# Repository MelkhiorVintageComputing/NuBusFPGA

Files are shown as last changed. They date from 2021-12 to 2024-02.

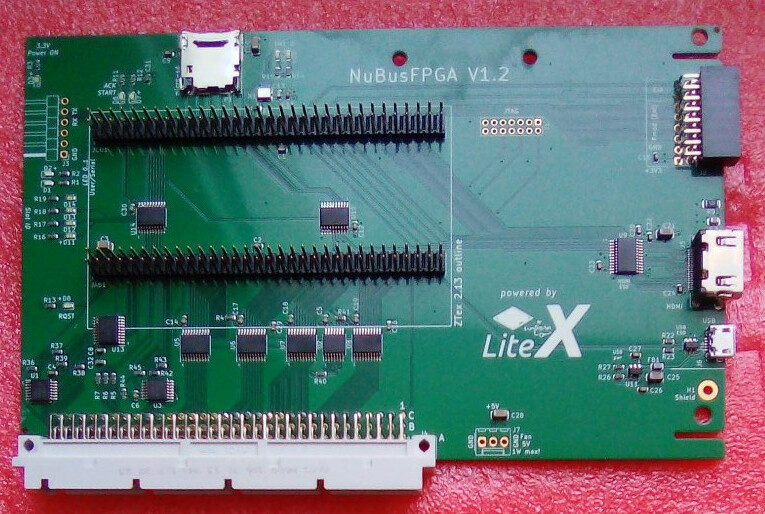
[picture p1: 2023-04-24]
Pictures/NuBusFPGA_V1_2.jpg

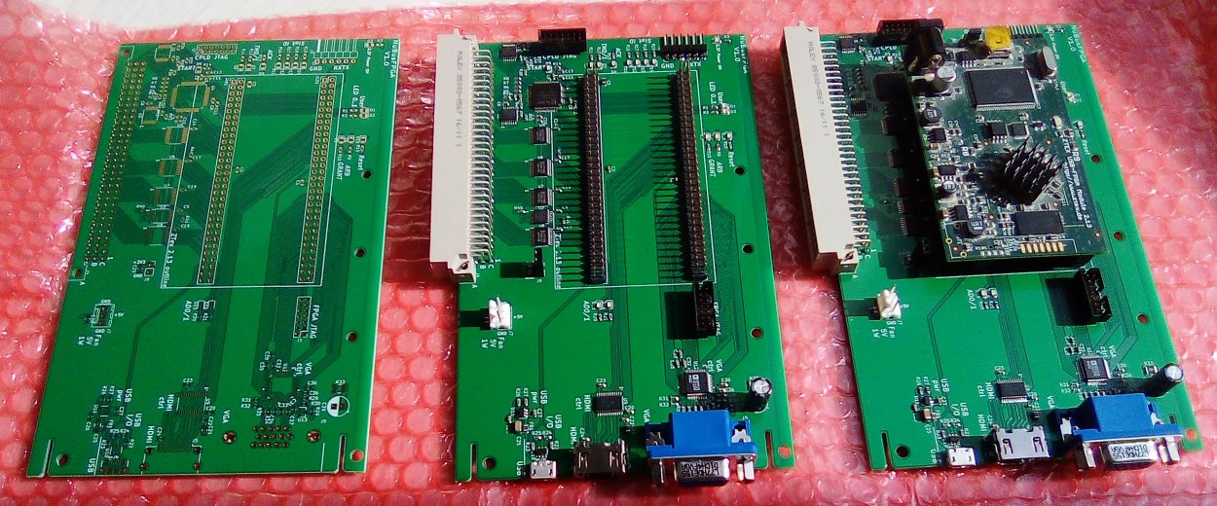
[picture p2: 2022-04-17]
Pictures/NuBusFPGA_V1_0.jpg

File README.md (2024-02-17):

# A FPGA on a NuBus card...

## Goal

The goal of this repository is to be able to interface a modern (2021 era) [FPGA](https://en.wikipedia.org/wiki/Field-programmable_gate_array) with a [NuBus](https://en.wikipedia.org/wiki/NuBus) host, specifically Apple's [Macintosh II](https://en.wikipedia.org/wiki/Macintosh_II_family) and [Macintosh Quadra](https://en.wikipedia.org/wiki/Macintosh_Quadra). NuBus was widely used by Apple and a little by others (such as NeXT), but was progressively displaced by PCI from the mid-90s onward, and is thoroughly obsolete.

So unless you're a retrocomputing enthusiast with such a machine, this is useless. If you are such an enthusiast, then maybe the ability to connect a modern LCD monitor using a digital interface to an old Macintosh might be of interest to you.

This project was 'spun off' the [SBusFPGA](https://github.com/rdolbeau/SBusFPGA), a similar project for the SBus used in Sun's SPARCstation.

## Current status

First prototype is working in a Quadra 650, running MacOS 8.1. It implements a single-screen-resolution, windowboxed multi-resolution, depth-switchable (1/2/4/8/16/32 bits) framebuffer over DVI-in-HDMI-connector (will work with any HDMI-compliant monitor). The framebuffer can be used as secondary/primary/only framebuffer in the machine running OS8.1. Qemu tests indicate this should work with 7.1 & 7.5/7.6 as well. An alternate HDMI PHY also supports audio, enabled as a 8/16 bits, mono/stereo, 44.1 kHz output component in MacOS.

Some basic acceleration now exists for 8/16/32 bits, doing rectangle screen-to-screen blits and pattern rectangle fills. 1/2/4 bits also has some acceleration, but only for byte-aligned cases.

There's also a basic RAM Disk using the 248 MiB of SDRAM not used by the framebuffer. The driver can use either synchronous direct access to the memory by the CPU, or asynchronous using DMA (using 16-bytes blocks). Frustratingly, the direct access methode seems faster.

## The hardware

Directory 'nubus-to-ztex'

The (now obsolete) V1.0 custom board is a NuBus-compliant (I hope...) board, designed to receive a [ZTex USB-FPGA Module 2.13](https://www.ztex.de/usb-fpga-2/usb-fpga-2.13.e.html) as a daughterboard. The ZTex module contains the actual FPGA (Artix-7), some RAM, programming hardware, etc. The NuBus board contains level-shifters & drivers ICs to interface between the NuBus signals and the FPGA, a CPLD handling some level-shifting & the bus mastering arbitration, a serial header, two user Leds, 14 debug Leds tied to specific NuBus or CPLD/FPGA signals, a JTAG header, a USB micro-B connector, a VGA chip & connector, and a HDMI chip & connector. It supports every NuBus feature except the optional parity (i.e. it can do both slave and master modes). The V1.0 board is in commit 3f3371a. The CPLD solution works but is annoying as it requires older Xilinx software (ISE 14.7) and dedicated JTAG programmer to use.

The current board is V1.2. It drops the CPLD and VGA port. Bus arbitration is now done inside the FPGA. It gains a micro-sd slot, and a custom expansion connector that is based (and compatible with, with more signals) PMod. It supports the same accelerated HDMI framebuffer and RAM Disk. Optionally, The Declaration Rom can be stored in a Flash NOR chip connected ot the PMOd expansion connector (easier for working on embedded driver in the DeclRom). The ROM can alternately be stored in a sector of the config flash from the ZTex board on any *FPGA.

The new (July 2023) [ZTex USB-FPGA Module 2.12](https://www.ztex.de/usb-fpga-2/usb-fpga-2.12.e.html) is theoretically compatible with all *FPGA, but at this stage there is some issue when using the 2.12b I own. Some further tests are planned.

The PCBs were designed with Kicad 5.1

## The gateware (Migen)

Directory 'sbus-to-ztex-gateware'

The gateware is written in the Migen language, choosen because that's what [Litex](https://github.com/enjoy-digital/litex/) uses.
It implements a simple CPU-less Litex SoC built around a Wishbone bus, with a custom bridge between the NuBus and the Wishbone.

A Declaration ROM, a SDRAM controller ([litedram](https://github.com/enjoy-digital/litedram) to the on-board DDR3), and the 'Goblin' multi-depth framebuffer can be connected to that bus. Other devices could be added, see the SBusFPGA or the [Common](https://github.com/rdolbeau/VintageBusFPGA_Common) directory, but the software support is missing; vintage System 7/MacOS 8 are not as welcoming to new devices as modern NetBSD. Theoretically, quite a bit of code originally written to support the SBusFPGA in NetBSD/sparc could be reused for similar devices in NetBSD/mac68k, but it has not happened yet.

The SDRAM has its own custom DMA controller, using native Litedram interface to the memory, and some FIFO to/from the NuBus. A custom MacOS driver exposes it as a volatile drive. Driver can use synchronous direct accesses from the CPU (using the NuBus's superslot area), or asynchronous (interrupt-driven) DMA transfers using NuBus 1x block transfers.

## The software

The Declaration ROM is in the subdirectory VintageBusFPGA_Common/DeclROM and includes the driver needed for the unaccelerated framebuffer and the RAM Disk. It needs the [Retro68](https://github.com/autc04/Retro68) toolchain to build.

The code for the NuBusFPGAInit (which should be renamed and enables acceleration) is in NuBusFPGAInit/, and will need a CodeWarrior INIT project to build, on a real Macintosh or an emulated one using e.g. Qemu. It enables graphic acceleration.

The code for the Audio component (which enables audio support over HDMI when using the alternate PHY) is in NuBusFPGAHDMIAudio/.

## FAQ

* Can the framebuffer change resolution ?
 Yes and no. The gateware has a default resolution baked into it that the device will use by default, and can use one of two different physical interface (PHY): the Litex-derived one (which uses DVI signalling) or a more HDMI-like one in verilog. "windowboxed" mode is always availeble, where a smaller esolution is displayed in the middle of the larger screen, which you can select in System 7/MacOS 8 with the Monitor control panel. When using the Litex PHY, some resolution are also available as "hardware" resolution, outputing the appropriate signalling - but the Litex PHY doesn't support audio. The alternate PHY does support audio, but doesn't allow to use a different output resolution, only Full HD (1920x1080) and does support audio output.

* Is Audio supported ?
 Yes and no. a 8 or 16-bits, audio or stereo, 44.1 KHz audio device is available but nly when using the alternate HDMI PHY (see previous question)

* Is USB supported ?
 No. There is a USB connector, but it is currently useless. The gateware could include a USB OHCI host device, and that is supported in the SBusFPGA under NetBSD. However, no Apple OS running on a 68k Mac has any support for USB, so it would require an entire USB stack to be ported, which is a huge undertaking. Also, NuBus is quite a slow bus even by early 2000s standard, and USB OHCI does a lot of DMA all the time, which would use up most if not all (or maybe more than all!) the available bandwidth. There might be some support in NetBSD/mac68k eventually just to test feasibility, but it even there it's unlikely to be useful.

* Is micro-sd supported ?
 Not yet. Hopefully at some point the micro-sd card will be usable as permanent storage in System 7/MacOS 8, but so far it's not working.

* Where is the ROM stored ?
 By default the Declaration ROM is stored inside the FPGA bitstream, so the bitstream must be regenerated for every ROM change. It is possible to store it in a [SPI](https://en.wikipedia.org/wiki/Serial_Peripheral_Interface) Flash NOR chip instead, connected via the expansion connector ([PMod](https://digilent.com/reference/pmod/start)-like) at the back of the NuBusFPGA. My own PMod featuring a SPI Flash NOR and an I2C temperature monitoris available in the [VintageBusFPGA_Common](https://github.com/rdolbeau/VintageBusFPGA_Common) repository, along with an adapter board to program the SPI FLash NOR through the SPI interface of a Raspberry Pi and [flashrom](https://www.flashrom.org/Flashrom).

* Is I2C supported ?
 No. Like USB, I2C doesn't have support in System 7/MacOS 8. It's a lot simpler than USB though. Reading values from a lm75-compatible temperature monitor from System 7/MacOS 8 might be doable, but isn't currently planned. Support for NetBSD/mac68k should be reasonably easy to add as it's already supported in NetBSD/sparc for the SBusFPGA, and unlike USB there's no issue with bandwidth-hungry DMA.

* How about adding Ethernet ?
 Software is the issue. Ethernet is supported by the gateware infrastructure, and a prototype design to add Fast Ethernet via RMII through the expansion connector is available. However, there is currently no software support for it. There's some documentation from Apple, and there's [an example driver available](http://www.mactcp.org.nz/ethernet.html), but the System 7/MacOS 8 driver for LiteEth is still to be written.
 The [SEthernet](https://github.com/rhalkyard/SEthernet) project is a much more likely source of Ethernet for '030-based system.

* Why slow NuBus, when PDS is so much faster ?
 NuBus is well documented, and electrically quite isolated from the rest of the machine. Safer to play with than PDS which is directly connected to the CPU. And the connector for it it still in general use and easy to get. And NuBus is available on multiple generations of machines.
 My primary machine for this is a Quadra 650, with a 68040 and the associated PDS. Unfortunately, the connector for that PDS is near impossible to get nowadadays ([specifications are there](https://tinkerdifferent.com/resources/specifications-for-the-quadra-pds-connector.124/)). '030 PDS uses 120-pins DIN 41612, similar to bur larger than NuBus' 96-pins. They are also available, but less common. But there is a catch - although sharing a connector board-side, the IIsi, SE/30 and IIfx pinouts are slightly different. And the LCIII is completely different.
 Also - see [IIsiFPGA](https://github.com/rdolbeau/IIsiFPGA) and [QuadraFPGA](https://github.com/rdolbeau/QuadraFPGA) :-)

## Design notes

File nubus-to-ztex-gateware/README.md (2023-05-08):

# Compiling

## Rom

Compiling the Declaration Rom (in DeclRom) requires the [Retro68](https://github.com/autc04/Retro68) toolchain.

The beginning of the Makefile in DeclROM/ needs to be adapted to point to the toolchain.

## Microcode for acceleration

Compiling the acceleration code for the Framebuffer requires a RISC-V toolchain.

The script blit_goblin_nubus.sh in VintageBusFPGA_Common/ needs to be adapted to point to the appropriate toolchain.

## Bitstream

Generating the bitstream requires Vivado, 2022 or newer should do. It also requires Litex, see for instance [Linux-on-Litex-VexRiscv](https://github.com/litex-hub/linux-on-litex-vexriscv).

You will need LItex working, and an usable Vivado in yout $PATH.

## Known issues

### dependencies

There's an interesting issue where you need the DeclRom to generate the bitstream (by defualt the Rom is emebedded in it), but you need CSR headers created during the generation of the bitstream to compile the Declaration Rom. A simple workaround is to create a Rom file with a kilobyte or two of fake data, generate the bitstream, then compile the declaration rom, then re-generate the bitsteam with the proper Rom.

### timings

While the main part of the design should be fine in terms of timings, some of the HDMI part isn't. At FullHD resolution (1920x1080 @ 60Hz)), It is 'normal' to have -0.808ns of WPWS, with 9 endpoints failing, in the hdmi5x_clk domain. It doesn't seem to affect the display. This is using the V1.2 54 MHz clock to Bank 34; using the primary 48 MHz clock instead (as in V1.0), the hdmi_clk is a 148.8 MHz instead of 148.5 and the WPPS is -0.811 instead (the 5x clock is at 744 Mhz instead of 742.5 MHz).

### physical

The HDMI connector is low-riding on the PCB. The Mac case gets in the the HDMI plug from the cable, thus pushing the NuBusFPGA slightly out of verticality.

Also when plugging a PMod in the PMod connector, the soldered through-hole pins are dangerously close of the Mac shielding. An extra layer of insulation is recommended to avoid short-circuit.

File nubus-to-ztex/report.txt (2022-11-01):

Info: Front side (top side) place file: “/home/dolbeau/MAC/NuBusFPGA.V1_2/nubus-to-ztex/nubus-to-ztex-top.pos”.
Info: Component count: 88.
Info: Back side (bottom side) place file: “/home/dolbeau/MAC/NuBusFPGA.V1_2/nubus-to-ztex/nubus-to-ztex-bottom.pos”.
Info: Component count: 0.
Info: Full component count: 88

Component Placement File generation OK.

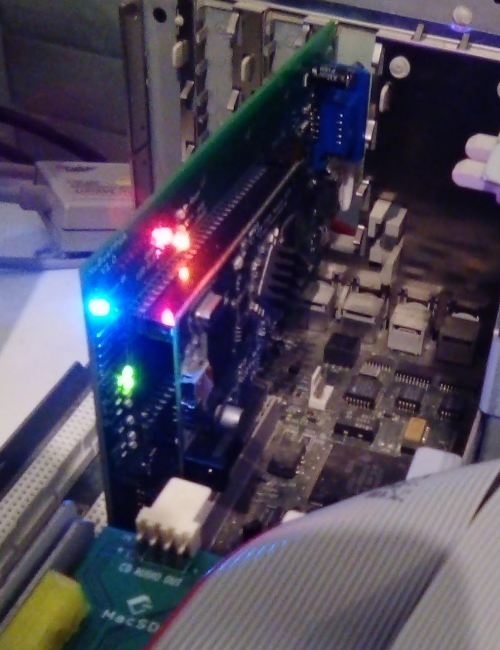
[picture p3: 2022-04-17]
Pictures/NuBusFPGA_V1_0_in_Q650.jpg

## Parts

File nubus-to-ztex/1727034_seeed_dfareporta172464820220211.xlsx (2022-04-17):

Seeed DFA report
Project Name： |  | Prepared by: Qiaoyu Lin |  |  |  | Date: 20220211
Item | Problem description 问题描述 | Reference location 影响位置 | Impact 影响 | Image 图片 | Seeed Suggestion 矽递建议 | Customer feedback 客户反馈 | Severity 严重度 | Status 状态
1 | There is missing the holes in the Gerber | J1,J2 | couldn't be solder in the boards |  | Please update the Gerber to match with the datasheet |  | High | open
2 | The clearance between the holes are not match with the datasheet | J9 | couldn't be solder in the boards |  | Please update the Gerber to match with the datasheet |  | High | open
3 | There is not solder mask layer in the bottom | bottom solder mask layer | couldn't sure how to apply the solder mask oil |  | Please add it in the Gerber |  | High | open
4 |  |  |  |  |  |  | Middle | open
5 |  |  |  |  |  |  | Middle | open
6 |  |  |  |  |  |  | Middle | open
7 |  |  |  |  |  |  | Middle | open
8 |  |  |  |  |  |  | Middle | open

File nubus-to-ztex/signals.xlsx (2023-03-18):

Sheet: Summary
Connector PIN | USB-FPGA-Module 2.13 |  |  |  |  |  |  |  |  |  |  |  |  |  |  |  |  |  |  |  |  |  |  |  |  |  |  |  | LITEX def
 | Signal | I/O Voltage | FPGA PIN | CPLD PIN | Notes | Number |  | Used Pin | Signal | 2.13 trace length (mm) | added length |  |  |  |  |  |  | XDC PIN | XDC TIMING IN | DXC TIMING OUT |  | https://forums.xilinx.com/t5/Timing-Analysis/Significance-of-set-output-delay-max-min-negative-and-positive/td-p/779277
A1 | VIN |  |  |  | 4.5..16V | 1 | #VALUE! | VIN | #VALUE!
B1 | VIN |  |  |  | 4.5..16V | 2 | #VALUE! | VIN | #VALUE! |  |  |  |  |  |  |  |  | TIS (min) → ?? | 48 | 52 | TOD (max) → Ton+Tpd | 22.5 in B0
A2 | GND |  |  |  |  | 3 | #VALUE! | GND | #VALUE! |  |  |  |  |  |  |  | 0 in B0 | TIH (min) → ??? | 2.5 | 7 | TOH (min) → ??? |  | #N/A
B2 | GND |  |  |  |  | 4 | #VALUE! | GND | #VALUE! |  |  |  |  |  |  |  |  |  | mm/ns (fast so MIN) | mm/ns (slow so MAX) |  |  | 0.2161759631
 |  |  |  |  |  |  | #VALUE! |  |  |  |  |  |  |  |  |  |  |  | 200 | 150
A3 | K16~IO_25_15 | VCCO_AB | K16 |  |  | 5 | nmrq_n | K16~IO_25_15 | nmrq_n | 47.94 | #N/A |  | #N/A | #N/A |  | #N/A | IO | set_property PACKAGE_PIN K16 [get_ports {nmrq_n}] set_property IOSTANDARD LVTTL [get_ports {nmrq_n}]
B3 | J18~IO_L23N_T3_FWE_B_15 | VCCO_AB | J18 |  |  | 6 | rqst_n | J18~IO_L23N_T3_FWE_B_15 | rqst_n | 47.46 | 52.47 |  | 99.93 | 3.93 |  | -30.84 | O | set_property PACKAGE_PIN J18 [get_ports {rqst_n}] set_property IOSTANDARD LVTTL [get_ports {rqst_n}] | set_input_delay -clock clk_3v3_n -min 2.404 [get_ports {rqst_n}] set_input_delay -clock clk_3v3_n -max 52.456 [get_ports {rqst_n}] | set_output_delay -clock clk_3v3_n -min -6.155 [get_ports {rqst_n}] set_output_delay -clock clk_3v3_n -max 53.627 [get_ports {rqst_n}] |  | set_output_delay -clock clk_3v3_n -min -6.155 [get_ports {rqst_n}] set_output_delay -clock clk_3v3_n -max 53.627 [get_ports {rqst_n}]
A4 | K15~IO_L24P_T3_RS1_15 | VCCO_AB | K15 |  |  | 7 | start_n | K15~IO_L24P_T3_RS1_15 | start_n | 50.82 | 59.68 |  | 110.50 | 4.35 |  | -41.40 | IO | set_property PACKAGE_PIN K15 [get_ports {start_n}] set_property IOSTANDARD LVTTL [get_ports {start_n}] | set_input_delay -clock clk_3v3_n -min 2.457 [get_ports {start_n}] set_input_delay -clock clk_3v3_n -max 52.526 [get_ports {start_n}] | set_output_delay -clock clk_3v3_n -min -6.102 [get_ports {start_n}] set_output_delay -clock clk_3v3_n -max 53.697 [get_ports {start_n}] |  | set_input_delay -clock clk_3v3_n -min 2.457 [get_ports {start_n}] set_input_delay -clock clk_3v3_n -max 52.526 [get_ports {start_n}] set_output_delay -clock clk_3v3_n -min -6.102 [get_ports {start_n}] set_output_delay -clock clk_3v3_n -max 53.697 [get_ports {start_n}]
B4 | J17~IO_L23P_T3_FOE_B_15 | VCCO_AB | J17 |  |  | 8 | ack_n | J17~IO_L23P_T3_FOE_B_15 | ack_n | 43.6 | 80.52 |  | 124.12 | 4.89 |  | -55.02 | IO | set_property PACKAGE_PIN J17 [get_ports {ack_n}] set_property IOSTANDARD LVTTL [get_ports {ack_n}] | set_input_delay -clock clk_3v3_n -min 2.525 [get_ports {ack_n}] set_input_delay -clock clk_3v3_n -max 52.617 [get_ports {ack_n}] | set_output_delay -clock clk_3v3_n -min -6.034 [get_ports {ack_n}] set_output_delay -clock clk_3v3_n -max 53.788 [get_ports {ack_n}] |  | set_input_delay -clock clk_3v3_n -min 2.525 [get_ports {ack_n}] set_input_delay -clock clk_3v3_n -max 52.617 [get_ports {ack_n}] set_output_delay -clock clk_3v3_n -min -6.034 [get_ports {ack_n}] set_output_delay -clock clk_3v3_n -max 53.788 [get_ports {ack_n}]
A5 | J15~IO_L24N_T3_RS0_15 | VCCO_AB | J15 |  |  | 9 | start_oe_n | J15~IO_L24N_T3_RS0_15 | start_oe_n | 49.92 | #N/A |  | #N/A | #N/A |  | #N/A | IO | set_property PACKAGE_PIN J15 [get_ports {start_oe_n}] set_property IOSTANDARD LVTTL [get_ports {start_oe_n}]
B5 | K13~IO_L17P_T2_A26_15 | VCCO_AB | K13 |  |  | 10 | rqst_o_n | K13~IO_L17P_T2_A26_15 | rqst_o_n | 50.53 | #N/A |  | #N/A | #N/A |  | #N/A | IO | set_property PACKAGE_PIN K13 [get_ports {rqst_o_n}] set_property IOSTANDARD LVTTL [get_ports {rqst_o_n}]
A6 | H15~IO_L19N_T3_A21_VREF_15 | VCCO_AB | H15 |  | VREF Bank 15 | 11 | start_o_n | H15~IO_L19N_T3_A21_VREF_15 | start_o_n | 46.16 | #N/A |  | #N/A | #N/A |  | #N/A | I | set_property PACKAGE_PIN H15 [get_ports {start_o_n}] set_property IOSTANDARD LVTTL [get_ports {start_o_n}]
B6 | J13~IO_L17N_T2_A25_15 | VCCO_AB | J13 |  |  | 12 | ack_oe_n | J13~IO_L17N_T2_A25_15 | ack_oe_n | 43.56 | #N/A |  | #N/A | #N/A |  | #N/A | O | set_property PACKAGE_PIN J13 [get_ports {ack_oe_n}] set_property IOSTANDARD LVTTL [get_ports {ack_oe_n}]
A7 | J14~IO_L19P_T3_A22_15 | VCCO_AB | J14 |  |  | 13 | arb_o_n0 | J14~IO_L19P_T3_A22_15 | arb_o_n0 | 41.01 | #N/A |  | #N/A | #N/A |  | #N/A | IO | set_property PACKAGE_PIN J14 [get_ports {arb_o_n0}] set_property IOSTANDARD LVTTL [get_ports {arb_o_n0}]
B7 | H14~IO_L15P_T2_DQS_15 | VCCO_AB | H14 |  |  | 14 | ack_o_n | H14~IO_L15P_T2_DQS_15 | ack_o_n | 41.18 | #N/A |  | #N/A | #N/A |  | #N/A | IO | set_property PACKAGE_PIN H14 [get_ports {ack_o_n}] set_property IOSTANDARD LVTTL [get_ports {ack_o_n}]
A8 | H17~IO_L18P_T2_A24_15 | VCCO_AB | H17 |  |  | 15 | arb_o_n3 | H17~IO_L18P_T2_A24_15 | arb_o_n3 | 36.34 | #N/A |  | #N/A | #N/A |  | #N/A | IO | set_property PACKAGE_PIN H17 [get_ports {arb_o_n3}] set_property IOSTANDARD LVTTL [get_ports {arb_o_n3}]
B8 | G14~IO_L15N_T2_DQS_ADV_B_15 | VCCO_AB | G14 |  |  | 16 | arb_o_n2 | G14~IO_L15N_T2_DQS_ADV_B_15 | arb_o_n2 | 38.13 | #N/A |  | #N/A | #N/A |  | #N/A | IO | set_property PACKAGE_PIN G14 [get_ports {arb_o_n2}] set_property IOSTANDARD LVTTL [get_ports {arb_o_n2}]
A9 | G17~IO_L18N_T2_A23_15 | VCCO_AB | G17 |  |  | 17 | NUBUS_AD_DIR | G17~IO_L18N_T2_A23_15 | NUBUS_AD_DIR | 35.18 | #N/A |  | #N/A | #N/A |  | #N/A | I | set_property PACKAGE_PIN G17 [get_ports {NUBUS_AD_DIR}] set_property IOSTANDARD LVTTL [get_ports {NUBUS_AD_DIR}]
B9 | G16~IO_L13N_T2_MRCC_15 | VCCO_AB | G16 |  | MRCC | 18 | arb_o_n1 | G16~IO_L13N_T2_MRCC_15 | arb_o_n1 | 33.55 | #N/A |  | #N/A | #N/A |  | #N/A | IO | set_property PACKAGE_PIN G16 [get_ports {arb_o_n1}] set_property IOSTANDARD LVTTL [get_ports {arb_o_n1}]
A10 | G18~IO_L22P_T3_A17_15 | VCCO_AB | G18 |  |  | 19 | ad_n31 | G18~IO_L22P_T3_A17_15 | ad_n31 | 31.47 | 35.03 |  | 66.50 | 2.62 |  | 2.60 | IO | set_property PACKAGE_PIN G18 [get_ports {ad_n31}] set_property IOSTANDARD LVTTL [get_ports {ad_n31}] | set_input_delay -clock clk_3v3_n -min 2.237 [get_ports {ad_n31}] set_input_delay -clock clk_3v3_n -max 52.233 [get_ports {ad_n31}] | set_output_delay -clock clk_3v3_n -min -6.322 [get_ports {ad_n31}] set_output_delay -clock clk_3v3_n -max 53.404 [get_ports {ad_n31}] |  | set_input_delay -clock clk_3v3_n -min 2.237 [get_ports {ad_n31}] set_input_delay -clock clk_3v3_n -max 52.233 [get_ports {ad_n31}] set_output_delay -clock clk_3v3_n -min -6.322 [get_ports {ad_n31}] set_output_delay -clock clk_3v3_n -max 53.404 [get_ports {ad_n31}]
B10 | H16~IO_L13P_T2_MRCC_15 | VCCO_AB | H16 |  | MRCC | 20 | clk_n | H16~IO_L13P_T2_MRCC_15 | clk_n | 30.82 | 38.28 |  | 69.10 | 2.72 |  | 0.00 | I | set_property PACKAGE_PIN H16 [get_ports {clk_n}] set_property IOSTANDARD LVTTL [get_ports {clk_n}] | set_input_delay -clock clk_3v3_n -min 2.250 [get_ports {clk_n}] set_input_delay -clock clk_3v3_n -max 52.250 [get_ports {clk_n}] | set_output_delay -clock clk_3v3_n -min -6.309 [get_ports {clk_n}] set_output_delay -clock clk_3v3_n -max 53.421 [get_ports {clk_n}] |  | set_input_delay -clock clk_3v3_n -min 2.250 [get_ports {clk_n}] set_input_delay -clock clk_3v3_n -max 52.250 [get_ports {clk_n}]
A11 | F18~IO_L22N_T3_A16_15 | VCCO_AB | F18 |  |  | 21 | ad_n29 | F18~IO_L22N_T3_A16_15 | ad_n29 | 29.79 | 35.03 |  | 64.82 | 2.55 |  | 4.28 | IO | set_property PACKAGE_PIN F18 [get_ports {ad_n29}] set_property IOSTANDARD LVTTL [get_ports {ad_n29}] | set_input_delay -clock clk_3v3_n -min 2.229 [get_ports {ad_n29}] set_input_delay -clock clk_3v3_n -max 52.221 [get_ports {ad_n29}] | set_output_delay -clock clk_3v3_n -min -6.330 [get_ports {ad_n29}] set_output_delay -clock clk_3v3_n -max 53.393 [get_ports {ad_n29}] |  | set_input_delay -clock clk_3v3_n -min 2.229 [get_ports {ad_n29}] set_input_delay -clock clk_3v3_n -max 52.221 [get_ports {ad_n29}] set_output_delay -clock clk_3v3_n -min -6.330 [get_ports {ad_n29}] set_output_delay -clock clk_3v3_n -max 53.393 [get_ports {ad_n29}]
B11 | F16~IO_L14N_T2_SRCC_15 | VCCO_AB | F16 |  | SRCC | 22 | ad_n30 | F16~IO_L14N_T2_SRCC_15 | ad_n30 | 42.85 | 32.71 |  | 75.56 | 2.97 |  | -6.46 | IO | set_property PACKAGE_PIN F16 [get_ports {ad_n30}] set_property IOSTANDARD LVTTL [get_ports {ad_n30}] | set_input_delay -clock clk_3v3_n -min 2.282 [get_ports {ad_n30}] set_input_delay -clock clk_3v3_n -max 52.293 [get_ports {ad_n30}] | set_output_delay -clock clk_3v3_n -min -6.277 [get_ports {ad_n30}] set_output_delay -clock clk_3v3_n -max 53.464 [get_ports {ad_n30}] |  | set_input_delay -clock clk_3v3_n -min 2.282 [get_ports {ad_n30}] set_input_delay -clock clk_3v3_n -max 52.293 [get_ports {ad_n30}] set_output_delay -clock clk_3v3_n -min -6.277 [get_ports {ad_n30}] set_output_delay -clock clk_3v3_n -max 53.464 [get_ports {ad_n30}]
A12 | E18~IO_L21P_T3_DQS_15 | VCCO_AB | E18 |  |  | 23 | ad_n27 | E18~IO_L21P_T3_DQS_15 | ad_n27 | 28.44 | 35.41 |  | 63.85 | 2.51 |  | 5.25 | IO | set_property PACKAGE_PIN E18 [get_ports {ad_n27}] set_property IOSTANDARD LVTTL [get_ports {ad_n27}] | set_input_delay -clock clk_3v3_n -min 2.224 [get_ports {ad_n27}] set_input_delay -clock clk_3v3_n -max 52.215 [get_ports {ad_n27}] | set_output_delay -clock clk_3v3_n -min -6.335 [get_ports {ad_n27}] set_output_delay -clock clk_3v3_n -max 53.386 [get_ports {ad_n27}] |  | set_input_delay -clock clk_3v3_n -min 2.224 [get_ports {ad_n27}] set_input_delay -clock clk_3v3_n -max 52.215 [get_ports {ad_n27}] set_output_delay -clock clk_3v3_n -min -6.335 [get_ports {ad_n27}] set_output_delay -clock clk_3v3_n -max 53.386 [get_ports {ad_n27}]
B12 | F15~IO_L14P_T2_SRCC_15 | VCCO_AB | F15 |  | SRCC | 24 | ad_n28 | F15~IO_L14P_T2_SRCC_15 | ad_n28 | 26.76 | 32.71 |  | 59.47 | 2.34 |  | 9.63 | IO | set_property PACKAGE_PIN F15 [get_ports {ad_n28}] set_property IOSTANDARD LVTTL [get_ports {ad_n28}] | set_input_delay -clock clk_3v3_n -min 2.202 [get_ports {ad_n28}] set_input_delay -clock clk_3v3_n -max 52.186 [get_ports {ad_n28}] | set_output_delay -clock clk_3v3_n -min -6.357 [get_ports {ad_n28}] set_output_delay -clock clk_3v3_n -max 53.357 [get_ports {ad_n28}] |  | set_input_delay -clock clk_3v3_n -min 2.202 [get_ports {ad_n28}] set_input_delay -clock clk_3v3_n -max 52.186 [get_ports {ad_n28}] set_output_delay -clock clk_3v3_n -min -6.357 [get_ports {ad_n28}] set_output_delay -clock clk_3v3_n -max 53.357 [get_ports {ad_n28}]
A13 | D18~IO_L21N_T3_DQS_A18_15 | VCCO_AB | D18 |  |  | 25 | ad_n25 | D18~IO_L21N_T3_DQS_A18_15 | ad_n25 | 25.47 | 36.46 |  | 61.93 | 2.44 |  | 7.17 | IO | set_property PACKAGE_PIN D18 [get_ports {ad_n25}] set_property IOSTANDARD LVTTL [get_ports {ad_n25}] | set_input_delay -clock clk_3v3_n -min 2.214 [get_ports {ad_n25}] set_input_delay -clock clk_3v3_n -max 52.202 [get_ports {ad_n25}] | set_output_delay -clock clk_3v3_n -min -6.345 [get_ports {ad_n25}] set_output_delay -clock clk_3v3_n -max 53.374 [get_ports {ad_n25}] |  | set_input_delay -clock clk_3v3_n -min 2.214 [get_ports {ad_n25}] set_input_delay -clock clk_3v3_n -max 52.202 [get_ports {ad_n25}] set_output_delay -clock clk_3v3_n -min -6.345 [get_ports {ad_n25}] set_output_delay -clock clk_3v3_n -max 53.374 [get_ports {ad_n25}]
B13 | E17~IO_L16P_T2_A28_15 | VCCO_AB | E17 |  |  | 26 | ad_n26 | E17~IO_L16P_T2_A28_15 | ad_n26 | 23.54 | 33.39 |  | 56.93 | 2.24 |  | 12.17 | IO | set_property PACKAGE_PIN E17 [get_ports {ad_n26}] set_property IOSTANDARD LVTTL [get_ports {ad_n26}] | set_input_delay -clock clk_3v3_n -min 2.189 [get_ports {ad_n26}] set_input_delay -clock clk_3v3_n -max 52.169 [get_ports {ad_n26}] | set_output_delay -clock clk_3v3_n -min -6.370 [get_ports {ad_n26}] set_output_delay -clock clk_3v3_n -max 53.340 [get_ports {ad_n26}] |  | set_input_delay -clock clk_3v3_n -min 2.189 [get_ports {ad_n26}] set_input_delay -clock clk_3v3_n -max 52.169 [get_ports {ad_n26}] set_output_delay -clock clk_3v3_n -min -6.370 [get_ports {ad_n26}] set_output_delay -clock clk_3v3_n -max 53.340 [get_ports {ad_n26}]
A14 | G13~IO_0_15 | VCCO_AB | G13 |  |  | 27 | nubus_oe | G13~IO_0_15 | nubus_oe | 33.51 | #N/A |  | #N/A | #N/A |  | #N/A | IO | set_property PACKAGE_PIN G13 [get_ports {nubus_oe }] set_property IOSTANDARD LVTTL [get_ports {nubus_oe }]
B14 | D17~IO_L16N_T2_A27_15 | VCCO_AB | D17 |  |  | 28 | ad_n24 | D17~IO_L16N_T2_A27_15 | ad_n24 | 21.66 | 34.44 |  | 56.10 | 2.21 |  | 12.99 | IO | set_property PACKAGE_PIN D17 [get_ports {ad_n24}] set_property IOSTANDARD LVTTL [get_ports {ad_n24}] | set_input_delay -clock clk_3v3_n -min 2.185 [get_ports {ad_n24}] set_input_delay -clock clk_3v3_n -max 52.163 [get_ports {ad_n24}] | set_output_delay -clock clk_3v3_n -min -6.374 [get_ports {ad_n24}] set_output_delay -clock clk_3v3_n -max 53.335 [get_ports {ad_n24}] |  | set_input_delay -clock clk_3v3_n -min 2.185 [get_ports {ad_n24}] set_input_delay -clock clk_3v3_n -max 52.163 [get_ports {ad_n24}] set_output_delay -clock clk_3v3_n -min -6.374 [get_ports {ad_n24}] set_output_delay -clock clk_3v3_n -max 53.335 [get_ports {ad_n24}]
A15 | 3.3V |  |  |  |  | 29 |  | 3.3V | 0 |  | #N/A |  |  | 0.00 |  |  |  | set_property PACKAGE_PIN [get_ports {0}] set_property IOSTANDARD LVTTL [get_ports {0}]
B15 | 3.3V |  |  |  |  | 30 | #VALUE! | 3.3V | #VALUE! |  | #VALUE! |  |  | 0.00 |  |  |  | #VALUE! | #VALUE! | #VALUE! |  |  |  |  |  |  |  |  | #VALUE!
A16 | GND |  |  |  |  | 31 | #VALUE! | GND | #VALUE! |  | #VALUE! |  |  | 0.00 |  |  |  | #VALUE! | #VALUE! | #VALUE! |  |  |  |  |  |  |  |  | #VALUE!
B16 | GND |  |  |  |  | 32 | #VALUE! | GND | #VALUE! |  | #VALUE! |  |  | 0.00 |  |  |  | #VALUE! | #VALUE! | #VALUE! |  |  |  |  |  |  |  |  | #VALUE!
A17 | VCCO_AB |  |  |  | default: 3.3V output, if R8 removed: 1.2V .. 3.3V input | 33 | #VALUE! | VCCO_AB | #VALUE! |  | #VALUE! |  |  | 0.00 |  |  |  | #VALUE! | #VALUE! | #VALUE! |  |  |  |  |  |  |  |  | #VALUE!
B17 | VCCO_AB |  |  |  | default: 3.3V output, if R8 removed: 1.2V .. 3.3V input | 34 | #VALUE! | VCCO_AB | #VALUE! |  | #VALUE! |  |  | 0.00 |  |  |  | #VALUE! | #VALUE! | #VALUE! |  |  |  |  |  |  |  |  | #VALUE!
A18 | F13~IO_L5P_T0_AD9P_15 | VCCO_AB | F13 |  |  | 35 | ad_n23 | F13~IO_L5P_T0_AD9P_15 | ad_n23 | 19.12 | 38.45 |  | 57.57 | 2.27 |  | 11.53 | IO | set_property PACKAGE_PIN F13 [get_ports {ad_n23}] set_property IOSTANDARD LVTTL [get_ports {ad_n23}] | set_input_delay -clock clk_3v3_n -min 2.192 [get_ports {ad_n23}] set_input_delay -clock clk_3v3_n -max 52.173 [get_ports {ad_n23}] | set_output_delay -clock clk_3v3_n -min -6.367 [get_ports {ad_n23}] set_output_delay -clock clk_3v3_n -max 53.344 [get_ports {ad_n23}] |  | set_input_delay -clock clk_3v3_n -min 2.192 [get_ports {ad_n23}] set_input_delay -clock clk_3v3_n -max 52.173 [get_ports {ad_n23}] set_output_delay -clock clk_3v3_n -min -6.367 [get_ports {ad_n23}] set_output_delay -clock clk_3v3_n -max 53.344 [get_ports {ad_n23}]
B18 | F14~IO_L5N_T0_AD9N_15 | VCCO_AB | F14 |  |  | 36 | ad_n22 | F14~IO_L5N_T0_AD9N_15 | ad_n22 | 12.94 | 35.86 |  | 48.80 | 1.92 |  | 20.30 | IO | set_property PACKAGE_PIN F14 [get_ports {ad_n22}] set_property IOSTANDARD LVTTL [get_ports {ad_n22}] | set_input_delay -clock clk_3v3_n -min 2.149 [get_ports {ad_n22}] set_input_delay -clock clk_3v3_n -max 52.115 [get_ports {ad_n22}] | set_output_delay -clock clk_3v3_n -min -6.410 [get_ports {ad_n22}] set_output_delay -clock clk_3v3_n -max 53.286 [get_ports {ad_n22}] |  | set_input_delay -clock clk_3v3_n -min 2.149 [get_ports {ad_n22}] set_input_delay -clock clk_3v3_n -max 52.115 [get_ports {ad_n22}] set_output_delay -clock clk_3v3_n -min -6.410 [get_ports {ad_n22}] set_output_delay -clock clk_3v3_n -max 53.286 [get_ports {ad_n22}]
A19 | E16~IO_L11N_T1_SRCC_15 | VCCO_AB | E16 |  | SRCC | 37 | ad_n21 | E16~IO_L11N_T1_SRCC_15 | ad_n21 | 16.11 | 38.36 |  | 54.47 | 2.14 |  | 14.63 | IO | set_property PACKAGE_PIN E16 [get_ports {ad_n21}] set_property IOSTANDARD LVTTL [get_ports {ad_n21}] | set_input_delay -clock clk_3v3_n -min 2.177 [get_ports {ad_n21}] set_input_delay -clock clk_3v3_n -max 52.152 [get_ports {ad_n21}] | set_output_delay -clock clk_3v3_n -min -6.382 [get_ports {ad_n21}] set_output_delay -clock clk_3v3_n -max 53.324 [get_ports {ad_n21}] |  | set_input_delay -clock clk_3v3_n -min 2.177 [get_ports {ad_n21}] set_input_delay -clock clk_3v3_n -max 52.152 [get_ports {ad_n21}] set_output_delay -clock clk_3v3_n -min -6.382 [get_ports {ad_n21}] set_output_delay -clock clk_3v3_n -max 53.324 [get_ports {ad_n21}]
B19 | E15~IO_L11P_T1_SRCC_15 | VCCO_AB | E15 |  | SRCC | 38 | ad_n20 | E15~IO_L11P_T1_SRCC_15 | ad_n20 | 10.5 | 35.86 |  | 46.36 | 1.83 |  | 22.74 | IO | set_property PACKAGE_PIN E15 [get_ports {ad_n20}] set_property IOSTANDARD LVTTL [get_ports {ad_n20}] | set_input_delay -clock clk_3v3_n -min 2.136 [get_ports {ad_n20}] set_input_delay -clock clk_3v3_n -max 52.098 [get_ports {ad_n20}] | set_output_delay -clock clk_3v3_n -min -6.423 [get_ports {ad_n20}] set_output_delay -clock clk_3v3_n -max 53.270 [get_ports {ad_n20}] |  | set_input_delay -clock clk_3v3_n -min 2.136 [get_ports {ad_n20}] set_input_delay -clock clk_3v3_n -max 52.098 [get_ports {ad_n20}] set_output_delay -clock clk_3v3_n -min -6.423 [get_ports {ad_n20}] set_output_delay -clock clk_3v3_n -max 53.270 [get_ports {ad_n20}]
A20 | C17~IO_L20N_T3_A19_15 | VCCO_AB | C17 |  |  | 39 | ad_n19 | C17~IO_L20N_T3_A19_15 | ad_n19 | 12.52 | 38.40 |  | 50.92 | 2.00 |  | 18.18 | IO | set_property PACKAGE_PIN C17 [get_ports {ad_n19}] set_property IOSTANDARD LVTTL [get_ports {ad_n19}] | set_input_delay -clock clk_3v3_n -min 2.159 [get_ports {ad_n19}] set_input_delay -clock clk_3v3_n -max 52.129 [get_ports {ad_n19}] | set_output_delay -clock clk_3v3_n -min -6.400 [get_ports {ad_n19}] set_output_delay -clock clk_3v3_n -max 53.300 [get_ports {ad_n19}] |  | set_input_delay -clock clk_3v3_n -min 2.159 [get_ports {ad_n19}] set_input_delay -clock clk_3v3_n -max 52.129 [get_ports {ad_n19}] set_output_delay -clock clk_3v3_n -min -6.400 [get_ports {ad_n19}] set_output_delay -clock clk_3v3_n -max 53.300 [get_ports {ad_n19}]
B20 | C16~IO_L20P_T3_A20_15 | VCCO_AB | C16 |  |  | 40 | ad_n18 | C16~IO_L20P_T3_A20_15 | ad_n18 | 7.79 | 35.86 |  | 43.65 | 1.72 |  | 25.45 | IO | set_property PACKAGE_PIN C16 [get_ports {ad_n18}] set_property IOSTANDARD LVTTL [get_ports {ad_n18}] | set_input_delay -clock clk_3v3_n -min 2.123 [get_ports {ad_n18}] set_input_delay -clock clk_3v3_n -max 52.080 [get_ports {ad_n18}] | set_output_delay -clock clk_3v3_n -min -6.436 [get_ports {ad_n18}] set_output_delay -clock clk_3v3_n -max 53.252 [get_ports {ad_n18}] |  | set_input_delay -clock clk_3v3_n -min 2.123 [get_ports {ad_n18}] set_input_delay -clock clk_3v3_n -max 52.080 [get_ports {ad_n18}] set_output_delay -clock clk_3v3_n -min -6.436 [get_ports {ad_n18}] set_output_delay -clock clk_3v3_n -max 53.252 [get_ports {ad_n18}]
A21 | A18~IO_L10N_T1_AD11N_15 | VCCO_AB | A18 | q |  | 41 | ad_n17 | A18~IO_L10N_T1_AD11N_15 | ad_n17 | 11.42 | 38.62 |  | 50.04 | 1.97 |  | 19.06 | IO | set_property PACKAGE_PIN A18 [get_ports {ad_n17}] set_property IOSTANDARD LVTTL [get_ports {ad_n17}] | set_input_delay -clock clk_3v3_n -min 2.155 [get_ports {ad_n17}] set_input_delay -clock clk_3v3_n -max 52.123 [get_ports {ad_n17}] | set_output_delay -clock clk_3v3_n -min -6.404 [get_ports {ad_n17}] set_output_delay -clock clk_3v3_n -max 53.294 [get_ports {ad_n17}] |  | set_input_delay -clock clk_3v3_n -min 2.155 [get_ports {ad_n17}] set_input_delay -clock clk_3v3_n -max 52.123 [get_ports {ad_n17}] set_output_delay -clock clk_3v3_n -min -6.404 [get_ports {ad_n17}] set_output_delay -clock clk_3v3_n -max 53.294 [get_ports {ad_n17}]
B21 | B18~IO_L10P_T1_AD11P_15 | VCCO_AB | B18 |  |  | 42 | ad_n16 | B18~IO_L10P_T1_AD11P_15 | ad_n16 | 4.99 | 35.86 |  | 40.85 | 1.61 |  | 28.25 | IO | set_property PACKAGE_PIN B18 [get_ports {ad_n16}] set_property IOSTANDARD LVTTL [get_ports {ad_n16}] | set_input_delay -clock clk_3v3_n -min 2.109 [get_ports {ad_n16}] set_input_delay -clock clk_3v3_n -max 52.062 [get_ports {ad_n16}] | set_output_delay -clock clk_3v3_n -min -6.450 [get_ports {ad_n16}] set_output_delay -clock clk_3v3_n -max 53.233 [get_ports {ad_n16}] |  | set_input_delay -clock clk_3v3_n -min 2.109 [get_ports {ad_n16}] set_input_delay -clock clk_3v3_n -max 52.062 [get_ports {ad_n16}] set_output_delay -clock clk_3v3_n -min -6.450 [get_ports {ad_n16}] set_output_delay -clock clk_3v3_n -max 53.233 [get_ports {ad_n16}]
A22 | C15~IO_L12N_T1_MRCC_15 | VCCO_AB | C15 |  | MRCC | 43 | ad_n15 | C15~IO_L12N_T1_MRCC_15 | ad_n15 | 16.17 | 38.11 |  | 54.28 | 2.14 |  | 14.82 | IO | set_property PACKAGE_PIN C15 [get_ports {ad_n15}] set_property IOSTANDARD LVTTL [get_ports {ad_n15}] | set_input_delay -clock clk_3v3_n -min 2.176 [get_ports {ad_n15}] set_input_delay -clock clk_3v3_n -max 52.151 [get_ports {ad_n15}] | set_output_delay -clock clk_3v3_n -min -6.383 [get_ports {ad_n15}] set_output_delay -clock clk_3v3_n -max 53.322 [get_ports {ad_n15}] |  | set_input_delay -clock clk_3v3_n -min 2.176 [get_ports {ad_n15}] set_input_delay -clock clk_3v3_n -max 52.151 [get_ports {ad_n15}] set_output_delay -clock clk_3v3_n -min -6.383 [get_ports {ad_n15}] set_output_delay -clock clk_3v3_n -max 53.322 [get_ports {ad_n15}]
B22 | D15~IO_L12P_T1_MRCC_15 | VCCO_AB | D15 |  | MRCC | 44 | ad_n14 | D15~IO_L12P_T1_MRCC_15 | ad_n14 | 7.67 | 35.57 |  | 43.24 | 1.70 |  | 25.86 | IO | set_property PACKAGE_PIN D15 [get_ports {ad_n14}] set_property IOSTANDARD LVTTL [get_ports {ad_n14}] | set_input_delay -clock clk_3v3_n -min 2.121 [get_ports {ad_n14}] set_input_delay -clock clk_3v3_n -max 52.078 [get_ports {ad_n14}] | set_output_delay -clock clk_3v3_n -min -6.438 [get_ports {ad_n14}] set_output_delay -clock clk_3v3_n -max 53.249 [get_ports {ad_n14}] |  | set_input_delay -clock clk_3v3_n -min 2.121 [get_ports {ad_n14}] set_input_delay -clock clk_3v3_n -max 52.078 [get_ports {ad_n14}] set_output_delay -clock clk_3v3_n -min -6.438 [get_ports {ad_n14}] set_output_delay -clock clk_3v3_n -max 53.249 [get_ports {ad_n14}]
A23 | B17~IO_L7N_T1_AD2N_15 | VCCO_AB | B17 |  |  | 45 | ad_n13 | B17~IO_L7N_T1_AD2N_15 | ad_n13 | 12.65 | 38.11 |  | 50.76 | 2.00 |  | 18.34 | IO | set_property PACKAGE_PIN B17 [get_ports {ad_n13}] set_property IOSTANDARD LVTTL [get_ports {ad_n13}] | set_input_delay -clock clk_3v3_n -min 2.158 [get_ports {ad_n13}] set_input_delay -clock clk_3v3_n -max 52.128 [get_ports {ad_n13}] | set_output_delay -clock clk_3v3_n -min -6.401 [get_ports {ad_n13}] set_output_delay -clock clk_3v3_n -max 53.299 [get_ports {ad_n13}] |  | set_input_delay -clock clk_3v3_n -min 2.158 [get_ports {ad_n13}] set_input_delay -clock clk_3v3_n -max 52.128 [get_ports {ad_n13}] set_output_delay -clock clk_3v3_n -min -6.401 [get_ports {ad_n13}] set_output_delay -clock clk_3v3_n -max 53.299 [get_ports {ad_n13}]
B23 | B16~IO_L7P_T1_AD2P_15 | VCCO_AB | B16 |  |  | 46 | ad_n12 | B16~IO_L7P_T1_AD2P_15 | ad_n12 | 6.56 | 35.57 |  | 42.13 | 1.66 |  | 26.97 | IO | set_property PACKAGE_PIN B16 [get_ports {ad_n12}] set_property IOSTANDARD LVTTL [get_ports {ad_n12}] | set_input_delay -clock clk_3v3_n -min 2.115 [get_ports {ad_n12}] set_input_delay -clock clk_3v3_n -max 52.070 [get_ports {ad_n12}] | set_output_delay -clock clk_3v3_n -min -6.444 [get_ports {ad_n12}] set_output_delay -clock clk_3v3_n -max 53.241 [get_ports {ad_n12}] |  | set_input_delay -clock clk_3v3_n -min 2.115 [get_ports {ad_n12}] set_input_delay -clock clk_3v3_n -max 52.070 [get_ports {ad_n12}] set_output_delay -clock clk_3v3_n -min -6.444 [get_ports {ad_n12}] set_output_delay -clock clk_3v3_n -max 53.241 [get_ports {ad_n12}]
A24 | C14~IO_L1N_T0_AD0N_15 | VCCO_AB | C14 |  |  | 47 | ad_n11 | C14~IO_L1N_T0_AD0N_15 | ad_n11 | 16.68 | 38.11 |  | 54.79 | 2.16 |  | 14.31 | IO | set_property PACKAGE_PIN C14 [get_ports {ad_n11}] set_property IOSTANDARD LVTTL [get_ports {ad_n11}] | set_input_delay -clock clk_3v3_n -min 2.178 [get_ports {ad_n11}] set_input_delay -clock clk_3v3_n -max 52.155 [get_ports {ad_n11}] | set_output_delay -clock clk_3v3_n -min -6.381 [get_ports {ad_n11}] set_output_delay -clock clk_3v3_n -max 53.326 [get_ports {ad_n11}] |  | set_input_delay -clock clk_3v3_n -min 2.178 [get_ports {ad_n11}] set_input_delay -clock clk_3v3_n -max 52.155 [get_ports {ad_n11}] set_output_delay -clock clk_3v3_n -min -6.381 [get_ports {ad_n11}] set_output_delay -clock clk_3v3_n -max 53.326 [get_ports {ad_n11}]
B24 | D14~IO_L1P_T0_AD0P_15 | VCCO_AB | D14 |  |  | 48 | ad_n10 | D14~IO_L1P_T0_AD0P_15 | ad_n10 | 9.37 | 35.57 |  | 44.94 | 1.77 |  | 24.16 | IO | set_property PACKAGE_PIN D14 [get_ports {ad_n10}] set_property IOSTANDARD LVTTL [get_ports {ad_n10}] | set_input_delay -clock clk_3v3_n -min 2.129 [get_ports {ad_n10}] set_input_delay -clock clk_3v3_n -max 52.089 [get_ports {ad_n10}] | set_output_delay -clock clk_3v3_n -min -6.430 [get_ports {ad_n10}] set_output_delay -clock clk_3v3_n -max 53.260 [get_ports {ad_n10}] |  | set_input_delay -clock clk_3v3_n -min 2.129 [get_ports {ad_n10}] set_input_delay -clock clk_3v3_n -max 52.089 [get_ports {ad_n10}] set_output_delay -clock clk_3v3_n -min -6.430 [get_ports {ad_n10}] set_output_delay -clock clk_3v3_n -max 53.260 [get_ports {ad_n10}]
A25 | D13~IO_L6N_T0_VREF_15 | VCCO_AB | D13 |  | VREF Bank 15 | 49 | ad_n9 | D13~IO_L6N_T0_VREF_15 | ad_n9 | 18.84 | 38.11 |  | 56.95 | 2.24 |  | 12.15 | IO | set_property PACKAGE_PIN D13 [get_ports {ad_n9}] set_property IOSTANDARD LVTTL [get_ports {ad_n9}] | set_input_delay -clock clk_3v3_n -min 2.189 [get_ports {ad_n9}] set_input_delay -clock clk_3v3_n -max 52.169 [get_ports {ad_n9}] | set_output_delay -clock clk_3v3_n -min -6.370 [get_ports {ad_n9}] set_output_delay -clock clk_3v3_n -max 53.340 [get_ports {ad_n9}] |  | set_input_delay -clock clk_3v3_n -min 2.189 [get_ports {ad_n9}] set_input_delay -clock clk_3v3_n -max 52.169 [get_ports {ad_n9}] set_output_delay -clock clk_3v3_n -min -6.370 [get_ports {ad_n9}] set_output_delay -clock clk_3v3_n -max 53.340 [get_ports {ad_n9}]
B25 | D12~IO_L6P_T0_15 | VCCO_AB | D12 |  |  | 50 | ad_n8 | D12~IO_L6P_T0_15 | ad_n8 | 11.32 | 35.57 |  | 46.89 | 1.85 |  | 22.21 | IO | set_property PACKAGE_PIN D12 [get_ports {ad_n8}] set_property IOSTANDARD LVTTL [get_ports {ad_n8}] | set_input_delay -clock clk_3v3_n -min 2.139 [get_ports {ad_n8}] set_input_delay -clock clk_3v3_n -max 52.102 [get_ports {ad_n8}] | set_output_delay -clock clk_3v3_n -min -6.420 [get_ports {ad_n8}] set_output_delay -clock clk_3v3_n -max 53.273 [get_ports {ad_n8}] |  | set_input_delay -clock clk_3v3_n -min 2.139 [get_ports {ad_n8}] set_input_delay -clock clk_3v3_n -max 52.102 [get_ports {ad_n8}] set_output_delay -clock clk_3v3_n -min -6.420 [get_ports {ad_n8}] set_output_delay -clock clk_3v3_n -max 53.273 [get_ports {ad_n8}]
A26 | A16~IO_L8N_T1_AD10N_15 | VCCO_AB | A16 |  |  | 51 | ad_n7 | A16~IO_L8N_T1_AD10N_15 | ad_n7 | 14.67 | 38.11 |  | 52.78 | 2.08 |  | 16.32 | IO | set_property PACKAGE_PIN A16 [get_ports {ad_n7}] set_property IOSTANDARD LVTTL [get_ports {ad_n7}] | set_input_delay -clock clk_3v3_n -min 2.168 [get_ports {ad_n7}] set_input_delay -clock clk_3v3_n -max 52.141 [get_ports {ad_n7}] | set_output_delay -clock clk_3v3_n -min -6.391 [get_ports {ad_n7}] set_output_delay -clock clk_3v3_n -max 53.312 [get_ports {ad_n7}] |  | set_input_delay -clock clk_3v3_n -min 2.168 [get_ports {ad_n7}] set_input_delay -clock clk_3v3_n -max 52.141 [get_ports {ad_n7}] set_output_delay -clock clk_3v3_n -min -6.391 [get_ports {ad_n7}] set_output_delay -clock clk_3v3_n -max 53.312 [get_ports {ad_n7}]
B26 | A15~IO_L8P_T1_AD10P_15 | VCCO_AB | A15 |  |  | 52 | ad_n6 | A15~IO_L8P_T1_AD10P_15 | ad_n6 | 10.64 | 35.57 |  | 46.21 | 1.82 |  | 22.89 | IO | set_property PACKAGE_PIN A15 [get_ports {ad_n6}] set_property IOSTANDARD LVTTL [get_ports {ad_n6}] | set_input_delay -clock clk_3v3_n -min 2.136 [get_ports {ad_n6}] set_input_delay -clock clk_3v3_n -max 52.097 [get_ports {ad_n6}] | set_output_delay -clock clk_3v3_n -min -6.423 [get_ports {ad_n6}] set_output_delay -clock clk_3v3_n -max 53.269 [get_ports {ad_n6}] |  | set_input_delay -clock clk_3v3_n -min 2.136 [get_ports {ad_n6}] set_input_delay -clock clk_3v3_n -max 52.097 [get_ports {ad_n6}] set_output_delay -clock clk_3v3_n -min -6.423 [get_ports {ad_n6}] set_output_delay -clock clk_3v3_n -max 53.269 [get_ports {ad_n6}]
A27 | B14~IO_L2N_T0_AD8N_15 | VCCO_AB | B14 |  |  | 53 | ad_n5 | B14~IO_L2N_T0_AD8N_15 | ad_n5 | 17.14 | 38.11 |  | 55.25 | 2.18 |  | 13.85 | IO | set_property PACKAGE_PIN B14 [get_ports {ad_n5}] set_property IOSTANDARD LVTTL [get_ports {ad_n5}] | set_input_delay -clock clk_3v3_n -min 2.181 [get_ports {ad_n5}] set_input_delay -clock clk_3v3_n -max 52.158 [get_ports {ad_n5}] | set_output_delay -clock clk_3v3_n -min -6.378 [get_ports {ad_n5}] set_output_delay -clock clk_3v3_n -max 53.329 [get_ports {ad_n5}] |  | set_input_delay -clock clk_3v3_n -min 2.181 [get_ports {ad_n5}] set_input_delay -clock clk_3v3_n -max 52.158 [get_ports {ad_n5}] set_output_delay -clock clk_3v3_n -min -6.378 [get_ports {ad_n5}] set_output_delay -clock clk_3v3_n -max 53.329 [get_ports {ad_n5}]
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

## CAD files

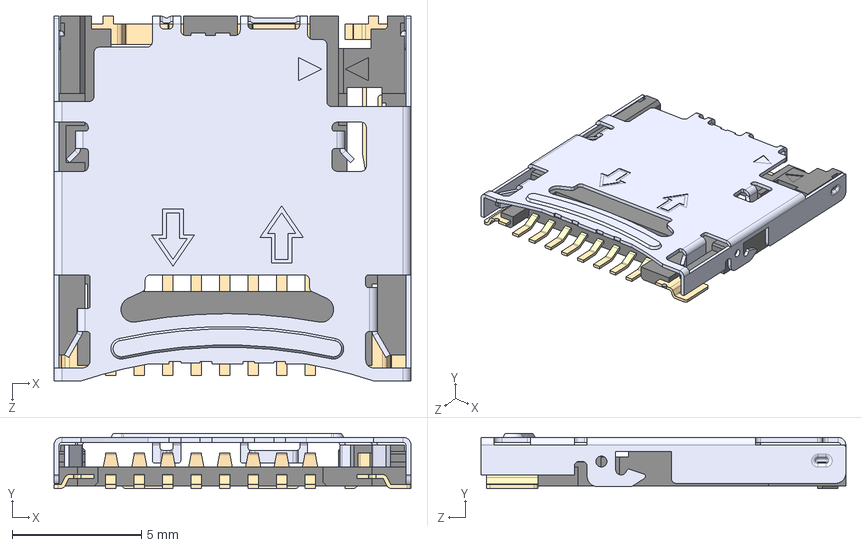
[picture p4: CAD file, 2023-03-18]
nubus-to-ztex/DM3CS-SF.step
13.8 x 2.13 x 14.1 mm

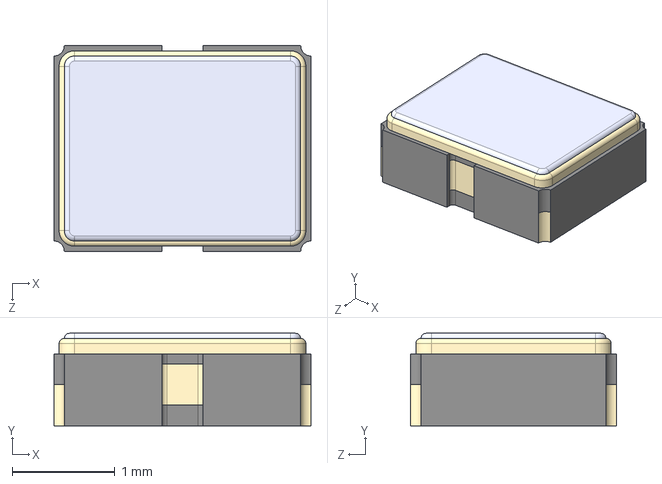
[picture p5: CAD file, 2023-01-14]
nubus-to-ztex/ECS-2520MV-250-CN-TR.STEP
2.50 x 0.9 x 2.00 mm

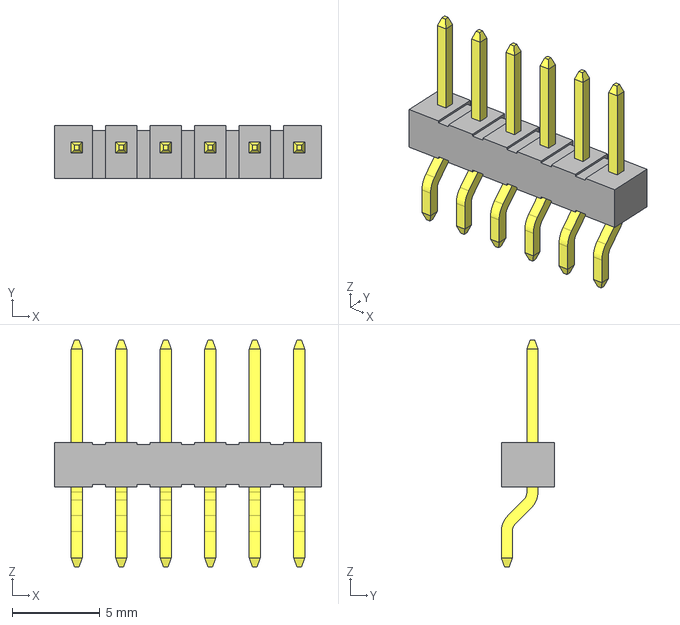
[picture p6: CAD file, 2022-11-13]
nubus-to-ztex/TSM-106-01-L-SH.step
15.2 x 3.05 x 13.0 mm
T-1S6-08(-01-6-SH)
TSM-106-01-SH_body

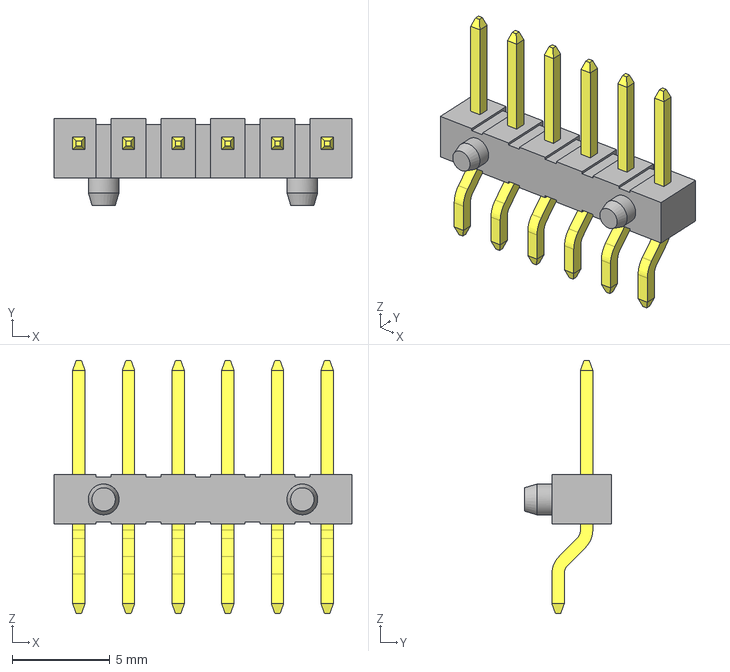
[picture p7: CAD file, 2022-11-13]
nubus-to-ztex/TSM-106-01-T-SH-A.step
15.2 x 4.44 x 13.0 mm
T-1S6-08(-01-6-SH)
TSM-106-01-SH-A_body

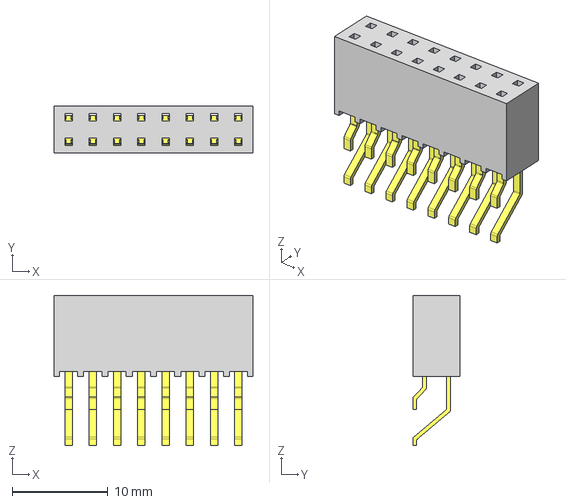
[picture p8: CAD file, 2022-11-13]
nubus-to-ztex/SAMTEC-SMH-108-02-X-D.step
20.8 x 4.95 x 15.7 mm
C-08-03-08-D_SMH
SMH-108-D_socket

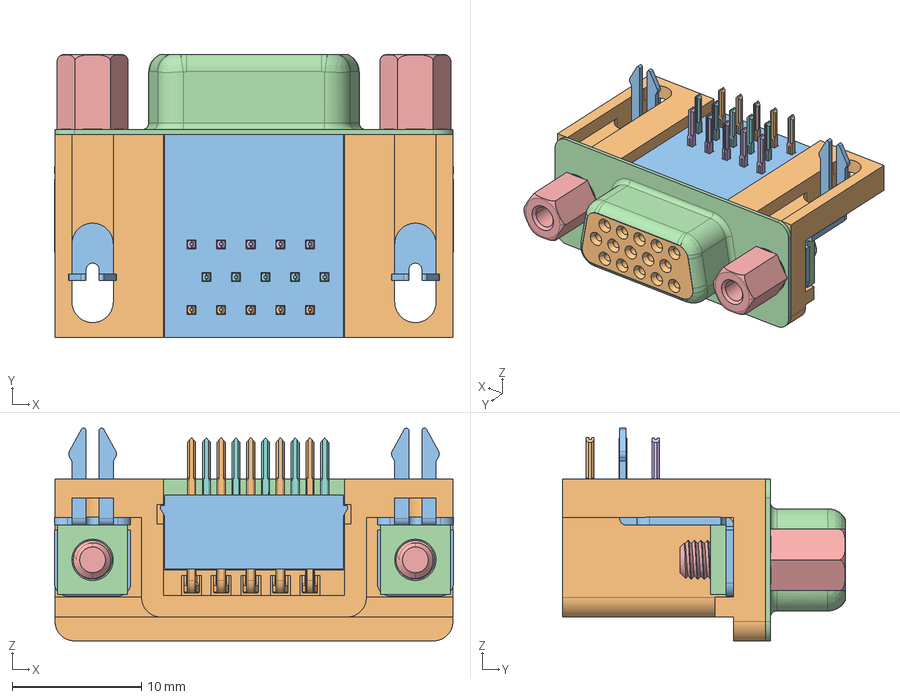
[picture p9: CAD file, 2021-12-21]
nubus-to-ztex/L77HDE15SD1CH4F--3DModel-STEP-533217.STEP
30.9 x 21.9 x 16.5 mm
D112-H15S
ZZ x 2
MM x 2
T3 x 5
T2 x 5
T1 x 5
CC
H15S-SHEL

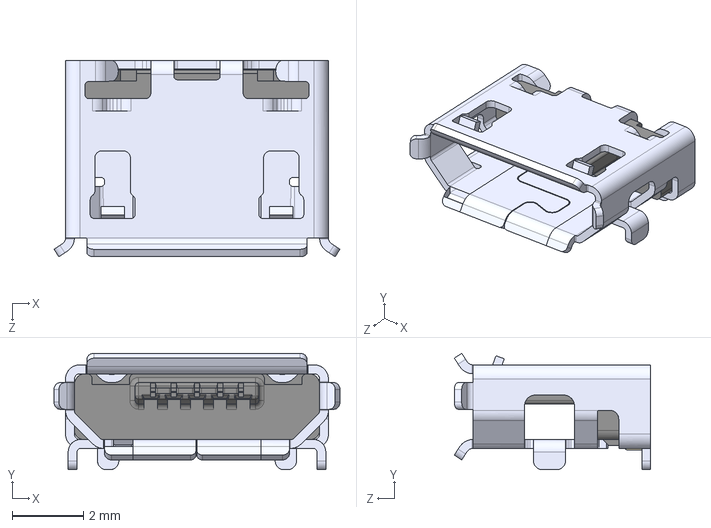
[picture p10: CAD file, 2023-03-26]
nubus-to-ztex/10118194-0001LF--3DModel-STEP-269445.STEP
8.05 x 3.27 x 5.53 mm

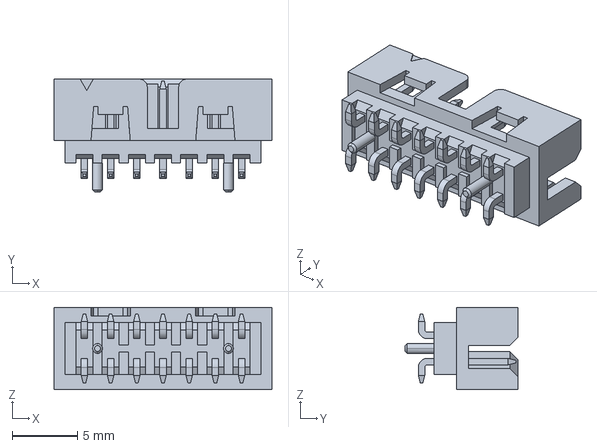
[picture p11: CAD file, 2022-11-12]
nubus-to-ztex/87832-1420.stp
16.6 x 8.60 x 6.30 mm

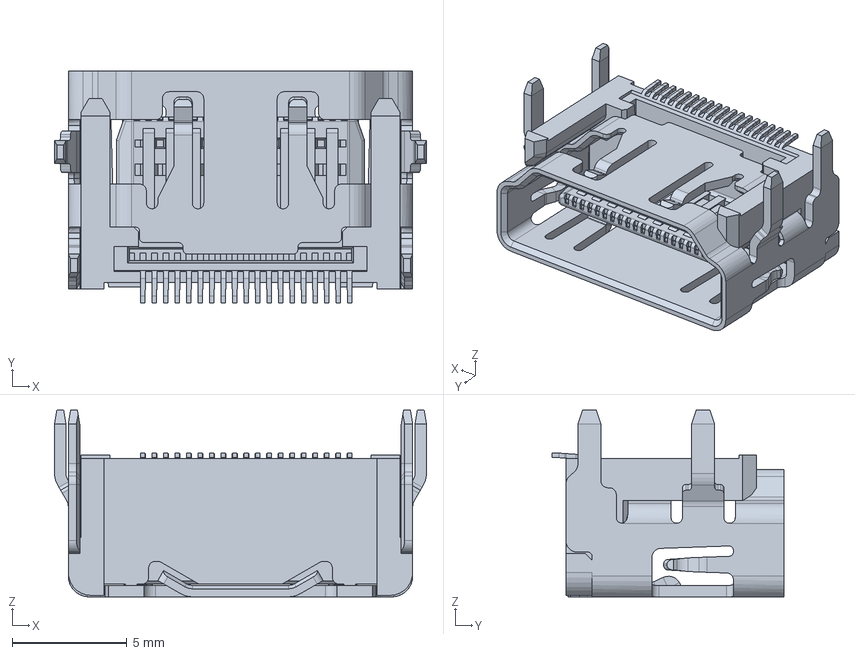
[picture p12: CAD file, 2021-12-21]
nubus-to-ztex/10029449-111RLF.stp
16.2 x 10.1 x 8.13 mm

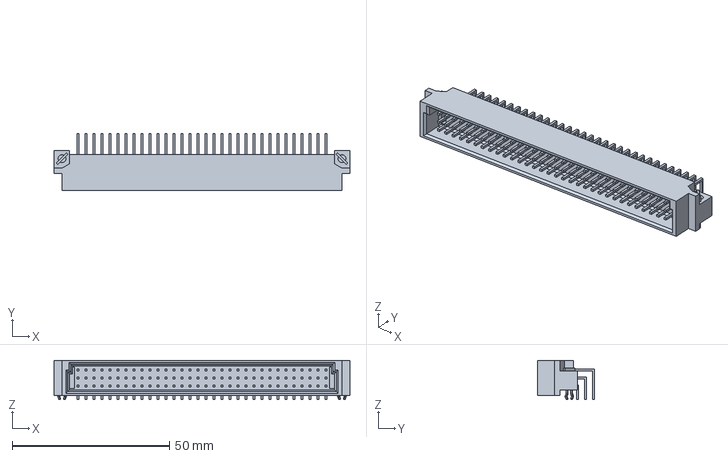
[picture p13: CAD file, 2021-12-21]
nubus-to-ztex/850030567.stp
94.0 x 18.1 x 12.4 mm

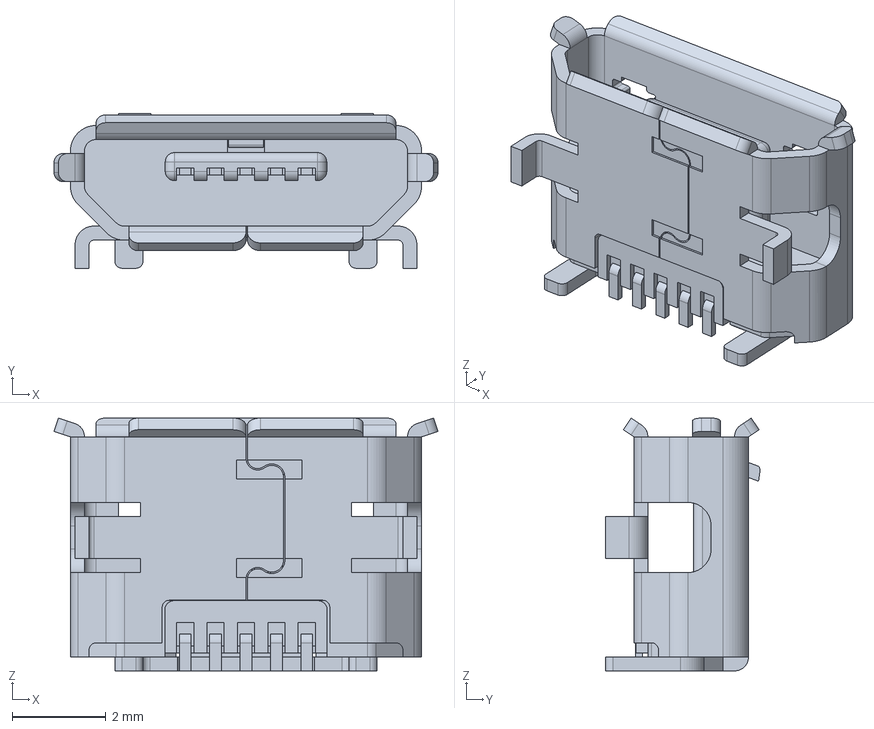
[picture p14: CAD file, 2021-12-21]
nubus-to-ztex/1050170001.stp
8.20 x 3.30 x 5.40 mm

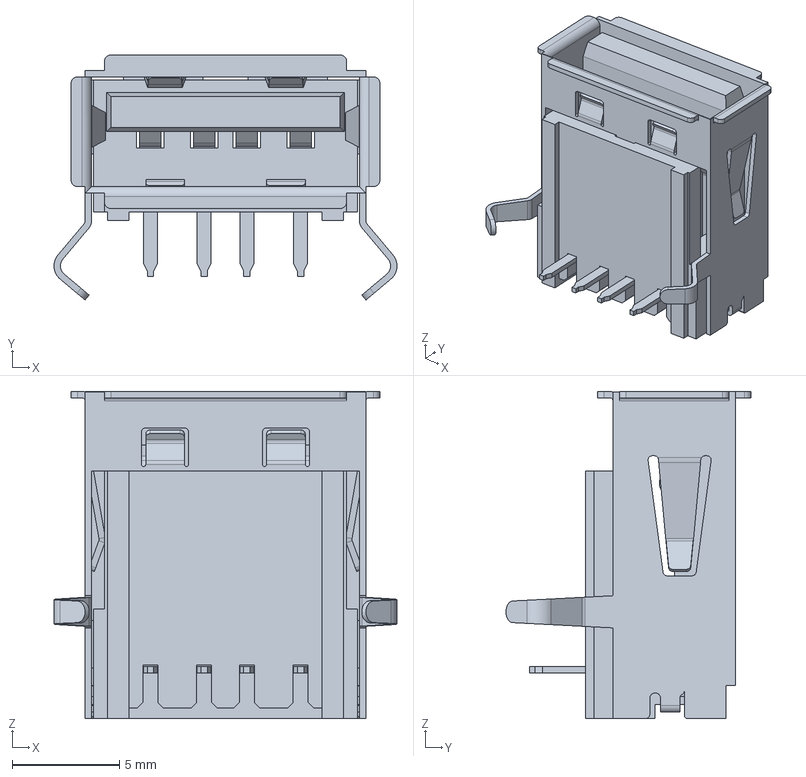
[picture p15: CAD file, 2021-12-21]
nubus-to-ztex/676432911.stp
16.0 x 11.4 x 15.3 mm

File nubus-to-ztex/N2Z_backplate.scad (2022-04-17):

THICKNESS_MAX=2.44;
THICKNESS=2.4;

ORIGINAL_THICKNESS=25.4/32;

NUBUS_HEIGHT_BELOW_OUTER_LIP=92; // NuBus p57, max is 97.25
NUBUS_HEIGHT_ABOVE_OUTER_LIP=6; // NuBus p57

NUBUS_BETWEEN_NOTCHES=87.25; // DCDMF3 p625 & p635, bottom of low to top of high?
NUBUS_HIGH_NOTCH_TO_TOP=10.35;// DCDMF3 p635, top of high to bottom of inner lip ?

NUBUS_BASE_WIDTH=18.57;
NUBUS_EXTRA_WIDTH=2.93;
NUBUS_FULL_WIDTH=NUBUS_BASE_WIDTH+NUBUS_EXTRA_WIDTH;
NUBUS_TOP_WIDTH=21.82;
NUBUS_OVERHANG_WIDTH=NUBUS_TOP_WIDTH-NUBUS_BASE_WIDTH;
NUBUS_EXTRA_FROM_TOP=20.5;
NUBUS_ANGLE_SECTION_LACK_OF_WIDTH=2.57;
NUBUS_ANGLE_SECTION_WIDTH_REDUCTION=NUBUS_EXTRA_WIDTH+NUBUS_ANGLE_SECTION_LACK_OF_WIDTH;

NUBUS_HEIGHT_NARROW_BOTTOM_TO_TOP=94.6;
NUBUS_FULL_HEIGHT=(NUBUS_BETWEEN_NOTCHES+NUBUS_HIGH_NOTCH_TO_TOP);
NUBUS_NARROW_BOTTOM_HEIGHT=NUBUS_FULL_HEIGHT-NUBUS_HEIGHT_NARROW_BOTTOM_TO_TOP;

NUBUS_EXTRA_NARROW_BOTTOM=1.5;

NUBUS_OVERHANG_MIN_HEIGHT=8.4;
NUBUS_OVERHANG_MAX_HEIGHT=12.18;
NUBUS_OVERHANG_RADIUS=3.2;
NUBUS_TOP_BIT_WIDTH=9.57-2.57;

FRONT_NOTCH_FROM_TOP=85.9;
FRONT_NOTCH_STRAIGHT_WIDTH=2;
FRONT_NOTCH_STRAIGHT_HEIGHT=6;
FRONT_NOTCH_ANGLE_HEIGHT=(NUBUS_BETWEEN_NOTCHES+NUBUS_HIGH_NOTCH_TO_TOP)-(FRONT_NOTCH_FROM_TOP+FRONT_NOTCH_STRAIGHT_HEIGHT);
FRONT_NOTCH_ANGLE_WIDTH=FRONT_NOTCH_ANGLE_HEIGHT*sin(23);

points=[[0,0],
        [NUBUS_BASE_WIDTH-7.82-FRONT_NOTCH_STRAIGHT_WIDTH/2-FRONT_NOTCH_ANGLE_WIDTH,0],
        [NUBUS_BASE_WIDTH-7.82-FRONT_NOTCH_STRAIGHT_WIDTH/2,FRONT_NOTCH_ANGLE_HEIGHT],
        [NUBUS_BASE_WIDTH-7.82-FRONT_NOTCH_STRAIGHT_WIDTH/2,FRONT_NOTCH_ANGLE_HEIGHT+FRONT_NOTCH_STRAIGHT_HEIGHT],
        [NUBUS_BASE_WIDTH-7.82+FRONT_NOTCH_STRAIGHT_WIDTH/2,FRONT_NOTCH_ANGLE_HEIGHT+FRONT_NOTCH_STRAIGHT_HEIGHT],
        [NUBUS_BASE_WIDTH-7.82+FRONT_NOTCH_STRAIGHT_WIDTH/2,FRONT_NOTCH_ANGLE_HEIGHT],
        [NUBUS_BASE_WIDTH-7.82+FRONT_NOTCH_STRAIGHT_WIDTH/2+FRONT_NOTCH_ANGLE_WIDTH,0],
        [NUBUS_BASE_WIDTH-NUBUS_EXTRA_NARROW_BOTTOM,0],
        
        [NUBUS_BASE_WIDTH-NUBUS_EXTRA_NARROW_BOTTOM,NUBUS_NARROW_BOTTOM_HEIGHT],
        [NUBUS_FULL_WIDTH,NUBUS_NARROW_BOTTOM_HEIGHT],
        [NUBUS_FULL_WIDTH,NUBUS_FULL_HEIGHT-NUBUS_EXTRA_FROM_TOP],
        [NUBUS_FULL_WIDTH-NUBUS_ANGLE_SECTION_WIDTH_REDUCTION,(NUBUS_FULL_HEIGHT-NUBUS_EXTRA_FROM_TOP)+(NUBUS_ANGLE_SECTION_WIDTH_REDUCTION*2)],
        [NUBUS_FULL_WIDTH-NUBUS_ANGLE_SECTION_WIDTH_REDUCTION,NUBUS_FULL_HEIGHT+ORIGINAL_THICKNESS],
        [NUBUS_FULL_WIDTH-NUBUS_ANGLE_SECTION_WIDTH_REDUCTION-NUBUS_TOP_BIT_WIDTH,NUBUS_FULL_HEIGHT+ORIGINAL_THICKNESS],
        [NUBUS_FULL_WIDTH-NUBUS_ANGLE_SECTION_WIDTH_REDUCTION-NUBUS_TOP_BIT_WIDTH,NUBUS_FULL_HEIGHT+ORIGINAL_THICKNESS-6], //6: measurement
        [NUBUS_FULL_WIDTH-NUBUS_ANGLE_SECTION_WIDTH_REDUCTION-NUBUS_TOP_BIT_WIDTH-2,NUBUS_FULL_HEIGHT+ORIGINAL_THICKNESS-6], //2&6: measurement
        [NUBUS_FULL_WIDTH-NUBUS_ANGLE_SECTION_WIDTH_REDUCTION-NUBUS_TOP_BIT_WIDTH-2,NUBUS_FULL_HEIGHT+ORIGINAL_THICKNESS-NUBUS_HIGH_NOTCH_TO_TOP+5], // 5 is the diustance between top notch and top screw hole
        [-NUBUS_OVERHANG_WIDTH,NUBUS_FULL_HEIGHT+ORIGINAL_THICKNESS-NUBUS_HIGH_NOTCH_TO_TOP+5],
        [-NUBUS_OVERHANG_WIDTH,NUBUS_FULL_HEIGHT-NUBUS_OVERHANG_MAX_HEIGHT+NUBUS_OVERHANG_RADIUS],
        [0,NUBUS_FULL_HEIGHT-NUBUS_OVERHANG_MAX_HEIGHT]        
];

module backplate() {
linear_extrude(height = ORIGINAL_THICKNESS, center = true) { polygon(points); };
}

// PCB, don't print
PCB_THICKNESS=1.6;
PCB_OFFSET=(NUBUS_FULL_WIDTH-2.93)-PCB_THICKNESS/2;
module pcb() {
    color("green") translate([PCB_OFFSET,0,-50]) linear_extrude(height = 100, center = true) { polygon ([[-PCB_THICKNESS,-5.08],[0,-5.08],[0,91.52],[-PCB_THICKNESS,91.52]]); };
}

// NuBusFPGA
BOTTOM_HOLE_Y=8-1.08;
TOP_HOLE_Y=87.52;
FIRST_HOLE_X=-6.44;
SECOND_HOLE_X=-16.44;

module holders() {
difference() {
union() {
color("red") translate([0,0,-11]) linear_extrude(height = 22, center = true) { polygon([
    [PCB_OFFSET-PCB_THICKNESS,BOTTOM_HOLE_Y-4],
    [PCB_OFFSET-PCB_THICKNESS,BOTTOM_HOLE_Y+4],
    [PCB_OFFSET-PCB_THICKNESS-2,BOTTOM_HOLE_Y+4],
    [PCB_OFFSET-PCB_THICKNESS-2,BOTTOM_HOLE_Y-4],
    ]); };
color("red") translate([0,0,-11]) linear_extrude(height = 22, center = true) { polygon([
    [PCB_OFFSET-PCB_THICKNESS,TOP_HOLE_Y-4],
    [PCB_OFFSET-PCB_THICKNESS,TOP_HOLE_Y+4],
    [PCB_OFFSET-PCB_THICKNESS-2,TOP_HOLE_Y+4],
    [PCB_OFFSET-PCB_THICKNESS-2,TOP_HOLE_Y-4],
    ]); };
}
union() { 
color("blue") translate([0,BOTTOM_HOLE_Y,FIRST_HOLE_X]) rotate([0,90,0]) cylinder(r1=1.6,r2=1.6,h=20);
color("blue") translate([0,BOTTOM_HOLE_Y,SECOND_HOLE_X]) rotate([0,90,0]) cylinder(r1=1.6,r2=1.6,h=20);
color("blue") translate([0,TOP_HOLE_Y,FIRST_HOLE_X]) rotate([0,90,0]) cylinder(r1=1.6,r2=1.6,h=20);
color("blue") translate([0,TOP_HOLE_Y,SECOND_HOLE_X]) rotate([0,90,0]) cylinder(r1=1.6,r2=1.6,h=20);
}
}
}


//cube ([16.5+4, 12, 9.5+4 /* 14.8 max */], center = true);
USB_HOLDER_HEIGHT=5;
USB_HOLDER_WIDTH=10;
USB_HOLDER_DEPTH=5;
module usb_pos() {
translate([-1-USB_HOLDER_HEIGHT/2+PCB_OFFSET-PCB_THICKNESS,100-(74.67+(83.47-74.67)/2),-USB_HOLDER_DEPTH/2]) cube([2+USB_HOLDER_HEIGHT,2+USB_HOLDER_WIDTH,USB_HOLDER_DEPTH], center = true);
}
module usb_neg() {
translate([-0.499-USB_HOLDER_HEIGHT/2+PCB_OFFSET-PCB_THICKNESS,100-(74.67+(83.47-74.67)/2),-USB_HOLDER_DEPTH/2]) cube([1.001+USB_HOLDER_HEIGHT,USB_HOLDER_WIDTH,USB_HOLDER_DEPTH*4], center = true);
}

VGA_HOLDER_HEIGHT=14.8;
VGA_HOLDER_WIDTH=31.8;
VGA_HOLDER_DEPTH=2;
module vga_pos() {
    translate([-VGA_HOLDER_HEIGHT/2+PCB_OFFSET-PCB_THICKNESS,100-(18.21+(49.05-18.21)/2),-VGA_HOLDER_DEPTH/2+VGA_HOLDER_DEPTH]) cube ([VGA_HOLDER_HEIGHT, 6+VGA_HOLDER_WIDTH, VGA_HOLDER_DEPTH], center = true);
}
module vga_neg() {
    translate([-VGA_HOLDER_HEIGHT/2+PCB_OFFSET-PCB_THICKNESS,100-(18.21+(49.05-18.21)/2),-VGA_HOLDER_DEPTH/2]) cube ([10, 18, 10+0.001], center = true);
    
    
    translate([-VGA_HOLDER_HEIGHT/2+PCB_OFFSET-PCB_THICKNESS,100-(18.21+(49.05-18.21)/2)-12.5,-VGA_HOLDER_DEPTH/2]) color("black") rotate([0,0,90]) cylinder (h = 10, r1 = 1.6, r2 = 1.6, center = true);
    translate([-VGA_HOLDER_HEIGHT/2+PCB_OFFSET-PCB_THICKNESS,100-(18.21+(49.05-18.21)/2)+12.5,-VGA_HOLDER_DEPTH/2]) color("black") rotate([0,0,90]) cylinder (h = 10, r1 = 1.6, r2 = 1.6, center = true);
}

HDMI_HOLDER_HEIGHT=8;
HDMI_HOLDER_WIDTH=18;
HDMI_HOLDER_DEPTH=2;
module hdmi_pos() {
    translate([-1-HDMI_HOLDER_HEIGHT/2+PCB_OFFSET-PCB_THICKNESS,100-(53.3+(71.3-53.3)/2),-HDMI_HOLDER_DEPTH/2]) cube ([2+HDMI_HOLDER_HEIGHT, 2+HDMI_HOLDER_WIDTH, HDMI_HOLDER_DEPTH], center = true);
}
module hdmi_neg() {
    translate([-0.499-HDMI_HOLDER_HEIGHT/2+PCB_OFFSET-PCB_THICKNESS,100-(53.3+(71.3-53.3)/2),-HDMI_HOLDER_DEPTH/2]) cube ([1.001+HDMI_HOLDER_HEIGHT, HDMI_HOLDER_WIDTH, 5+0.001], center = true);
}

//pcb();

module complete() {
    difference() {
        union() {
            backplate();
            holders();
            usb_pos();
            vga_pos();
            hdmi_pos();
        }
        union() {
            usb_neg();
            vga_neg();
            hdmi_neg();
        }
    }
}

complete();

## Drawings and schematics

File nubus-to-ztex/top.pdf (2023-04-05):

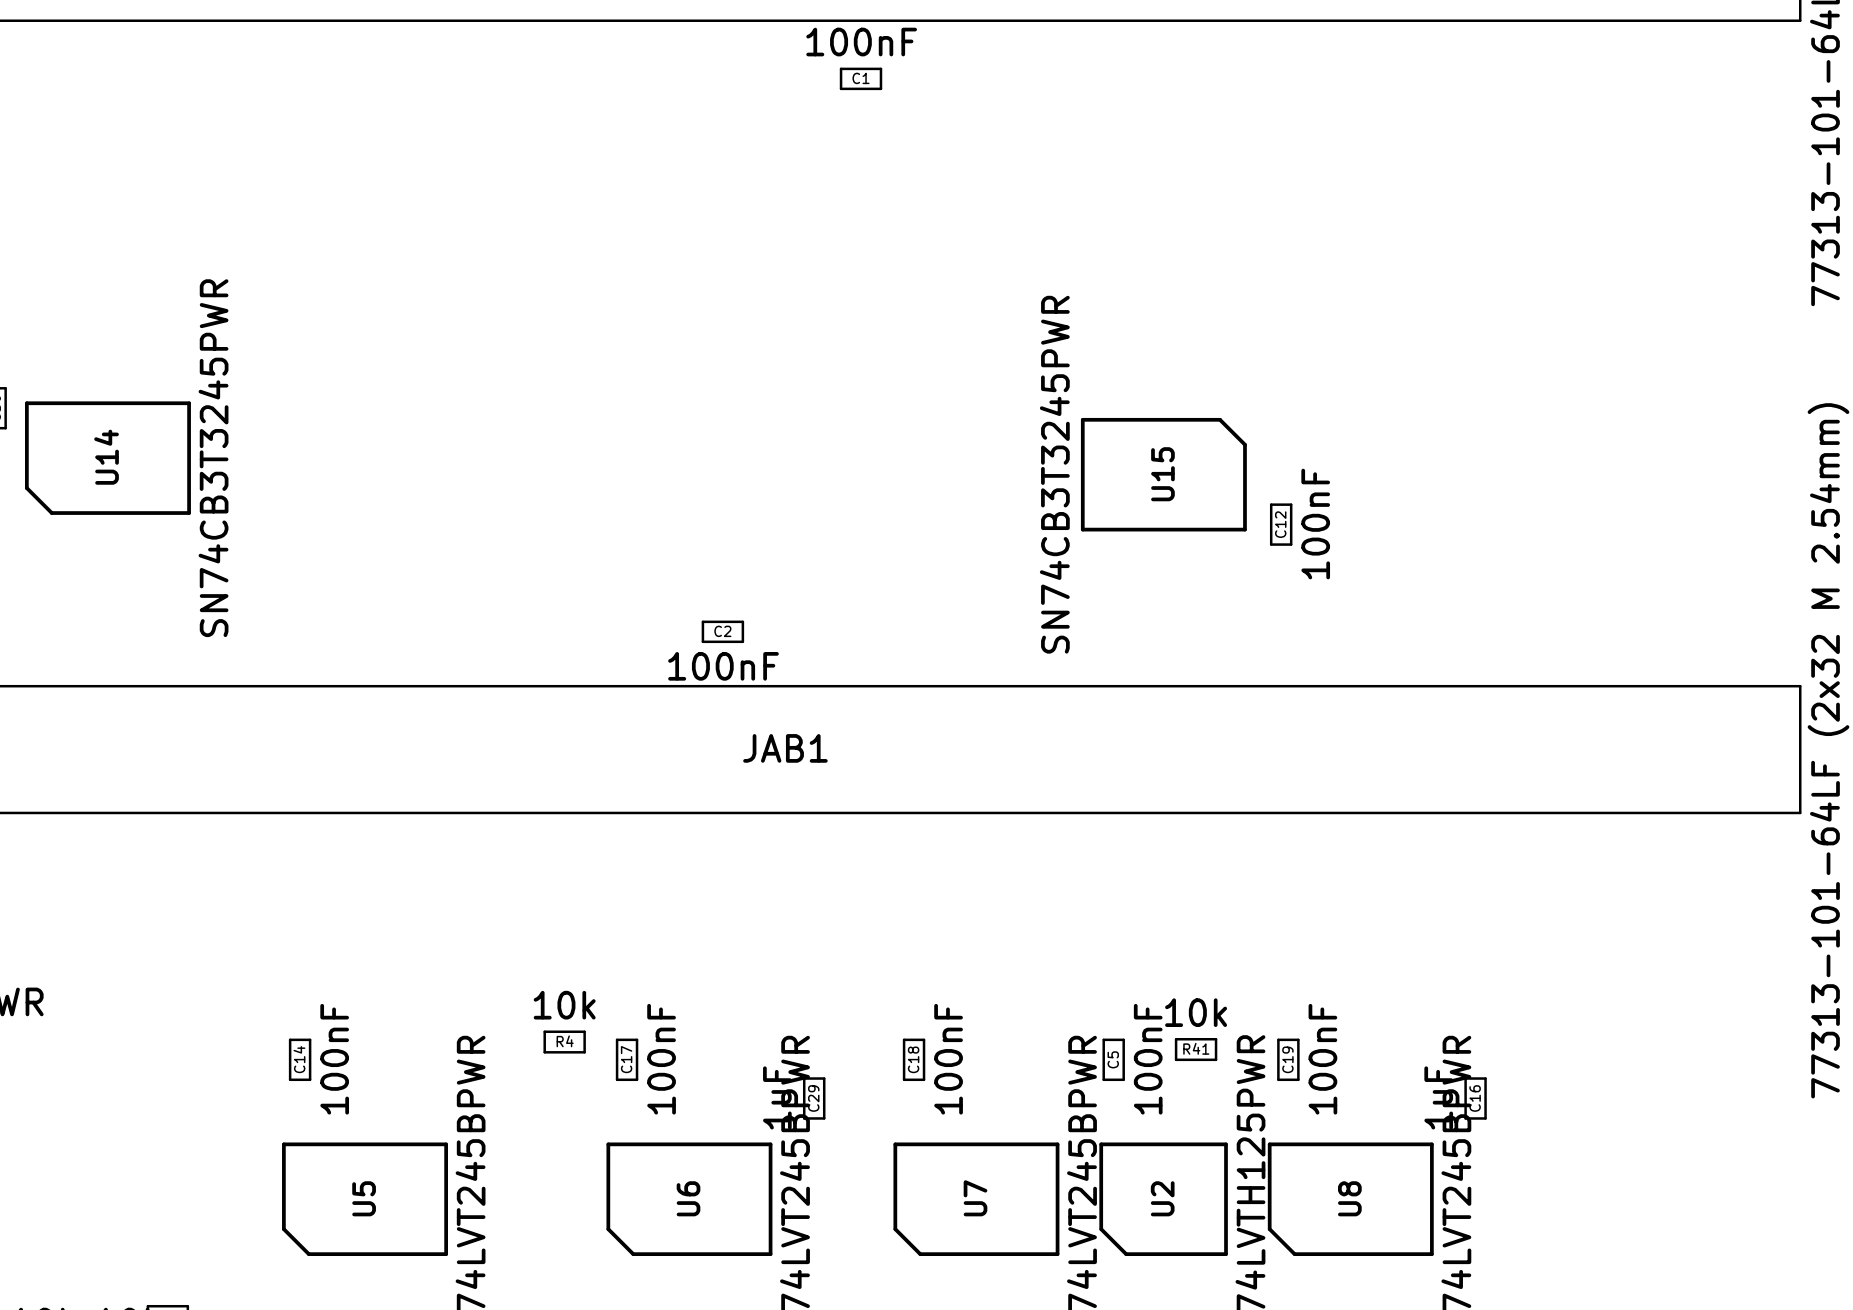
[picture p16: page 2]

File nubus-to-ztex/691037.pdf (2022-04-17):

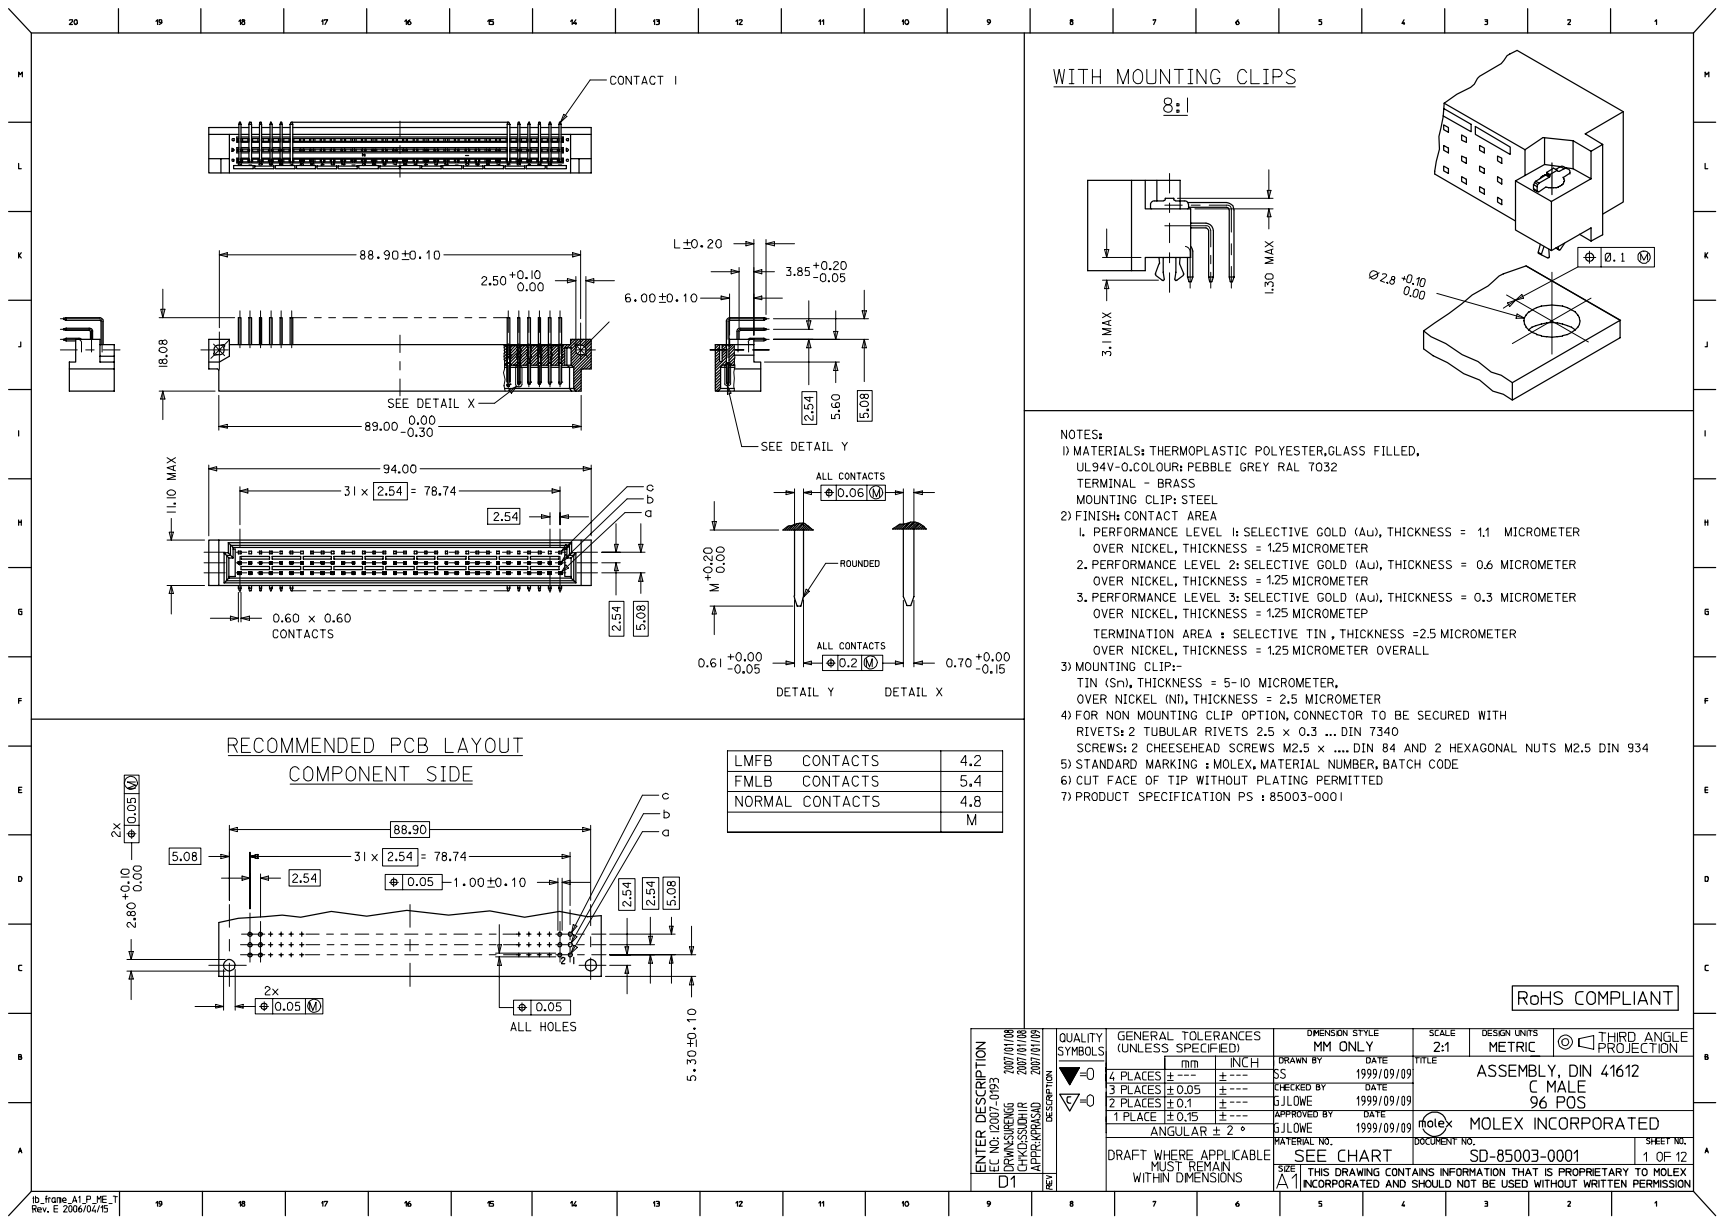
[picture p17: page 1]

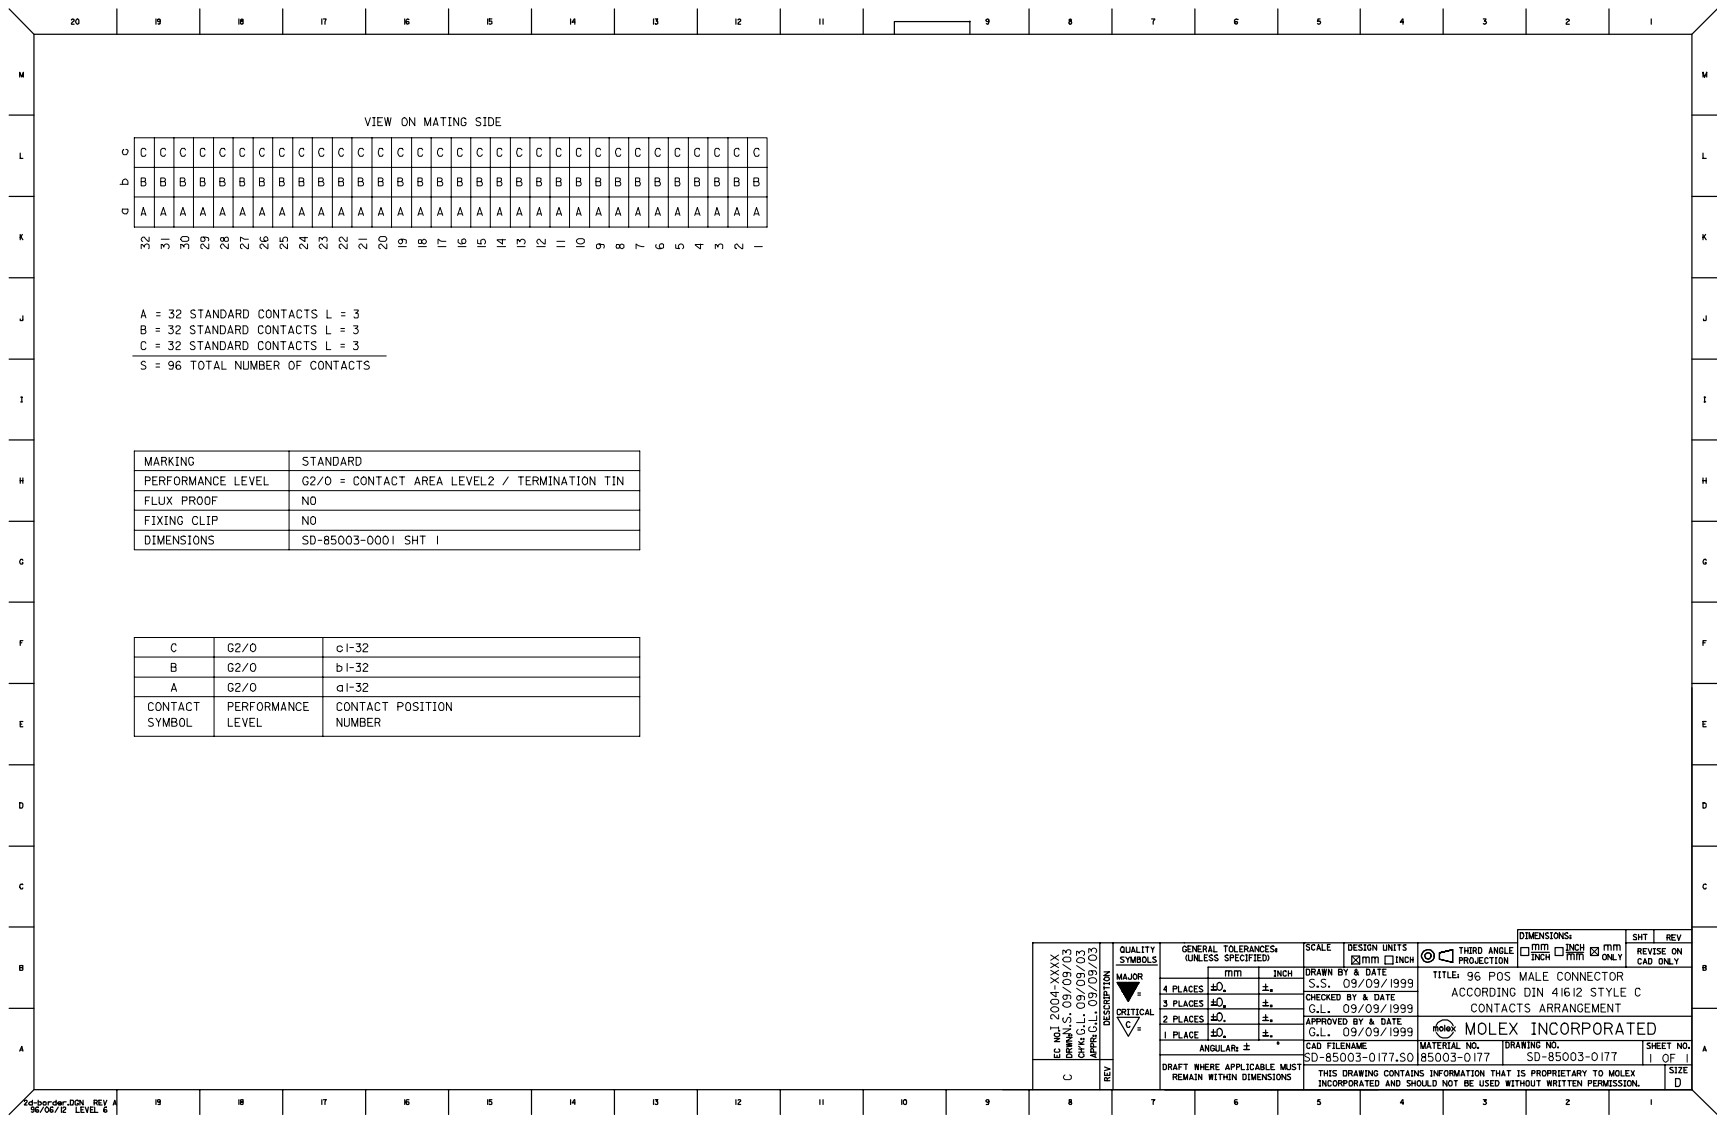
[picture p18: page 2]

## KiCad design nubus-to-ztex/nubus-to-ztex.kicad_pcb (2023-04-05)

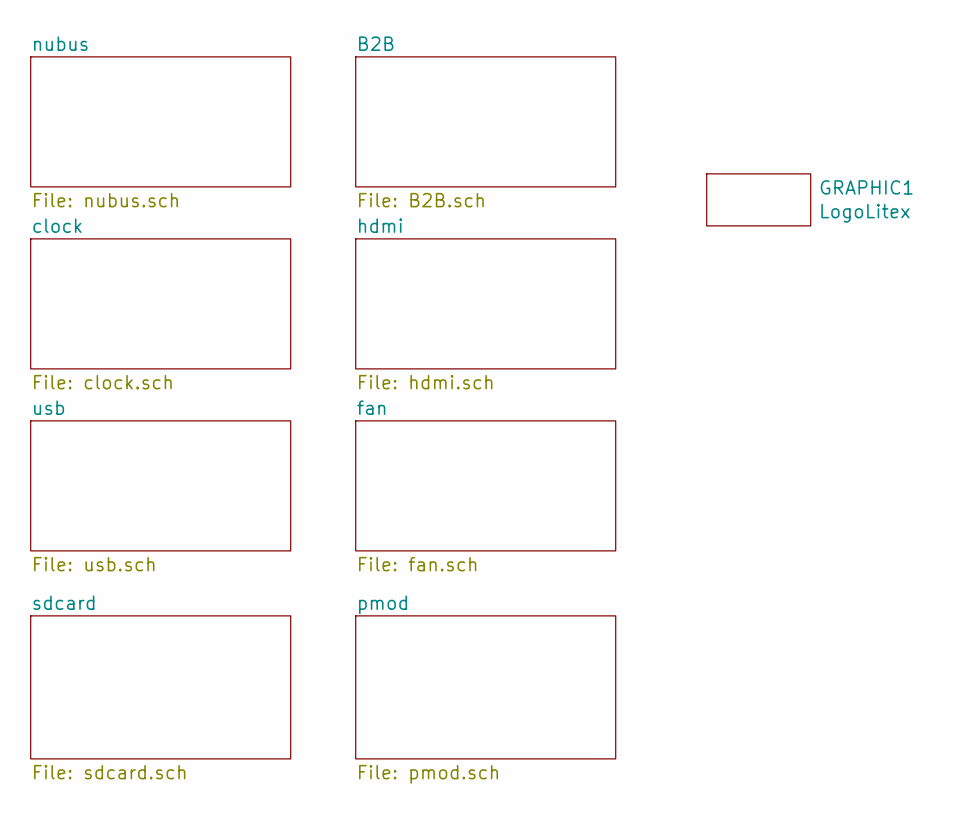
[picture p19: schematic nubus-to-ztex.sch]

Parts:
GRAPHIC1: LogoLitex; litex_logo

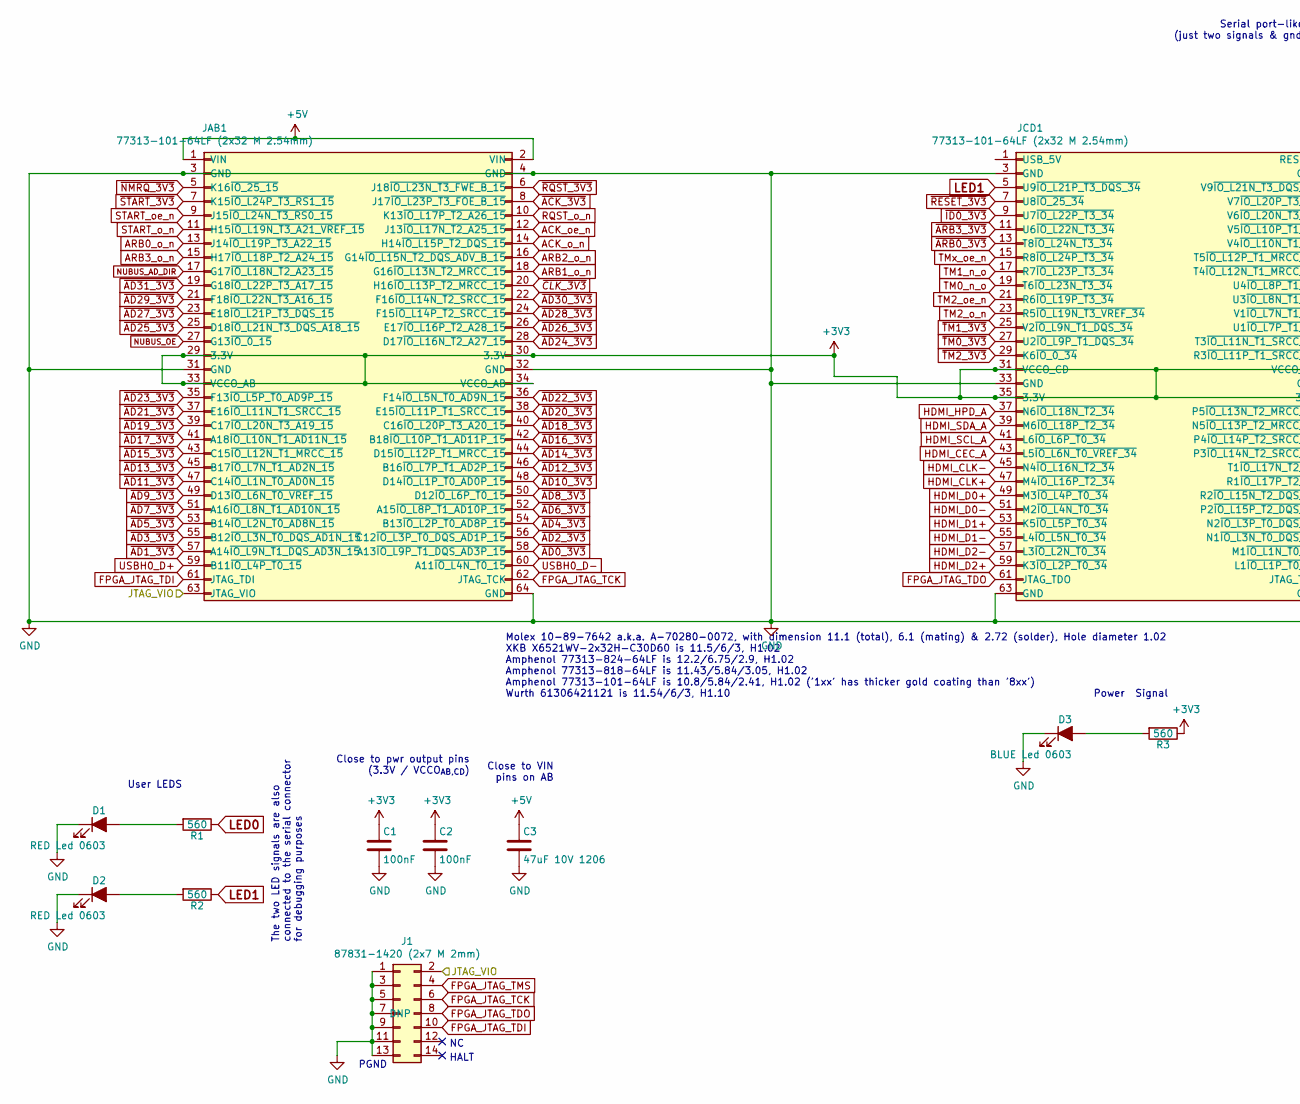
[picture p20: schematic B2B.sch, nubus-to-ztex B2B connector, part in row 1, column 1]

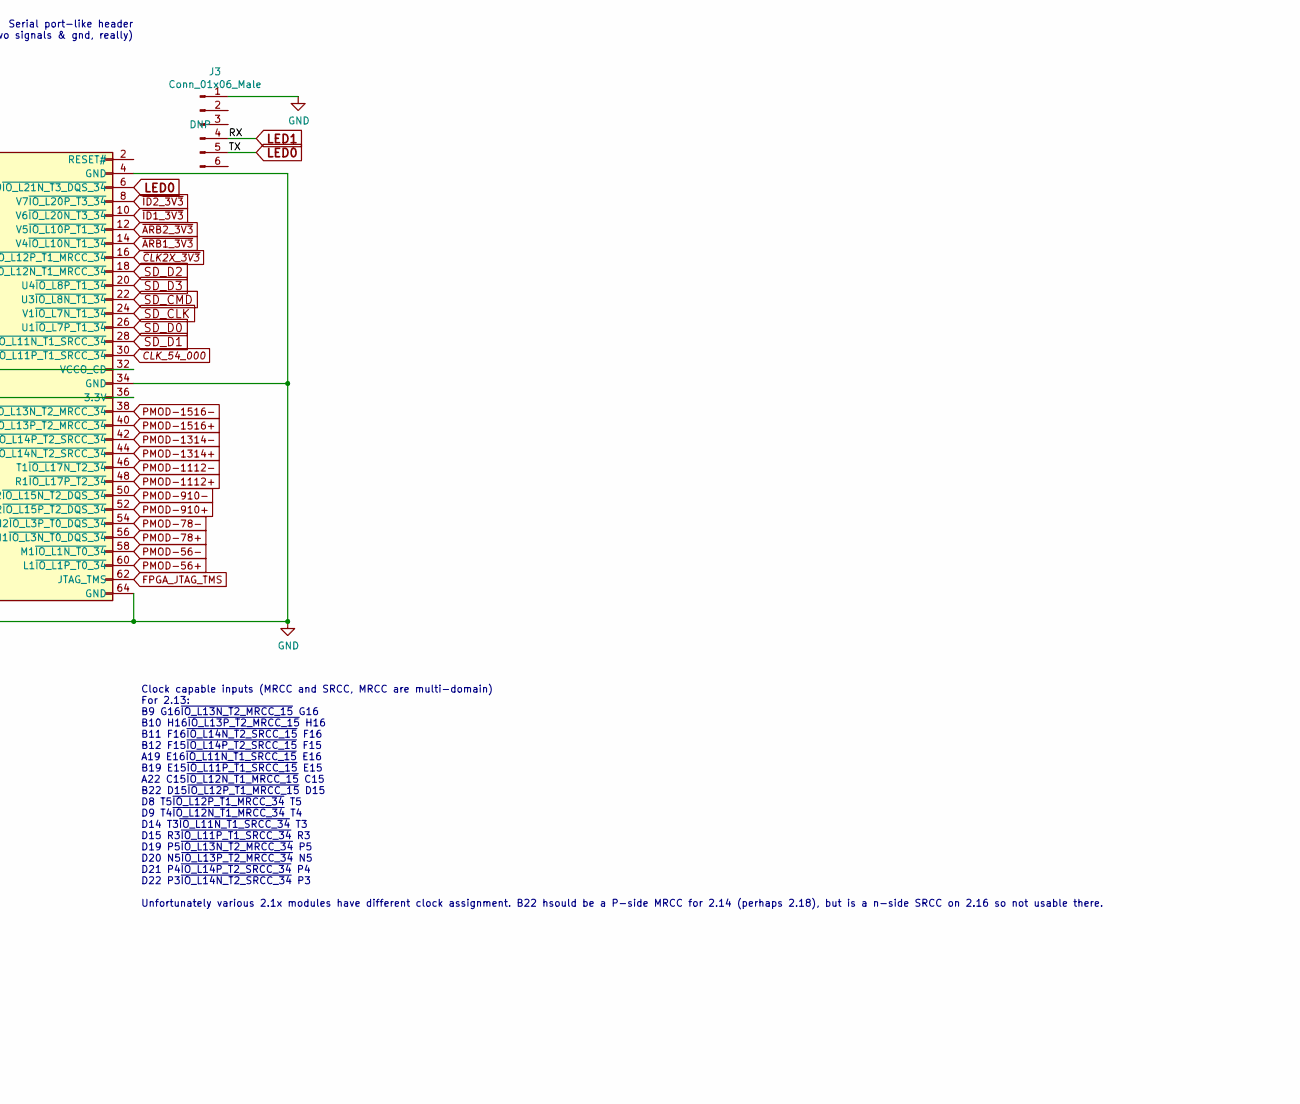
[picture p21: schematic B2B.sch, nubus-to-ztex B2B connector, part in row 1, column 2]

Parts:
C1, C2: 100nF; C_0603_1608Metric; MPN CC0603KRX7R9BB104; Mouser 603-CC603KRX7R8BB104
C3: 47uF 10V 1206; C_1206_3216Metric; MPN-ALT C2012X5R1A476MTJ00E
D1, D2: RED Led 0603; LED_0603_1608Metric; MPN KT-0603R
D3: BLUE Led 0603; LED_0603_1608Metric; MPN 19-217/BHC-ZL1M2RY/3T
J1: 87831-1420 (2x7 M 2mm); PinHeader_2x07_P2.00mm_Vertical_For_SeeedStudio; MPN 87831-1420
J3: Conn_01x06_Male; PinHeader_1x06_P2.54mm_Horizontal_For_SeeedStudio
JAB1: 77313-101-64LF (2x32 M 2.54mm); PinHeader_2x32_P2.54mm_Vertical_For_SeeedStudio; MPN (Molex) 10-89-7642
JCD1: 77313-101-64LF (2x32 M 2.54mm); PinHeader_2x32_P2.54mm_Vertical_For_SeeedStudio; MPN (Molex) 10-89-7642
R1, R2, R3: 560; R_0603_1608Metric; MPN 0603WAF5600T5E

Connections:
+3V3: C1.1, C2.1, JAB1.29 (3.3V), JAB1.30 (3.3V), JAB1.33 (VCCO_AB), JAB1.34 (VCCO_AB), JCD1.31 (VCCO_CD), JCD1.32 (VCCO_CD), JCD1.35 (3.3V), JCD1.36 (3.3V), R3.1; also elsewhere on the board
+5V: C3.1, JAB1.1 (VIN), JAB1.2 (VIN); also elsewhere on the board
/B2B/JTAG_VIO: J1.2, JAB1.63 (JTAG_VIO)
ACK_o_n: JAB1.14 (H14~IO_L15P_T2_DQS_15); also elsewhere on the board
ACK_oe_n: JAB1.12 (J13~IO_L17N_T2_A25_15); also elsewhere on the board
ARB0_o_n: JAB1.13 (J14~IO_L19P_T3_A22_15); also elsewhere on the board
ARB1_o_n: JAB1.18 (G16~IO_L13N_T2_MRCC_15); also elsewhere on the board
ARB2_o_n: JAB1.16 (G14~IO_L15N_T2_DQS_ADV_B_15); also elsewhere on the board
ARB3_o_n: JAB1.15 (H17~IO_L18P_T2_A24_15); also elsewhere on the board
CLK_54_000: JCD1.30 (R3~IO_L11P_T1_SRCC_34); also elsewhere on the board
FPGA_JTAG_TCK: J1.6, JAB1.62 (JTAG_TCK)
FPGA_JTAG_TDI: J1.10, JAB1.61 (JTAG_TDI)
FPGA_JTAG_TDO: J1.8, JCD1.61 (JTAG_TDO)
FPGA_JTAG_TMS: J1.4, JCD1.62 (JTAG_TMS)
GND: C1.2, C2.2, C3.2, D1.1 (K), D2.1 (K), D3.1 (K), J1.1, J1.3, J1.5, J1.7, J1.9, J1.11, J1.13, J3.1, JAB1.3 (GND), JAB1.4 (GND), JAB1.31 (GND), JAB1.32 (GND), JAB1.64 (GND), JCD1.3 (GND), JCD1.4 (GND), JCD1.33 (GND), JCD1.34 (GND), JCD1.63 (GND), JCD1.64 (GND); also elsewhere on the board
HDMI_CEC_A: JCD1.43 (L5~IO_L6N_T0_VREF_34); also elsewhere on the board
HDMI_CLK+: JCD1.47 (M4~IO_L16P_T2_34); also elsewhere on the board
HDMI_CLK-: JCD1.45 (N4~IO_L16N_T2_34); also elsewhere on the board
HDMI_D0+: JCD1.49 (M3~IO_L4P_T0_34); also elsewhere on the board
HDMI_D0-: JCD1.51 (M2~IO_L4N_T0_34); also elsewhere on the board
HDMI_D1+: JCD1.53 (K5~IO_L5P_T0_34); also elsewhere on the board
HDMI_D1-: JCD1.55 (L4~IO_L5N_T0_34); also elsewhere on the board
HDMI_D2+: JCD1.59 (K3~IO_L2P_T0_34); also elsewhere on the board
HDMI_D2-: JCD1.57 (L3~IO_L2N_T0_34); also elsewhere on the board
HDMI_HPD_A: JCD1.37 (N6~IO_L18N_T2_34); also elsewhere on the board
HDMI_SCL_A: JCD1.41 (L6~IO_L6P_T0_34); also elsewhere on the board
HDMI_SDA_A: JCD1.39 (M6~IO_L18P_T2_34); also elsewhere on the board
LED0: J3.5, JCD1.6 (V9~IO_L21N_T3_DQS_34), R1.1
LED1: J3.4, JCD1.5 (U9~IO_L21P_T3_DQS_34), R2.1
NUBUS_AD_DIR: JAB1.17 (G17~IO_L18N_T2_A23_15); also elsewhere on the board
NUBUS_OE: JAB1.27 (G13~IO_0_15); also elsewhere on the board
unnamed: D1.2 (A), R1.2
unnamed: D2.2 (A), R2.2
unnamed: D3.2 (A), R3.2
PMOD-56+: JCD1.60 (L1~IO_L1P_T0_34); also elsewhere on the board
PMOD-56-: JCD1.58 (M1~IO_L1N_T0_34); also elsewhere on the board
PMOD-78+: JCD1.56 (N1~IO_L3N_T0_DQS_34); also elsewhere on the board
PMOD-78-: JCD1.54 (N2~IO_L3P_T0_DQS_34); also elsewhere on the board
PMOD-910+: JCD1.52 (P2~IO_L15P_T2_DQS_34); also elsewhere on the board
PMOD-910-: JCD1.50 (R2~IO_L15N_T2_DQS_34); also elsewhere on the board
PMOD-1112+: JCD1.48 (R1~IO_L17P_T2_34); also elsewhere on the board
PMOD-1112-: JCD1.46 (T1~IO_L17N_T2_34); also elsewhere on the board
PMOD-1314+: JCD1.44 (P3~IO_L14N_T2_SRCC_34); also elsewhere on the board
PMOD-1314-: JCD1.42 (P4~IO_L14P_T2_SRCC_34); also elsewhere on the board
PMOD-1516+: JCD1.40 (N5~IO_L13P_T2_MRCC_34); also elsewhere on the board
PMOD-1516-: JCD1.38 (P5~IO_L13N_T2_MRCC_34); also elsewhere on the board
RQST_o_n: JAB1.10 (K13~IO_L17P_T2_A26_15); also elsewhere on the board
SD_CLK: JCD1.24 (V1~IO_L7N_T1_34); also elsewhere on the board
SD_CMD: JCD1.22 (U3~IO_L8N_T1_34); also elsewhere on the board
SD_D0: JCD1.26 (U1~IO_L7P_T1_34); also elsewhere on the board
SD_D1: JCD1.28 (T3~IO_L11N_T1_SRCC_34); also elsewhere on the board
SD_D2: JCD1.18 (T4~IO_L12N_T1_MRCC_34); also elsewhere on the board
SD_D3: JCD1.20 (U4~IO_L8P_T1_34); also elsewhere on the board
START_o_n: JAB1.11 (H15~IO_L19N_T3_A21_VREF_15); also elsewhere on the board
START_oe_n: JAB1.9 (J15~IO_L24N_T3_RS0_15); also elsewhere on the board
TM0_n_o: JCD1.19 (T6~IO_L23N_T3_34); also elsewhere on the board
TM1_n_o: JCD1.17 (R7~IO_L23P_T3_34); also elsewhere on the board
TM2_o_n: JCD1.23 (R5~IO_L19N_T3_VREF_34); also elsewhere on the board
TM2_oe_n: JCD1.21 (R6~IO_L19P_T3_34); also elsewhere on the board
TMx_oe_n: JCD1.15 (R8~IO_L24P_T3_34); also elsewhere on the board
USBH0_D+: JAB1.59 (B11~IO_L4P_T0_15); also elsewhere on the board
USBH0_D-: JAB1.60 (A11~IO_L4N_T0_15); also elsewhere on the board
~ACK_3V3: JAB1.8 (J17~IO_L23P_T3_FOE_B_15); also elsewhere on the board
~AD0_3V3: JAB1.58 (A13~IO_L9P_T1_DQS_AD3P_15); also elsewhere on the board
~AD1_3V3: JAB1.57 (A14~IO_L9N_T1_DQS_AD3N_15); also elsewhere on the board
~AD2_3V3: JAB1.56 (C12~IO_L3P_T0_DQS_AD1P_15); also elsewhere on the board
~AD3_3V3: JAB1.55 (B12~IO_L3N_T0_DQS_AD1N_15); also elsewhere on the board
~AD4_3V3: JAB1.54 (B13~IO_L2P_T0_AD8P_15); also elsewhere on the board
~AD5_3V3: JAB1.53 (B14~IO_L2N_T0_AD8N_15); also elsewhere on the board
~AD6_3V3: JAB1.52 (A15~IO_L8P_T1_AD10P_15); also elsewhere on the board
~AD7_3V3: JAB1.51 (A16~IO_L8N_T1_AD10N_15); also elsewhere on the board
~AD8_3V3: JAB1.50 (D12~IO_L6P_T0_15); also elsewhere on the board
~AD9_3V3: JAB1.49 (D13~IO_L6N_T0_VREF_15); also elsewhere on the board
~AD10_3V3: JAB1.48 (D14~IO_L1P_T0_AD0P_15); also elsewhere on the board
~AD11_3V3: JAB1.47 (C14~IO_L1N_T0_AD0N_15); also elsewhere on the board
~AD12_3V3: JAB1.46 (B16~IO_L7P_T1_AD2P_15); also elsewhere on the board
~AD13_3V3: JAB1.45 (B17~IO_L7N_T1_AD2N_15); also elsewhere on the board
~AD14_3V3: JAB1.44 (D15~IO_L12P_T1_MRCC_15); also elsewhere on the board
~AD15_3V3: JAB1.43 (C15~IO_L12N_T1_MRCC_15); also elsewhere on the board
~AD16_3V3: JAB1.42 (B18~IO_L10P_T1_AD11P_15); also elsewhere on the board
~AD17_3V3: JAB1.41 (A18~IO_L10N_T1_AD11N_15); also elsewhere on the board
~AD18_3V3: JAB1.40 (C16~IO_L20P_T3_A20_15); also elsewhere on the board
~AD19_3V3: JAB1.39 (C17~IO_L20N_T3_A19_15); also elsewhere on the board
~AD20_3V3: JAB1.38 (E15~IO_L11P_T1_SRCC_15); also elsewhere on the board
~AD21_3V3: JAB1.37 (E16~IO_L11N_T1_SRCC_15); also elsewhere on the board
~AD22_3V3: JAB1.36 (F14~IO_L5N_T0_AD9N_15); also elsewhere on the board
~AD23_3V3: JAB1.35 (F13~IO_L5P_T0_AD9P_15); also elsewhere on the board
~AD24_3V3: JAB1.28 (D17~IO_L16N_T2_A27_15); also elsewhere on the board
~AD25_3V3: JAB1.25 (D18~IO_L21N_T3_DQS_A18_15); also elsewhere on the board
~AD26_3V3: JAB1.26 (E17~IO_L16P_T2_A28_15); also elsewhere on the board
~AD27_3V3: JAB1.23 (E18~IO_L21P_T3_DQS_15); also elsewhere on the board
~AD28_3V3: JAB1.24 (F15~IO_L14P_T2_SRCC_15); also elsewhere on the board
~AD29_3V3: JAB1.21 (F18~IO_L22N_T3_A16_15); also elsewhere on the board
~AD30_3V3: JAB1.22 (F16~IO_L14N_T2_SRCC_15); also elsewhere on the board
~AD31_3V3: JAB1.19 (G18~IO_L22P_T3_A17_15); also elsewhere on the board
~ARB0_3V3: JCD1.13 (T8~IO_L24N_T3_34); also elsewhere on the board
~ARB1_3V3: JCD1.14 (V4~IO_L10N_T1_34); also elsewhere on the board
~ARB2_3V3: JCD1.12 (V5~IO_L10P_T1_34); also elsewhere on the board
~ARB3_3V3: JCD1.11 (U6~IO_L22N_T3_34); also elsewhere on the board
~CLK2X_3V3: JCD1.16 (T5~IO_L12P_T1_MRCC_34); also elsewhere on the board
~CLK_3V3: JAB1.20 (H16~IO_L13P_T2_MRCC_15); also elsewhere on the board
~ID0_3V3: JCD1.9 (U7~IO_L22P_T3_34); also elsewhere on the board
~ID1_3V3: JCD1.10 (V6~IO_L20N_T3_34); also elsewhere on the board
~ID2_3V3: JCD1.8 (V7~IO_L20P_T3_34); also elsewhere on the board
~NMRQ_3V3: JAB1.5 (K16~IO_25_15); also elsewhere on the board
~RESET_3V3: JCD1.7 (U8~IO_25_34); also elsewhere on the board
~RQST_3V3: JAB1.6 (J18~IO_L23N_T3_FWE_B_15); also elsewhere on the board
~START_3V3: JAB1.7 (K15~IO_L24P_T3_RS1_15); also elsewhere on the board
~TM0_3V3: JCD1.27 (U2~IO_L9P_T1_DQS_34); also elsewhere on the board
~TM1_3V3: JCD1.25 (V2~IO_L9N_T1_DQS_34); also elsewhere on the board
~TM2_3V3: JCD1.29 (K6~IO_0_34); also elsewhere on the board

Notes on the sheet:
Clock capable inputs (MRCC and SRCC, MRCC are multi-domain) For 2.13: B9 G16~IO_L13N_T2_MRCC_15 G16 B10 H16~IO_L13P_T2_MRCC_15 H16 B11 F16~IO_L14N_T2_SRCC_15 F16 B12 F15~IO_L14P_T2_SRCC_15 F15 A19 E16~IO_L11N_T1_SRCC_15 E16 B19 E15~IO_L11P_T1_SRCC_15 E15 A22 C15~IO_L12N_T1_MRCC_15 C15 B22 D15~IO_L1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
PGND
HALT
User LEDS
Power Signal
Close to pwr output pins (3.3V / VCCO_{AB,CD})
Serial port-like header (just two signals & gnd, really)
Close to VIN pins on AB
Molex 10-89-7642 a.k.a. A-70280-0072, with dimension 11.1 (total), 6.1 (mating) & 2.72 (solder), Hole diameter 1.02 XKB X6521WV-2x32H-C30D60 is 11.5/6/3, H1.02 Amphenol 77313-824-64LF is 12.2/6.75/2.9, H1.02 Amphenol 77313-818-64LF is 11.43/5.84/3.05, H1.02 Amphenol 77313-101-64LF is 10.8/5.84/2.41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
The two LED signals are also connected to the serial connector for debugging purposes

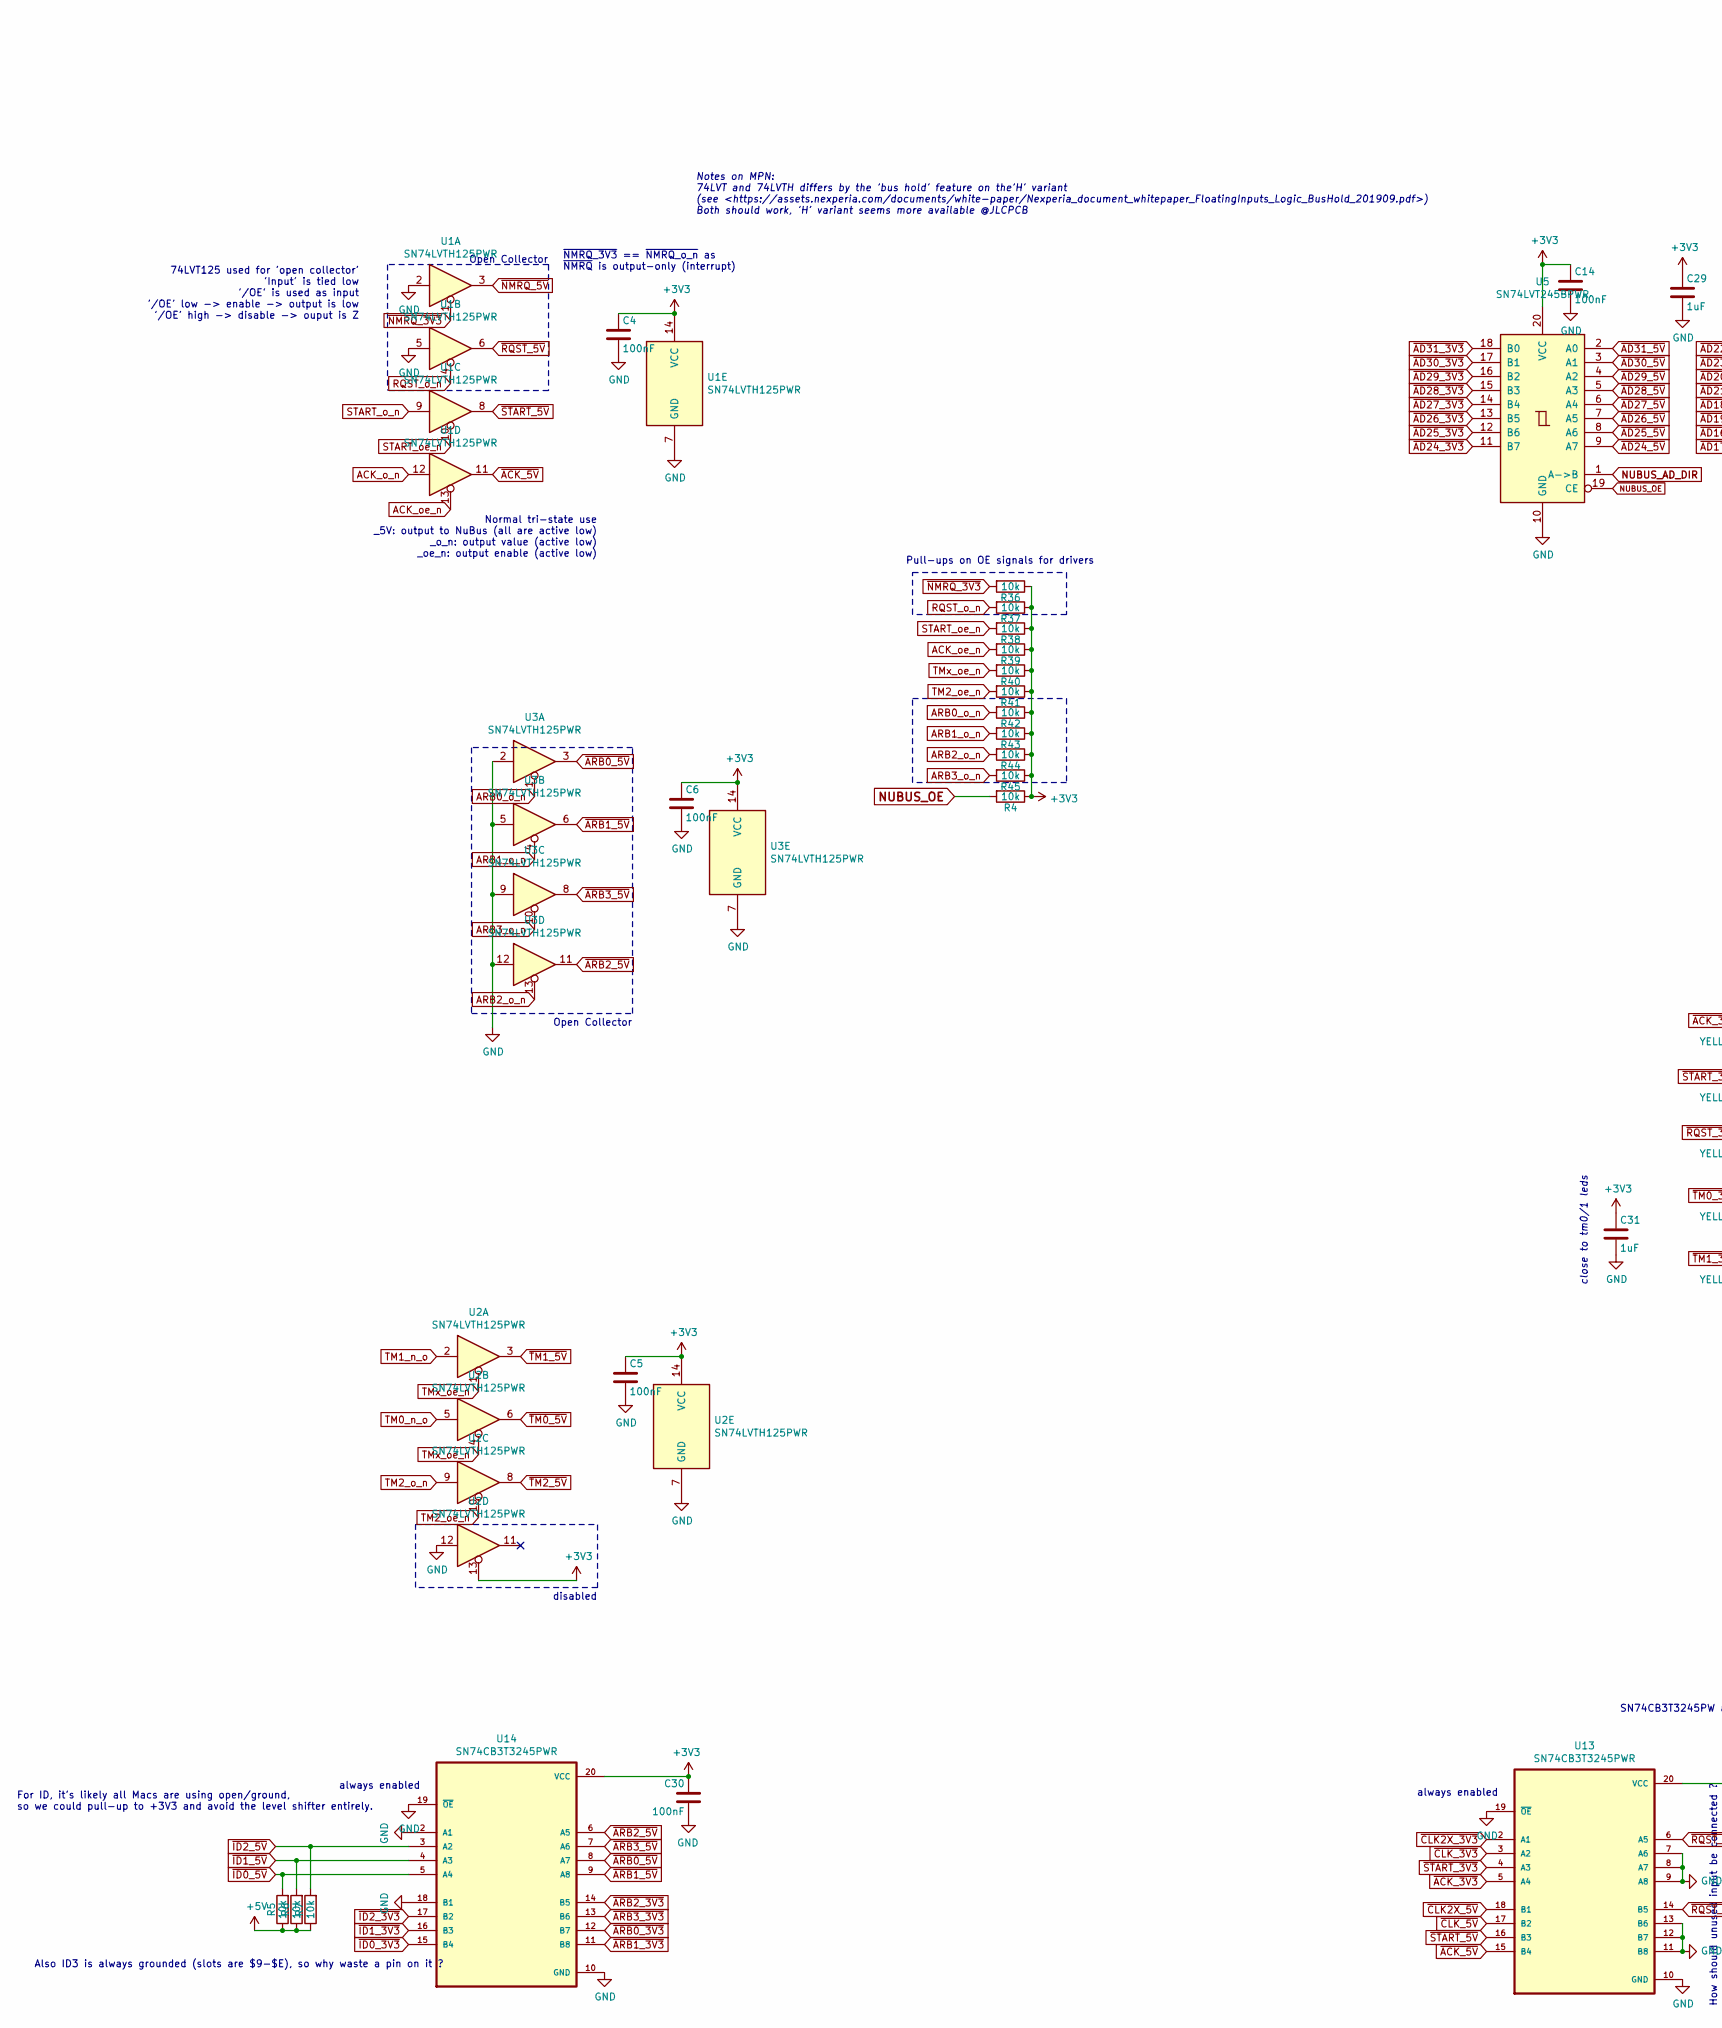
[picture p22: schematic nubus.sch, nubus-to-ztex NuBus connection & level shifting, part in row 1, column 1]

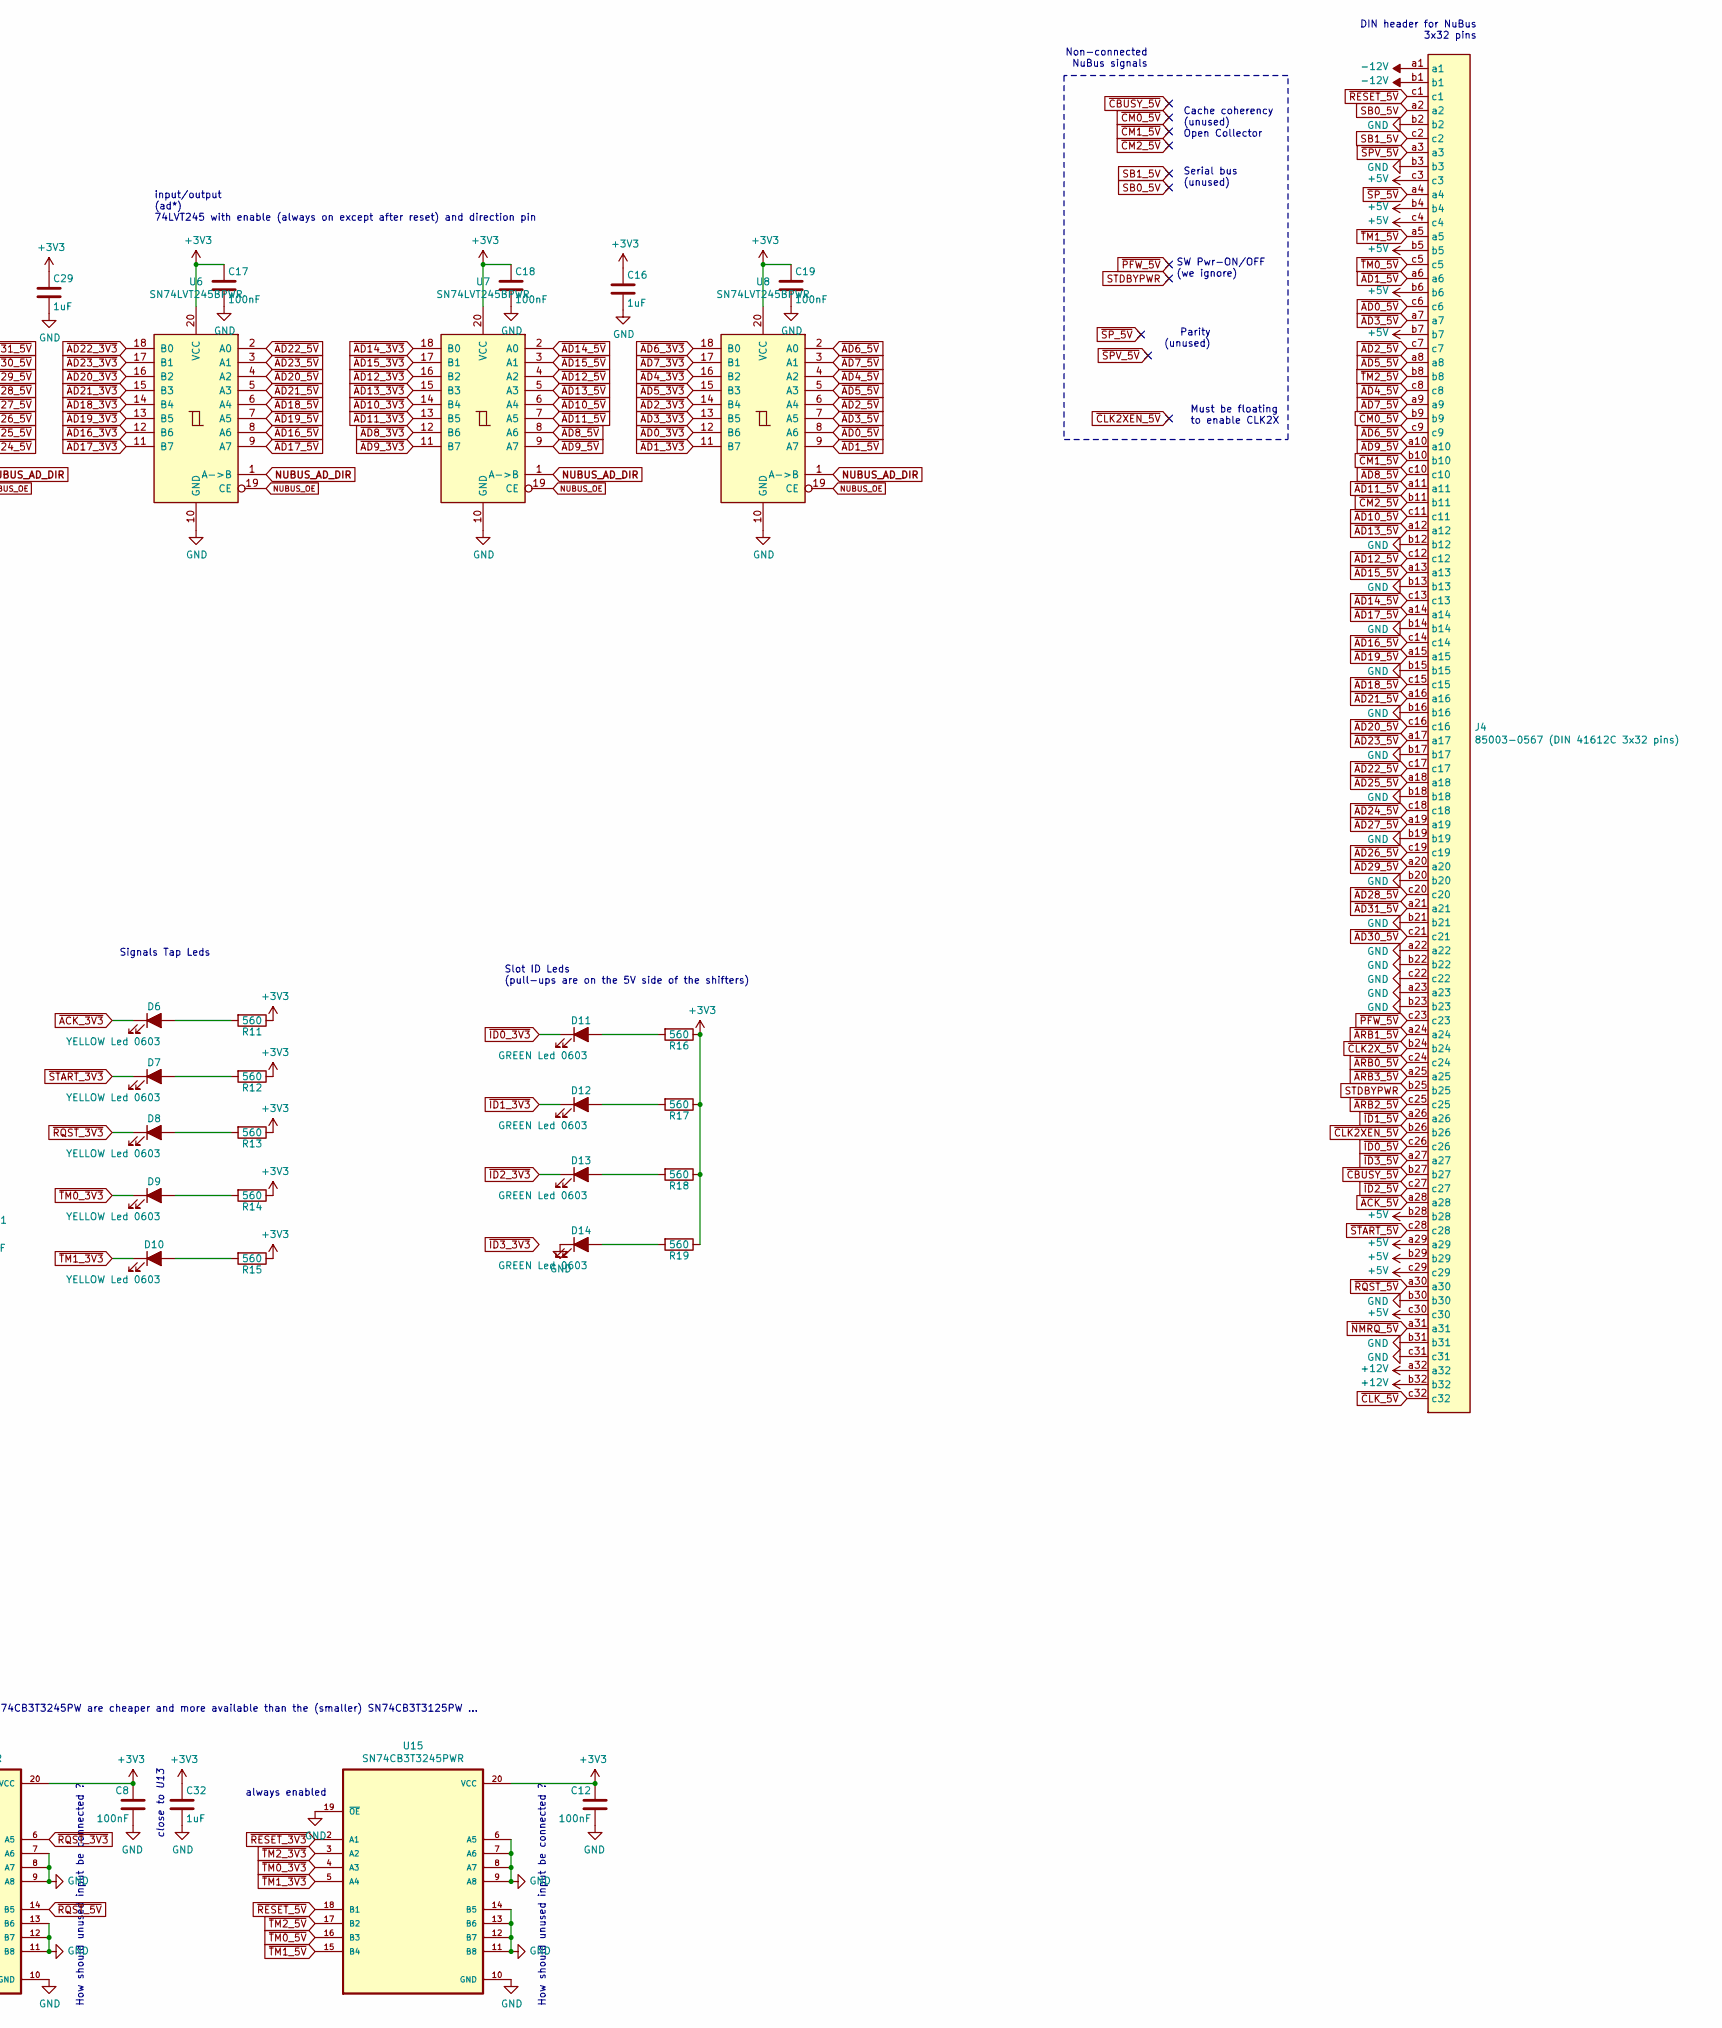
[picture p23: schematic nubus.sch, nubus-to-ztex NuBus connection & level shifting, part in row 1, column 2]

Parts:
C4, C5, C6, C8, C12, C14, C17, C18, C19, C30: 100nF; C_0603_1608Metric; MPN CC0603KRX7R9BB104; Mouser 603-CC603KRX7R8BB104
C16, C29, C31, C32: 1uF; C_0603_1608Metric; MPN CL10A105KB8NNNC
D6, D7, D8, D9, D10: YELLOW Led 0603; LED_0603_1608Metric; MPN 19-213/Y2C-CQ2R2L/3T(CY)
D11, D12, D13, D14: GREEN Led 0603; LED_0603_1608Metric; MPN 19-217/GHC-YR1S2/3T
J4: 85003-0567 (DIN 41612C 3x32 pins); DIN41612_C_3x32_Male_Horizontal_THT; MPN (Molex) 85003-0567
R4, R5, R6, R7, R36, R37, R38, R39, R40, R41, R42, R43, R44, R45: 10k; R_0603_1608Metric; MPN 0603WAF1002T5E
R11, R12, R13, R14, R15, R16, R17, R18, R19: 560; R_0603_1608Metric; MPN 0603WAF5600T5E
U1, U2, U3: SN74LVTH125PWR; TSSOP-14_4.4x5mm_P0.65mm; MPN SN74LVTH125PWR
U5, U6, U7, U8: SN74LVT245BPWR; TSSOP-20_4.4x6.5mm_P0.65mm_ForSeeedStudio; MPN - ALT 74LVT245BPW,118
U13, U14, U15: SN74CB3T3245PWR; TSSOP-20_4.4x6.5mm_P0.65mm_ForSeeedStudio; MPN SN74CB3T3245PWR

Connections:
+3V3: C4.1, C5.1, C6.1, C8.1, C12.1, C14.1, C16.1, C17.1, C18.1, C19.1, C29.1, C30.1, C31.1, C32.1, R4.1, R11.1, R12.1, R13.1, R14.1, R15.1, R16.1, R17.1, R18.1, R19.1, R36.1, R37.1, R38.1, R39.1, R40.1, R41.1, R42.1, R43.1, R44.1, R45.1, U1.14 (VCC), U2.13, U2.14 (VCC), U3.14 (VCC), U5.20 (VCC), U6.20 (VCC), U7.20 (VCC), U8.20 (VCC), U13.20 (VCC), U14.20 (VCC), U15.20 (VCC); also elsewhere on the board
+5V: J4.a29, J4.b4, J4.b5, J4.b6, J4.b7, J4.b28, J4.b29, J4.c3, J4.c4, J4.c29, J4.c30, R5.1, R6.1, R7.1; also elsewhere on the board
+12V: J4.a32, J4.b32
-12V: J4.a1, J4.b1
ACK_o_n: U1.12; also elsewhere on the board
ACK_oe_n: R39.2, U1.13; also elsewhere on the board
ARB0_o_n: R42.2, U3.1; also elsewhere on the board
ARB1_o_n: R43.2, U3.4; also elsewhere on the board
ARB2_o_n: R44.2, U3.13; also elsewhere on the board
ARB3_o_n: R45.2, U3.10; also elsewhere on the board
GND: C4.2, C5.2, C6.2, C8.2, C12.2, C14.2, C16.2, C17.2, C18.2, C19.2, C29.2, C30.2, C31.2, C32.2, D14.1 (K), J4.a22, J4.a23, J4.b2, J4.b3, J4.b12, J4.b13, J4.b14, J4.b15, J4.b16, J4.b17, J4.b18, J4.b19, J4.b20, J4.b21, J4.b22, J4.b23, J4.b30, J4.b31, J4.c22, J4.c31, U1.2, U1.5, U1.7 (GND), U2.7 (GND), U2.12, U3.2, U3.5, U3.7 (GND), U3.9, U3.12, U5.10 (GND), U6.10 (GND), U7.10 (GND), U8.10 (GND), U13.7 (A6), U13.8 (A7), U13.9 (A8), U13.10 (GND), U13.11 (B8), U13.12 (B7), U13.13 (B6), U13.19 (~OE), U14.2 (A1), U14.10 (GND), U14.18 (B1), U14.19 (~OE), U15.6 (A5), U15.7 (A6), U15.8 (A7), U15.9 (A8), U15.10 (GND), U15.11 (B8), U15.12 (B7), U15.13 (B6), U15.14 (B5), U15.19 (~OE); also elsewhere on the board
NUBUS_AD_DIR: U5.1 (A->B), U6.1 (A->B), U7.1 (A->B), U8.1 (A->B); also elsewhere on the board
NUBUS_OE: R4.2, U5.19 (CE), U6.19 (CE), U7.19 (CE), U8.19 (CE); also elsewhere on the board
unnamed: D6.2 (A), R11.2
unnamed: D7.2 (A), R12.2
unnamed: D8.2 (A), R13.2
unnamed: D9.2 (A), R14.2
unnamed: D10.2 (A), R15.2
unnamed: D11.2 (A), R16.2
unnamed: D12.2 (A), R17.2
unnamed: D13.2 (A), R18.2
unnamed: D14.2 (A), R19.2
RQST_o_n: R37.2, U1.4; also elsewhere on the board
SB0_5V: J4.a2
SB1_5V: J4.c2
START_o_n: U1.9; also elsewhere on the board
START_oe_n: R38.2, U1.10; also elsewhere on the board
STDBYPWR: J4.b25
TM0_n_o: U2.5; also elsewhere on the board
TM1_n_o: U2.2; also elsewhere on the board
TM2_o_n: U2.9; also elsewhere on the board
TM2_oe_n: R41.2, U2.10; also elsewhere on the board
TMx_oe_n: R40.2, U2.1, U2.4; also elsewhere on the board
~ACK_3V3: D6.1 (K), U13.5 (A4); also elsewhere on the board
~ACK_5V: J4.a28, U1.11, U13.15 (B4)
~AD0_3V3: U8.12 (B6); also elsewhere on the board
~AD0_5V: J4.c6, U8.8 (A6)
~AD1_3V3: U8.11 (B7); also elsewhere on the board
~AD1_5V: J4.a6, U8.9 (A7)
~AD2_3V3: U8.14 (B4); also elsewhere on the board
~AD2_5V: J4.c7, U8.6 (A4)
~AD3_3V3: U8.13 (B5); also elsewhere on the board
~AD3_5V: J4.a7, U8.7 (A5)
~AD4_3V3: U8.16 (B2); also elsewhere on the board
~AD4_5V: J4.c8, U8.4 (A2)
~AD5_3V3: U8.15 (B3); also elsewhere on the board
~AD5_5V: J4.a8, U8.5 (A3)
~AD6_3V3: U8.18 (B0); also elsewhere on the board
~AD6_5V: J4.c9, U8.2 (A0)
~AD7_3V3: U8.17 (B1); also elsewhere on the board
~AD7_5V: J4.a9, U8.3 (A1)
~AD8_3V3: U7.12 (B6); also elsewhere on the board
~AD8_5V: J4.c10, U7.8 (A6)
~AD9_3V3: U7.11 (B7); also elsewhere on the board
~AD9_5V: J4.a10, U7.9 (A7)
~AD10_3V3: U7.14 (B4); also elsewhere on the board
~AD10_5V: J4.c11, U7.6 (A4)
~AD11_3V3: U7.13 (B5); also elsewhere on the board
~AD11_5V: J4.a11, U7.7 (A5)
~AD12_3V3: U7.16 (B2); also elsewhere on the board
~AD12_5V: J4.c12, U7.4 (A2)
~AD13_3V3: U7.15 (B3); also elsewhere on the board
~AD13_5V: J4.a12, U7.5 (A3)
~AD14_3V3: U7.18 (B0); also elsewhere on the board
~AD14_5V: J4.c13, U7.2 (A0)
~AD15_3V3: U7.17 (B1); also elsewhere on the board
~AD15_5V: J4.a13, U7.3 (A1)
~AD16_3V3: U6.12 (B6); also elsewhere on the board
~AD16_5V: J4.c14, U6.8 (A6)
~AD17_3V3: U6.11 (B7); also elsewhere on the board
~AD17_5V: J4.a14, U6.9 (A7)
~AD18_3V3: U6.14 (B4); also elsewhere on the board
~AD18_5V: J4.c15, U6.6 (A4)
~AD19_3V3: U6.13 (B5); also elsewhere on the board
~AD19_5V: J4.a15, U6.7 (A5)
~AD20_3V3: U6.16 (B2); also elsewhere on the board
~AD20_5V: J4.c16, U6.4 (A2)
~AD21_3V3: U6.15 (B3); also elsewhere on the board
~AD21_5V: J4.a16, U6.5 (A3)
~AD22_3V3: U6.18 (B0); also elsewhere on the board
~AD22_5V: J4.c17, U6.2 (A0)
~AD23_3V3: U6.17 (B1); also elsewhere on the board
~AD23_5V: J4.a17, U6.3 (A1)
~AD24_3V3: U5.11 (B7); also elsewhere on the board
~AD24_5V: J4.c18, U5.9 (A7)
~AD25_3V3: U5.12 (B6); also elsewhere on the board
~AD25_5V: J4.a18, U5.8 (A6)
~AD26_3V3: U5.13 (B5); also elsewhere on the board
~AD26_5V: J4.c19, U5.7 (A5)
~AD27_3V3: U5.14 (B4); also elsewhere on the board
~AD27_5V: J4.a19, U5.6 (A4)
~AD28_3V3: U5.15 (B3); also elsewhere on the board
~AD28_5V: J4.c20, U5.5 (A3)
~AD29_3V3: U5.16 (B2); also elsewhere on the board
~AD29_5V: J4.a20, U5.4 (A2)
~AD30_3V3: U5.17 (B1); also elsewhere on the board
~AD30_5V: J4.c21, U5.3 (A1)
~AD31_3V3: U5.18 (B0); also elsewhere on the board
~AD31_5V: J4.a21, U5.2 (A0)
~ARB0_3V3: U14.12 (B7); also elsewhere on the board
~ARB0_5V: J4.c24, U3.3, U14.8 (A7)
~ARB1_3V3: U14.11 (B8); also elsewhere on the board
~ARB1_5V: J4.a24, U3.6, U14.9 (A8)
~ARB2_3V3: U14.14 (B5); also elsewhere on the board
~ARB2_5V: J4.c25, U3.11, U14.6 (A5)
~ARB3_3V3: U14.13 (B6); also elsewhere on the board
~ARB3_5V: J4.a25, U3.8, U14.7 (A6)
~CBUSY_5V: J4.b27
~CLK2XEN_5V: J4.b26
~CLK2X_3V3: U13.2 (A1); also elsewhere on the board
~CLK2X_5V: J4.b24, U13.18 (B1)
~CLK_3V3: U13.3 (A2); also elsewhere on the board
~CLK_5V: J4.c32, U13.17 (B2)
~CM0_5V: J4.b9
~CM1_5V: J4.b10
~CM2_5V: J4.b11
~ID0_3V3: D11.1 (K), U14.15 (B4); also elsewhere on the board
~ID0_5V: J4.c26, R5.2, U14.5 (A4)
~ID1_3V3: D12.1 (K), U14.16 (B3); also elsewhere on the board
~ID1_5V: J4.a26, R6.2, U14.4 (A3)
~ID2_3V3: D13.1 (K), U14.17 (B2); also elsewhere on the board
~ID2_5V: J4.c27, R7.2, U14.3 (A2)
~ID3_5V: J4.a27
~NMRQ_3V3: R36.2, U1.1; also elsewhere on the board
~NMRQ_5V: J4.a31, U1.3
~PFW_5V: J4.c23
~RESET_3V3: U15.2 (A1); also elsewhere on the board
~RESET_5V: J4.c1, U15.18 (B1)
~RQST_3V3: D8.1 (K), U13.6 (A5); also elsewhere on the board
~RQST_5V: J4.a30, U1.6, U13.14 (B5)
~SPV_5V: J4.a3
~SP_5V: J4.a4
~START_3V3: D7.1 (K), U13.4 (A3); also elsewhere on the board
~START_5V: J4.c28, U1.8, U13.16 (B3)
~TM0_3V3: D9.1 (K), U15.4 (A3); also elsewhere on the board
~TM0_5V: J4.c5, U2.6, U15.16 (B3)
~TM1_3V3: D10.1 (K), U15.5 (A4); also elsewhere on the board
~TM1_5V: J4.a5, U2.3, U15.15 (B4)
~TM2_3V3: U15.3 (A2); also elsewhere on the board
~TM2_5V: J4.b8, U2.8, U15.17 (B2)

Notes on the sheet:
Cache coherency (unused) Open Collector
Serial bus (unused)
Must be floating to enable CLK2X
SW Pwr-ON/OFF (we ignore)
input/output (ad*) 74LVT245 with enable (always on except after reset) and direction pin
Slot ID Leds (pull-ups are on the 5V side of the shifters)
74LVT125 used for 'open collector' 'Input' is tied low '/OE' is used as input '/OE' low -> enable -> output is low '/OE' high -> disable -> ouput is Z
Parity (unused)
Open Collector
Normal tri-state use _5V: output to NuBus (all are active low) _o_n: output value (active low) _oe_n: output enable (active low)
DIN header for NuBus 3x32 pins
Non-connected NuBus signals
disabled
Pull-ups on OE signals for drivers
always enabled
For ID, it's likely all Macs are using open/ground, so we could pull-up to +3V3 and avoid the level shifter entirely.
Signals Tap Leds
How should unused input be connected ?
SN74CB3T3245PW are cheaper and more available than the (smaller) SN74CB3T3125PW ...
~NMRQ_3V3~ == ~NMRQ_o_n~ as ~NMRQ~ is output-only (interrupt)
Also ID3 is always grounded (slots are $9-$E), so why waste a pin on it ?
Notes on MPN: 74LVT and 74LVTH differs by the 'bus hold' feature on the'H' variant (see <https://assets.nexperia.com/documents/white-paper/Nexperia_document_whitepaper_FloatingInputs_Logic_BusHold_201909.pdf>) Both should work, 'H' variant seems more available @JLCPCB
close to tm0/1 leds
close to U13

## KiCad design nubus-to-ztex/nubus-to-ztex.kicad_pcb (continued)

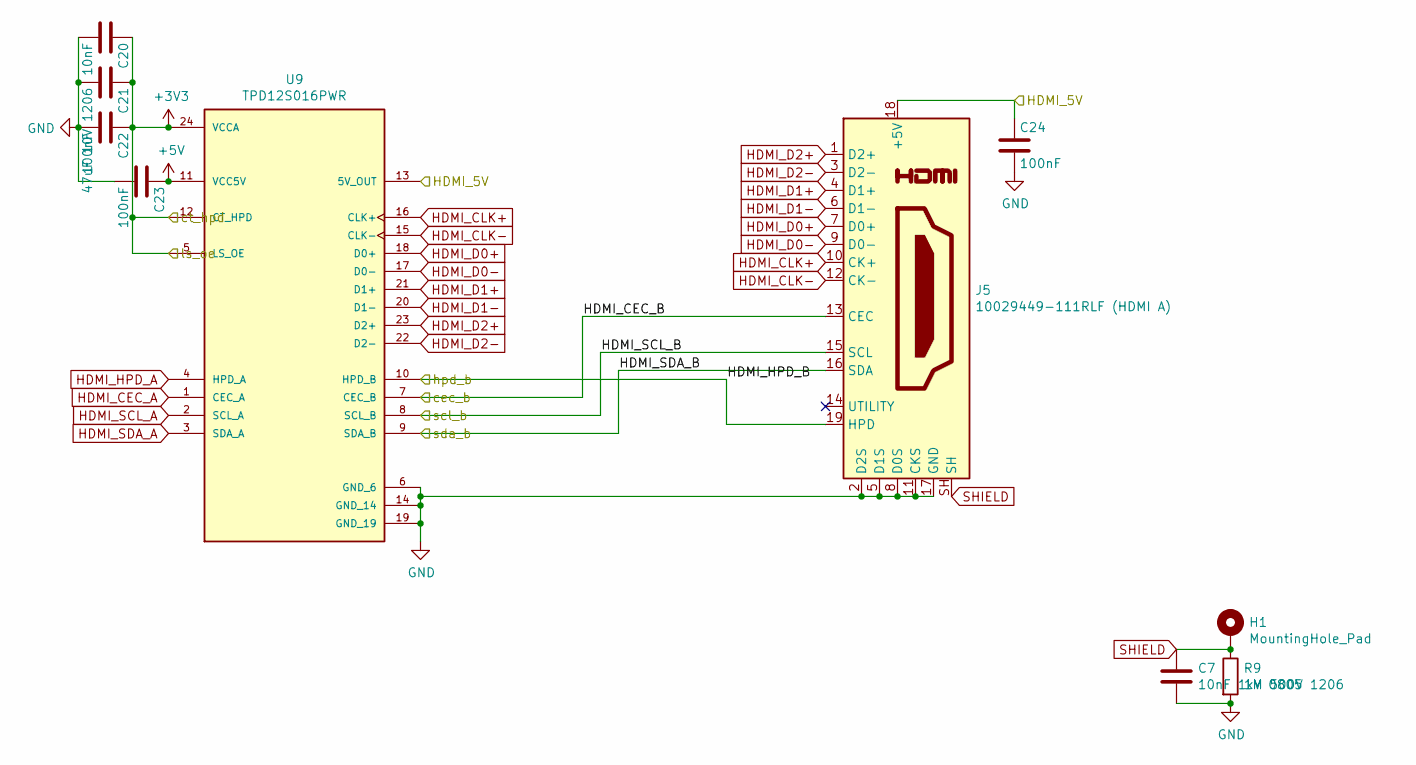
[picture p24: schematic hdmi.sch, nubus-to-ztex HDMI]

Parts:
C7: 10nF 1kV 0805; C_0805_2012Metric; MPN-ALT C0805V103KCRACTU
C20: 10nF; C_0603_1608Metric; MPN 0603B103K500NT; Mouser 603-CC603KRX7R8BB103
C21: 47uF 10V 1206; C_1206_3216Metric; MPN-ALT3 GRM21BR61A476ME15L # 10V
C22, C23, C24: 100nF; C_0603_1608Metric; MPN CC0603KRX7R9BB104; Mouser 603-CC603KRX7R8BB104
H1: MountingHole_Pad; MountingHole_2.2mm_M2_Pad
J5: 10029449-111RLF (HDMI A); HDMI_A_Amphenol_10029449-111; MPN 10029449-111RLF
R9: 1M 500V 1206; R_1206_3216Metric; MPN HR1206J1M00P05Z
U9: TPD12S016PWR; SOP65P640X120-24N; PARTREV F

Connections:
+3V3: C20.1, C21.1, C22.1, U9.5 (LS_OE), U9.12 (CT_HPD), U9.24 (VCCA); also elsewhere on the board
+5V: C23.1, U9.11 (VCC5V); also elsewhere on the board
/hdmi/HDMI_5V: C24.1, J5.18 (+5V), U9.13 (5V_OUT)
/hdmi/cec_b: J5.13 (CEC), U9.7 (CEC_B)
/hdmi/hpd_b: J5.19 (HPD), U9.10 (HPD_B)
/hdmi/scl_b: J5.15 (SCL), U9.8 (SCL_B)
/hdmi/sda_b: J5.16 (SDA), U9.9 (SDA_B)
GND: C7.2, C20.2, C21.2, C22.2, C23.2, C24.2, J5.2 (D2S), J5.5 (D1S), J5.8 (D0S), J5.11 (CKS), J5.17 (GND), R9.2, U9.6 (GND_6), U9.14 (GND_14), U9.19 (GND_19); also elsewhere on the board
HDMI_CEC_A: U9.1 (CEC_A); also elsewhere on the board
HDMI_CLK+: J5.10 (CK+), U9.16 (CLK+); also elsewhere on the board
HDMI_CLK-: J5.12 (CK-), U9.15 (CLK-); also elsewhere on the board
HDMI_D0+: J5.7 (D0+), U9.18 (D0+); also elsewhere on the board
HDMI_D0-: J5.9 (D0-), U9.17 (D0-); also elsewhere on the board
HDMI_D1+: J5.4 (D1+), U9.21 (D1+); also elsewhere on the board
HDMI_D1-: J5.6 (D1-), U9.20 (D1-); also elsewhere on the board
HDMI_D2+: J5.1 (D2+), U9.23 (D2+); also elsewhere on the board
HDMI_D2-: J5.3 (D2-), U9.22 (D2-); also elsewhere on the board
HDMI_HPD_A: U9.4 (HPD_A); also elsewhere on the board
HDMI_SCL_A: U9.2 (SCL_A); also elsewhere on the board
HDMI_SDA_A: U9.3 (SDA_A); also elsewhere on the board
SHIELD: C7.1, H1.1, J5.SH, R9.1; also elsewhere on the board

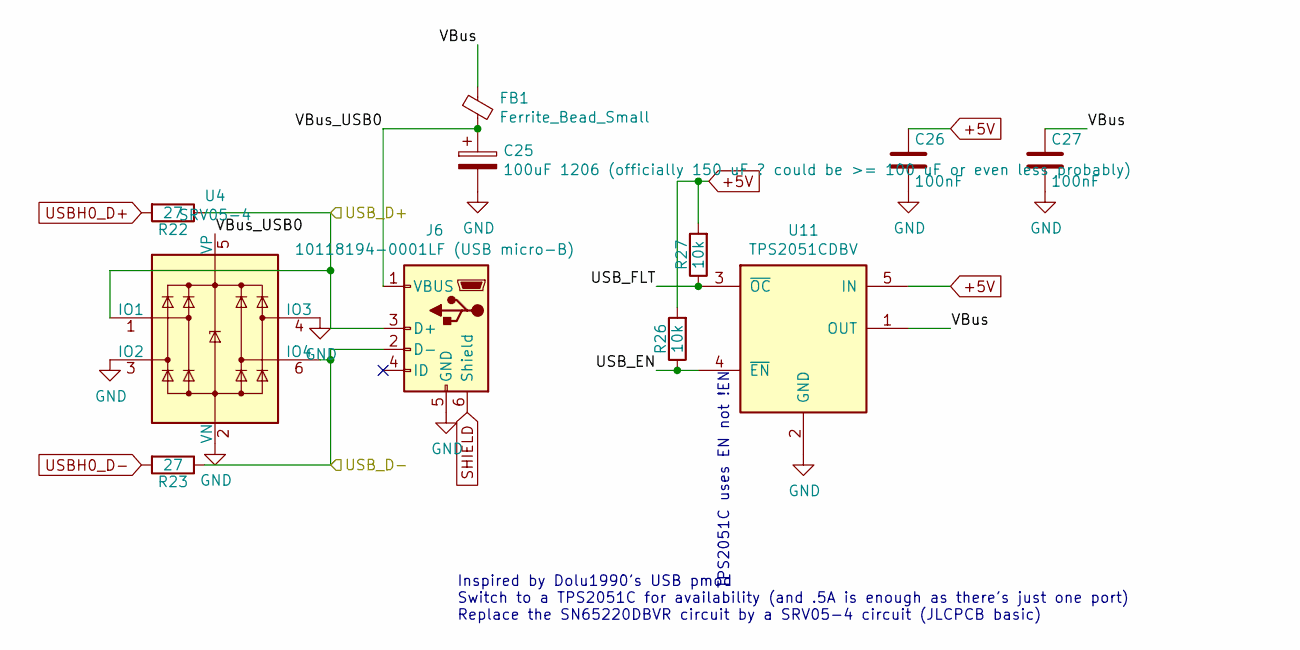
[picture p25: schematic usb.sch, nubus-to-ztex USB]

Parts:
C25: 100uF 1206 (officially 150 uF ? could be >= 100 u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; C_1206_3216Metric; MPN-ALT GRM31CR60J157ME11L
C26, C27: 100nF; C_0603_1608Metric; MPN CC0603KRX7R9BB104; Digikey ?
FB1: Ferrite_Bead_Small; L_0805_2012Metric; MPN-ALT 742792022
J6: 10118194-0001LF (USB micro-B); USB_Micro-B_Amphenol_10118194_Horizontal; MPN 10118194-0001LF
R22, R23: 27; R_0603_1608Metric; MPN 0603WAF270JT5E
R26, R27: 10k; R_0603_1608Metric; MPN 0603WAF1002T5E
U4: SRV05-4; SOT-23-6; MPN SRV05-4-P-T7
U11: TPS2051CDBV; SOT-23-5; MPN TPS2051CDBVR; Mouser No 595-TPS2051CDBVR

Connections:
+5V: C26.1, R26.2, R27.2, U11.5 (IN); also elsewhere on the board
/usb/USB_D+: J6.3 (D+), R22.1, U4.1 (IO1)
/usb/USB_D-: J6.2 (D-), R23.1, U4.6 (IO4)
/usb/USB_EN: R26.1, U11.4 (~EN)
/usb/USB_FLT: R27.1, U11.3 (~OC)
/usb/VBus: C27.1, FB1.1, U11.1 (OUT)
/usb/VBus_USB0: C25.1, FB1.2, J6.1 (VBUS), U4.5 (VP)
GND: C25.2, C26.2, C27.2, J6.5 (GND), U4.2 (VN), U4.3 (IO2), U4.4 (IO3), U11.2 (GND); also elsewhere on the board
SHIELD: J6.6 (Shield); also elsewhere on the board
USBH0_D+: R22.2; also elsewhere on the board
USBH0_D-: R23.2; also elsewhere on the board

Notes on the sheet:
Inspired by Dolu1990's USB pmod Switch to a TPS2051C for availability (and .5A is enough as there's just one port) Replace the SN65220DBVR circuit by a SRV05-4 circuit (JLCPCB basic)
TPS2051C uses EN not !EN

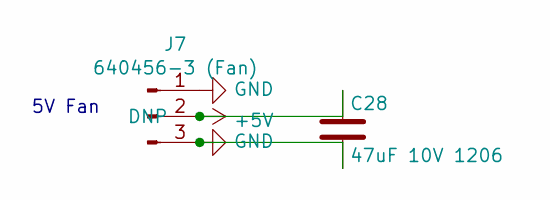
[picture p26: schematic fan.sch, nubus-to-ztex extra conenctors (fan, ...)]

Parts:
C28: 47uF 10V 1206; C_1206_3216Metric; MPN-ALT C2012X5R1A476MTJ00E
J7: 640456-3 (Fan); Molex_KK-254_AE-6410-03A_1x03_P2.54mm_Vertical; MPN-ALT 22-27-2031

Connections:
+5V: C28.1, J7.2; also elsewhere on the board
GND: C28.2, J7.1, J7.3; also elsewhere on the board

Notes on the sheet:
5V Fan

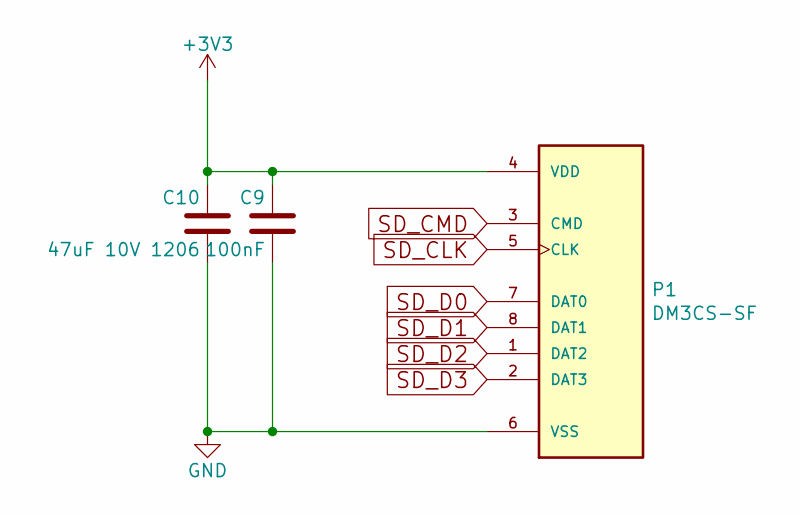
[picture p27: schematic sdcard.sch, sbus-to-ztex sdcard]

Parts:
C2: 100nF; C_0603_1608Metric; MPN CC0603KRX7R9BB104; Mouser 603-CC603KRX7R8BB104
C10: 47uF 10V 1206; C_1206_3216Metric; MPN-ALT GRM21BR60J476ME15L
P1: DM3CS-SF; HRS_DM3CS-SF; MPN DM3CS-SF

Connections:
+3V3: C2.1, C10.1, P1.4 (VDD); also elsewhere on the board
GND: C2.2, C10.2, P1.6 (VSS); also elsewhere on the board
SD_CLK: P1.5 (CLK); also elsewhere on the board
SD_CMD: P1.3 (CMD); also elsewhere on the board
SD_D0: P1.7 (DAT0); also elsewhere on the board
SD_D1: P1.8 (DAT1); also elsewhere on the board
SD_D2: P1.1 (DAT2); also elsewhere on the board
SD_D3: P1.2 (DAT3); also elsewhere on the board

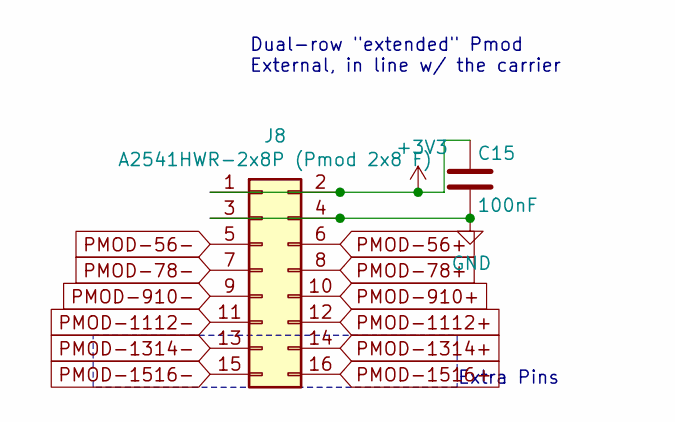
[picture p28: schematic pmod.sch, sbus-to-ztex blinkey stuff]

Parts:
C15: 100nF; C_0603_1608Metric; MPN CC0603KRX7R9BB104; Mouser 603-CC603KRX7R8BB104
J8: A2541HWR-2x8P (Pmod 2x8 F); PinSocket_2x08_P2.54mm_Horizontal_ForSeeedStudio; MPN A2541HWR-2x8P

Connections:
+3V3: C15.1, J8.1, J8.2; also elsewhere on the board
GND: C15.2, J8.3, J8.4; also elsewhere on the board
PMOD-56+: J8.6; also elsewhere on the board
PMOD-56-: J8.5; also elsewhere on the board
PMOD-78+: J8.8; also elsewhere on the board
PMOD-78-: J8.7; also elsewhere on the board
PMOD-910+: J8.10; also elsewhere on the board
PMOD-910-: J8.9; also elsewhere on the board
PMOD-1112+: J8.12; also elsewhere on the board
PMOD-1112-: J8.11; also elsewhere on the board
PMOD-1314+: J8.14; also elsewhere on the board
PMOD-1314-: J8.13; also elsewhere on the board
PMOD-1516+: J8.16; also elsewhere on the board
PMOD-1516-: J8.15; also elsewhere on the board

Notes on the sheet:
Dual-row "extended" Pmod External, in line w/ the carrier
Extra Pins

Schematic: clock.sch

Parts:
C11: 100nF; C_0603_1608Metric; MPN CC0603KRX7R9BB104; Mouser 603-CC603KRX7R8BB104
C13: 10nF; C_0603_1608Metric; MPN 0603B103K500NT; Mouser 603-CC603KRX7R8BB103
R8: 27; R_0603_1608Metric; MPN 0603WAF270JT5E
X1: ASE-xxxMHz; Oscillator_SMD_Abracon_ASE-4Pin_3.2x2.5mm; MPN SX3M54.000M20F30TNN

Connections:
+3V3: C11.1, C13.1, X1.4 (Vdd); also elsewhere on the board
CLK_54_000: R8.1; also elsewhere on the board
GND: C11.2, C13.2, X1.2 (GND); also elsewhere on the board
unnamed: R8.2, X1.3 (OUT)

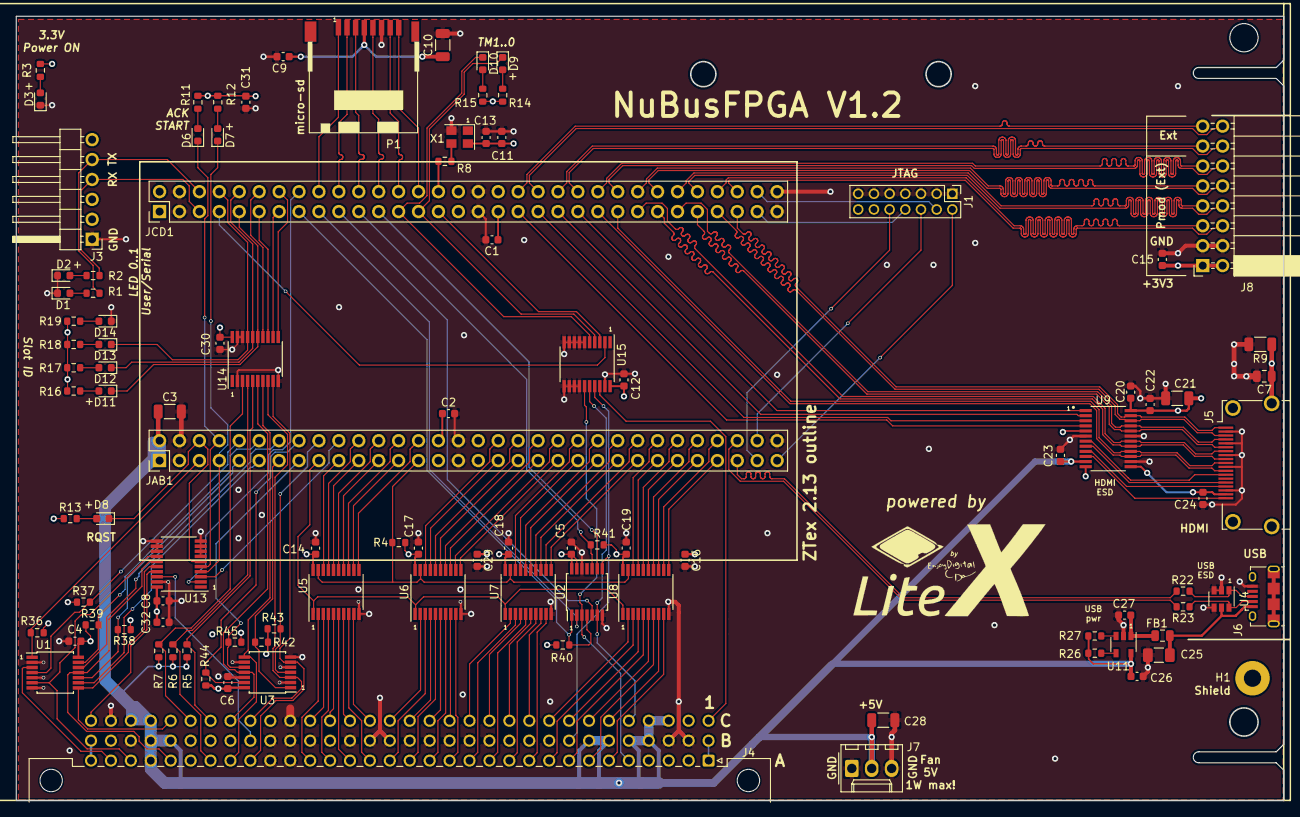
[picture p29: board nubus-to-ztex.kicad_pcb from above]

Board: 4 copper layers, 161.6 x 100.0 mm, 103 parts (0 on the bottom side), 184 nets.

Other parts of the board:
C9: 100nF; C_0603_1608Metric

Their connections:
+3V3: C9.1; also elsewhere on the board
GND: C9.2; also elsewhere on the board

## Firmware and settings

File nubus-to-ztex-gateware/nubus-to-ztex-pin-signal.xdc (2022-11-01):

# !!! Constraint files are application specific !!!
# !!!          This is a template only          !!!

# on-board signals

# CLKOUT/FXCLK 
create_clock -name fxclk_in -period 20.833 [get_ports fxclk_in]
set_property PACKAGE_PIN P15 [get_ports fxclk_in]
set_property IOSTANDARD LVCMOS33 [get_ports fxclk_in]

# IFCLK 
#create_clock -name ifclk_in -period 20.833 [get_ports ifclk_in]
#set_property PACKAGE_PIN P17 [get_ports ifclk_in]
#set_property IOSTANDARD LVCMOS33 [get_ports ifclk_in]

set_property CONFIG_VOLTAGE 3.3 [current_design]
set_property CFGBVS VCCO [current_design]
set_property BITSTREAM.CONFIG.CONFIGRATE 66 [current_design]  
set_property BITSTREAM.CONFIG.SPI_32BIT_ADDR No [current_design]
set_property BITSTREAM.CONFIG.SPI_BUSWIDTH 2 [current_design]
set_property BITSTREAM.GENERAL.COMPRESS true [current_design]


# set_property PACKAGE_PIN  [get_ports {}]
# set_property IOSTANDARD LVTTL [get_ports {}]

#### AB
# AB TOP LEFT (12)
set_property PACKAGE_PIN K16 [get_ports {nmrq_n}]
set_property PACKAGE_PIN K15 [get_ports {start_n}]
set_property PACKAGE_PIN J15 [get_ports {start_oe_n}]
set_property PACKAGE_PIN H15 [get_ports {start_o_n}]
set_property PACKAGE_PIN J14 [get_ports {arb_o_n[0]}]
set_property PACKAGE_PIN H17 [get_ports {arb_o_n[3]}]
set_property PACKAGE_PIN G17 [get_ports {nubus_ad_dir}]
set_property PACKAGE_PIN G18 [get_ports {ad_n[31]}]
set_property PACKAGE_PIN F18 [get_ports {ad_n[29]}]
set_property PACKAGE_PIN E18 [get_ports {ad_n[27]}]
set_property PACKAGE_PIN D18 [get_ports {ad_n[25]}]
set_property PACKAGE_PIN G13 [get_ports {nubus_oe}]

# AB BOTTOM LEFT (13)
set_property PACKAGE_PIN F13 [get_ports {ad_n[23]}]
set_property PACKAGE_PIN E16 [get_ports {ad_n[21]}]
set_property PACKAGE_PIN C17 [get_ports {ad_n[19]}]
set_property PACKAGE_PIN A18 [get_ports {ad_n[17]}]
set_property PACKAGE_PIN C15 [get_ports {ad_n[15]}]
set_property PACKAGE_PIN B17 [get_ports {ad_n[13]}]
set_property PACKAGE_PIN C14 [get_ports {ad_n[11]}]
set_property PACKAGE_PIN D13 [get_ports {ad_n[9]}]
set_property PACKAGE_PIN A16 [get_ports {ad_n[7]}]
set_property PACKAGE_PIN B14 [get_ports {ad_n[5]}]
set_property PACKAGE_PIN B12 [get_ports {ad_n[3]}]
set_property PACKAGE_PIN A14 [get_ports {ad_n[1]}]
set_property PACKAGE_PIN B11 [get_ports {usbh0_p}]

# AB TOP RIGHT (12)
set_property PACKAGE_PIN J18 [get_ports {rqst_n}]
set_property PACKAGE_PIN J17 [get_ports {ack_n}]
set_property PACKAGE_PIN K13 [get_ports {rsqt_o_n}]
set_property PACKAGE_PIN J13 [get_ports {ack_oe_n}]
set_property PACKAGE_PIN H14 [get_ports {ack_o_n}]
set_property PACKAGE_PIN G14 [get_ports {arb_o_n[2]}]
set_property PACKAGE_PIN G16 [get_ports {arb_o_n[1]}]
set_property PACKAGE_PIN H16 [get_ports {clk_n}]
set_property PACKAGE_PIN F16 [get_ports {ad_n[30]}]
set_property PACKAGE_PIN F15 [get_ports {ad_n[28]}]
set_property PACKAGE_PIN E17 [get_ports {ad_n[26]}]
set_property PACKAGE_PIN D17 [get_ports {ad_n[24]}]

# AB BOTTOM RIGHT (13)
set_property PACKAGE_PIN F14 [get_ports {ad_n[22]}]
set_property PACKAGE_PIN E15 [get_ports {ad_n[20]}]
set_property PACKAGE_PIN C16 [get_ports {ad_n[18]}]
set_property PACKAGE_PIN B18 [get_ports {ad_n[16]}]
set_property PACKAGE_PIN D15 [get_ports {ad_n[14]}]
set_property PACKAGE_PIN B16 [get_ports {ad_n[12]}]
set_property PACKAGE_PIN D14 [get_ports {ad_n[10]}]
set_property PACKAGE_PIN D12 [get_ports {ad_n[8]}]
set_property PACKAGE_PIN A15 [get_ports {ad_n[6]}]
set_property PACKAGE_PIN B13 [get_ports {ad_n[4]}]
set_property PACKAGE_PIN C12 [get_ports {ad_n[2]}]
set_property PACKAGE_PIN A13 [get_ports {ad_n[0]}]
set_property PACKAGE_PIN A11 [get_ports {usbh0_n}]

#### CD
# CD TOP LEFT (13)
set_property PACKAGE_PIN U9 [get_ports {RX}]
set_property PACKAGE_PIN U8 [get_ports {id_n[3]}]
set_property PACKAGE_PIN U7 [get_ports {id_n[0]}]
set_property PACKAGE_PIN U6 [get_ports {arb_n[3]}]
set_property PACKAGE_PIN T8 [get_ports {arb_n[0]}]
set_property PACKAGE_PIN R8 [get_ports {tmx_oe_n}]
set_property PACKAGE_PIN R7 [get_ports {tm_o_n[1]}]
set_property PACKAGE_PIN T6 [get_ports {tm_o_n[0]}]
set_property PACKAGE_PIN R6 [get_ports {tm2_oe_n}]
set_property PACKAGE_PIN R5 [get_ports {tm_o_n[2]}]
set_property PACKAGE_PIN V2 [get_ports {tm_n[1]}]
set_property PACKAGE_PIN U2 [get_ports {tm_n[0]}]
set_property PACKAGE_PIN K6 [get_ports {tm_n[2]}]

# CD BOTTOM LEFT (12)
set_property PACKAGE_PIN N6 [get_ports {hdmi_hpd_a}]
set_property PACKAGE_PIN M6 [get_ports {hdmi_sda_a}]
set_property PACKAGE_PIN L6 [get_ports {hdmi_scl_a}]
set_property PACKAGE_PIN L5 [get_ports {hdmi_cec_a}]
set_property PACKAGE_PIN N4 [get_ports {hdmi_clk_n}]
set_property PACKAGE_PIN M4 [get_ports {hdmi_clk_p}]
set_property PACKAGE_PIN M3 [get_ports {hdmi_d0_p}]
set_property PACKAGE_PIN M2 [get_ports {hdmi_d0_n}]
set_property PACKAGE_PIN K5 [get_ports {hdmi_d1_p}]
set_property PACKAGE_PIN L4 [get_ports {hdmi_d1_n}]
set_property PACKAGE_PIN L3 [get_ports {hdmi_d2_n}]
set_property PACKAGE_PIN K3 [get_ports {hdmi_d2_p}]
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

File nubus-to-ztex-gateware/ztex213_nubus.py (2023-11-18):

#
# This file is part of LiteX-Boards.
#
# Support for the ZTEX USB-FGPA Module 2.13:
# <https://www.ztex.de/usb-fpga-2/usb-fpga-2.13.e.html>
# With (no-so-optional) expansion, either the ZTEX Debug board:
# <https://www.ztex.de/usb-fpga-2/debug.e.html>
# Or the NuBusFPGA adapter board:
# <https://github.com/rdolbeau/NuBusFPGA>
#
# Copyright (c) 2015 Yann Sionneau <yann.sionneau@gmail.com>
# Copyright (c) 2015-2019 Florent Kermarrec <florent@enjoy-digital.fr>
# Copyright (c) 2020-2021 Romain Dolbeau <romain@dolbeau.org>
# SPDX-License-Identifier: BSD-2-Clause

from litex.build.generic_platform import *
from litex.build.xilinx import XilinxPlatform
from litex.build.openocd import OpenOCD

from VintageBusFPGA_Common.ztex_21x_common import ZTexPlatform

# IOs ----------------------------------------------------------------------------------------------

# NuBusFPGA I/O

# I/O
_nubus_io_v1_0 = [
    ## leds on the NuBus board
    ("user_led", 0, Pins("V5"),  IOStandard("lvcmos33")), #LED0
    ("user_led", 1, Pins("V4"),  IOStandard("lvcmos33")), #LED1
    ## serial header for console
    ("serial", 0,
     Subsignal("tx", Pins("V9")), # FIXME: might be the other way round
     Subsignal("rx", Pins("U9")),
     IOStandard("LVCMOS33")
    ),
    ## USB
    ("usb", 0,
     Subsignal("dp", Pins("B11")),
     Subsignal("dm", Pins("A11")),
     IOStandard("LVCMOS33")
    ),
    ## VGA
    ("vga", 0,
     Subsignal("clk", Pins("K6")),
     Subsignal("hsync", Pins("U4")),
     Subsignal("vsync", Pins("U3")),
     Subsignal("b", Pins("M2 M3 M4 N4 L5 L6 M6 N6")),
     Subsignal("g", Pins("N2 N1 M1 L1 K3 L3 L4 K5")),
     Subsignal("r", Pins("P5 N5 P4 P3 T1 R1 R2 P2")),
     IOStandard("LVCMOS33"),
    ),
    # HDMI
    ("hdmi", 0,
        Subsignal("clk_p",   Pins("R6"), IOStandard("TMDS_33")),
        Subsignal("clk_n",   Pins("R5"), IOStandard("TMDS_33")),
        Subsignal("data0_p", Pins("U1"), IOStandard("TMDS_33")),
        Subsignal("data0_n", Pins("V1"), IOStandard("TMDS_33")),
        Subsignal("data1_p", Pins("U2"), IOStandard("TMDS_33")),
        Subsignal("data1_n", Pins("V2"), IOStandard("TMDS_33")),
        Subsignal("data2_p", Pins("R3"), IOStandard("TMDS_33")),
        Subsignal("data2_n", Pins("T3"), IOStandard("TMDS_33")),
        Subsignal("hpd",     Pins("T8"), IOStandard("LVCMOS33")),
        Subsignal("sda",     Pins("R8"), IOStandard("LVCMOS33")),
        Subsignal("scl",     Pins("R7"), IOStandard("LVCMOS33")),
        Subsignal("cec",     Pins("T6"), IOStandard("LVCMOS33")),
    ),
    ]

_nubus_io_v1_2 = [
    ## extra 54 MHz clock reference for bank 34
    ("clk54", 0, Pins("R3"), IOStandard("LVCMOS33")),
    ## leds on the NuBus board
    ("user_led", 0, Pins("V9"),  IOStandard("lvcmos33")), #LED0
    ("user_led", 1, Pins("U9"),  IOStandard("lvcmos33")), #LED1; both are overlapping with serial TX/RX
    ## serial header for console
    ("serial", 0,
     Subsignal("tx", Pins("V9")), # FIXME: might be the other way round
     Subsignal("rx", Pins("U9")), # both are overlapping with LED0/1
     IOStandard("LVCMOS33")
    ),
    ## USB
    ("usb", 0,
     Subsignal("dp", Pins("B11")),
     Subsignal("dm", Pins("A11")),
     IOStandard("LVCMOS33")
    ),
    ## HDMI
    ("hdmi", 0,
        Subsignal("clk_p",   Pins("M4"), IOStandard("TMDS_33")),
        Subsignal("clk_n",   Pins("N4"), IOStandard("TMDS_33")),
        Subsignal("data0_p", Pins("M3"), IOStandard("TMDS_33")),
        Subsignal("data0_n", Pins("M2"), IOStandard("TMDS_33")),
        Subsignal("data1_p", Pins("K5"), IOStandard("TMDS_33")),
        Subsignal("data1_n", Pins("L4"), IOStandard("TMDS_33")),
        Subsignal("data2_p", Pins("K3"), IOStandard("TMDS_33")),
        Subsignal("data2_n", Pins("L3"), IOStandard("TMDS_33")),
        Subsignal("hpd",     Pins("N6"), IOStandard("LVCMOS33")),
        Subsignal("sda",     Pins("M6"), IOStandard("LVCMOS33")),
        Subsignal("scl",     Pins("L6"), IOStandard("LVCMOS33")),
        Subsignal("cec",     Pins("L5"), IOStandard("LVCMOS33")),
    ),
    ## micro-sd
    ("sdcard", 0,
        Subsignal("data", Pins("U1 T3 T4 U4"), Misc("PULLUP True")),
        Subsignal("cmd",  Pins("U3"), Misc("PULLUP True")),
        Subsignal("clk",  Pins("V1")),
        #Subsignal("cd",   Pins("")),
        Misc("SLEW=FAST"),
        IOStandard("LVCMOS33"),
    ),
    ]

# NuBus
_nubus_nubus_v1_0 = [
    ("clk_3v3_n",          0, Pins("H16"), IOStandard("lvttl")),
    ("clk2x_3v3_n",        0, Pins("T5"),  IOStandard("lvttl")),
    ("ack_3v3_n",          0, Pins("K13"), IOStandard("lvttl")),
    ("nmrq_3v3_n",         0, Pins("J18"), IOStandard("lvttl")),
    ("reset_3v3_n",        0, Pins("G17"), IOStandard("lvttl")),
    ("rqst_3v3_n"  ,       0, Pins("K16"), IOStandard("lvttl")),
    ("start_3v3_n",        0, Pins("J15"), IOStandard("lvttl")),
    ("ad_3v3_n",           0, Pins("A13 A14 C12 B12 B13 B14 A15 A16 "
                                   "D12 D13 D14 C14 B16 B17 D15 C15 "
                                   "B18 A18 C16 C17 E15 E16 F14 F13 "
                                   "D17 D18 E17 E18 F15 F18 F16 G18 "), IOStandard("lvttl")),
    # ("nubus_arb_n",        0, Pins(""), IOStandard("lvttl")), # CPLD only, we have 'arbcy_n'/'grant' instead
    ("id_3v3_n",           0, Pins("U7 V6 V7 U8"), IOStandard("lvttl")),
    ("tm0_3v3_n",          0, Pins("K15"), IOStandard("lvttl")),
    ("tm1_3v3_n",          0, Pins("J17"), IOStandard("lvttl")),
    ("tm2_3v3_n",          0, Pins("T4"),  IOStandard("lvttl")),
    
    ("nubus_oe",           0, Pins("G13"), IOStandard("lvttl")),
    ("nubus_ad_dir",       0, Pins("G16"), IOStandard("lvttl")),
    ("nubus_master_dir",   0, Pins("H17"), IOStandard("lvttl")),
    ("grant",              0, Pins("H15"), IOStandard("lvttl")),
    ("arbcy_n",            0, Pins("J13"), IOStandard("lvttl")), # arb in the schematics
    ("fpga_to_cpld_clk",   0, Pins("H14"), IOStandard("lvttl")),
    ("tmoen",              0, Pins("U6"),  IOStandard("lvttl")),
    ("fpga_to_cpld_signal",0, Pins("J14"), IOStandard("lvttl")),
    ("fpga_to_cpld_signal_2",0, Pins("G14"), IOStandard("lvttl")),
]
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

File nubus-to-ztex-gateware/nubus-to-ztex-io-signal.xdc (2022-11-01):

set_property IOSTANDARD LVTTL [get_ports {PMOD10}]
set_property IOSTANDARD LVTTL [get_ports {PMOD11}]
set_property IOSTANDARD LVTTL [get_ports {PMOD12}]
set_property IOSTANDARD LVTTL [get_ports {PMOD5}]
set_property IOSTANDARD LVTTL [get_ports {PMOD6}]
set_property IOSTANDARD LVTTL [get_ports {PMOD7}]
set_property IOSTANDARD LVTTL [get_ports {PMOD8}]
set_property IOSTANDARD LVTTL [get_ports {PMOD9}]
set_property IOSTANDARD LVTTL [get_ports {RX}]
set_property IOSTANDARD LVTTL [get_ports {SD_CLK}]
set_property IOSTANDARD LVTTL [get_ports {SD_CMD}]
set_property IOSTANDARD LVTTL [get_ports {SD_D0}]
set_property IOSTANDARD LVTTL [get_ports {SD_D1}]
set_property IOSTANDARD LVTTL [get_ports {SD_D2}]
set_property IOSTANDARD LVTTL [get_ports {SD_D3}]
set_property IOSTANDARD LVTTL [get_ports {TX}]
set_property IOSTANDARD LVTTL [get_ports {ack_n}]
set_property IOSTANDARD LVTTL [get_ports {ack_o_n}]
set_property IOSTANDARD LVTTL [get_ports {ack_oe_n}]
set_property IOSTANDARD LVTTL [get_ports {ad_n[0]}]
set_property IOSTANDARD LVTTL [get_ports {ad_n[10]}]
set_property IOSTANDARD LVTTL [get_ports {ad_n[11]}]
set_property IOSTANDARD LVTTL [get_ports {ad_n[12]}]
set_property IOSTANDARD LVTTL [get_ports {ad_n[13]}]
set_property IOSTANDARD LVTTL [get_ports {ad_n[14]}]
set_property IOSTANDARD LVTTL [get_ports {ad_n[15]}]
set_property IOSTANDARD LVTTL [get_ports {ad_n[16]}]
set_property IOSTANDARD LVTTL [get_ports {ad_n[17]}]
set_property IOSTANDARD LVTTL [get_ports {ad_n[18]}]
set_property IOSTANDARD LVTTL [get_ports {ad_n[19]}]
set_property IOSTANDARD LVTTL [get_ports {ad_n[1]}]
set_property IOSTANDARD LVTTL [get_ports {ad_n[20]}]
set_property IOSTANDARD LVTTL [get_ports {ad_n[21]}]
set_property IOSTANDARD LVTTL [get_ports {ad_n[22]}]
set_property IOSTANDARD LVTTL [get_ports {ad_n[23]}]
set_property IOSTANDARD LVTTL [get_ports {ad_n[24]}]
set_property IOSTANDARD LVTTL [get_ports {ad_n[25]}]
set_property IOSTANDARD LVTTL [get_ports {ad_n[26]}]
set_property IOSTANDARD LVTTL [get_ports {ad_n[27]}]
set_property IOSTANDARD LVTTL [get_ports {ad_n[28]}]
set_property IOSTANDARD LVTTL [get_ports {ad_n[29]}]
set_property IOSTANDARD LVTTL [get_ports {ad_n[2]}]
set_property IOSTANDARD LVTTL [get_ports {ad_n[30]}]
set_property IOSTANDARD LVTTL [get_ports {ad_n[31]}]
set_property IOSTANDARD LVTTL [get_ports {ad_n[3]}]
set_property IOSTANDARD LVTTL [get_ports {ad_n[4]}]
set_property IOSTANDARD LVTTL [get_ports {ad_n[5]}]
set_property IOSTANDARD LVTTL [get_ports {ad_n[6]}]
set_property IOSTANDARD LVTTL [get_ports {ad_n[7]}]
set_property IOSTANDARD LVTTL [get_ports {ad_n[8]}]
set_property IOSTANDARD LVTTL [get_ports {ad_n[9]}]
set_property IOSTANDARD LVTTL [get_ports {arb_n[0]}]
set_property IOSTANDARD LVTTL [get_ports {arb_n[1]}]
set_property IOSTANDARD LVTTL [get_ports {arb_n[2]}]
set_property IOSTANDARD LVTTL [get_ports {arb_n[3]}]
set_property IOSTANDARD LVTTL [get_ports {arb_o_n[0]}]
set_property IOSTANDARD LVTTL [get_ports {arb_o_n[1]}]
set_property IOSTANDARD LVTTL [get_ports {arb_o_n[2]}]
set_property IOSTANDARD LVTTL [get_ports {arb_o_n[3]}]
set_property IOSTANDARD LVTTL [get_ports {clk2x_n}]
set_property IOSTANDARD LVTTL [get_ports {clk_n}]
set_property IOSTANDARD LVTTL [get_ports {hdmi_cec_a}]
set_property IOSTANDARD LVTTL [get_ports {hdmi_clk_n}]
set_property IOSTANDARD LVTTL [get_ports {hdmi_clk_p}]
set_property IOSTANDARD LVTTL [get_ports {hdmi_d0_n}]
set_property IOSTANDARD LVTTL [get_ports {hdmi_d0_p}]
set_property IOSTANDARD LVTTL [get_ports {hdmi_d1_n}]
set_property IOSTANDARD LVTTL [get_ports {hdmi_d1_p}]
set_property IOSTANDARD LVTTL [get_ports {hdmi_d2_n}]
set_property IOSTANDARD LVTTL [get_ports {hdmi_d2_p}]
set_property IOSTANDARD LVTTL [get_ports {hdmi_hpd_a}]
set_property IOSTANDARD LVTTL [get_ports {hdmi_scl_a}]
set_property IOSTANDARD LVTTL [get_ports {hdmi_sda_a}]
set_property IOSTANDARD LVTTL [get_ports {id_n[0]}]
set_property IOSTANDARD LVTTL [get_ports {id_n[1]}]
set_property IOSTANDARD LVTTL [get_ports {id_n[2]}]
set_property IOSTANDARD LVTTL [get_ports {id_n[3]}]
set_property IOSTANDARD LVTTL [get_ports {led[0]}]
set_property IOSTANDARD LVTTL [get_ports {led[1]}]
set_property IOSTANDARD LVTTL [get_ports {led[2]}]
set_property IOSTANDARD LVTTL [get_ports {led[3]}]
set_property IOSTANDARD LVTTL [get_ports {nmrq_n}]
set_property IOSTANDARD LVTTL [get_ports {nubus_ad_dir}]
set_property IOSTANDARD LVTTL [get_ports {nubus_oe}]
set_property IOSTANDARD LVTTL [get_ports {reset_n}]
set_property IOSTANDARD LVTTL [get_ports {rqst_n}]
set_property IOSTANDARD LVTTL [get_ports {rsqt_o_n}]
set_property IOSTANDARD LVTTL [get_ports {start_n}]
set_property IOSTANDARD LVTTL [get_ports {start_o_n}]
set_property IOSTANDARD LVTTL [get_ports {start_oe_n}]
set_property IOSTANDARD LVTTL [get_ports {tm2_oe_n}]
set_property IOSTANDARD LVTTL [get_ports {tm_n[0]}]
set_property IOSTANDARD LVTTL [get_ports {tm_n[1]}]
set_property IOSTANDARD LVTTL [get_ports {tm_n[2]}]
set_property IOSTANDARD LVTTL [get_ports {tm_n_o[0]}]
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

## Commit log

2021-12-21 push to github
    [10029449-111RLF.stp, 1050170001.stp, 676432911.stp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]
2022-01-09 large update
    [B2B.sch, fan.sch, hdmi.sch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]
2022-01-09 another update after discussion on tinkerdifferent
    [B2B.sch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]
2022-01-09 Switch from 5V 74FCT245 to 3.3V 74LVT245
    [nubus-to-ztex-B.Cu.gbr, nubus-to-ztex-Edge.Cuts.gbr, nubus-to-ztex-F.Cu.gbr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]
2022-01-15 large clean-up update
    [B2B.sch, fan.sch, hdmi.sch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]
2022-01-29 more updates
    [nubus-to-ztex-B.Cu.gbr, nubus-to-ztex-Edge.Cuts.gbr, nubus-to-ztex-F.Cu.gbr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]
2022-02-05 some missing stuff, minor HW update, SW
    [hdmi.sch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]
2022-04-17 update to first tested version
    [1727034_seeed_dfareporta172464820220211.xlsx, N2Z_backplate.scad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]
2022-04-19 C secondary, add rsrc directory w/o assembly
2022-06-04 DMA debug with XiBus NuBus & add alternate Migen implementation of NuBus
2022-06-05 commit current Vex config
2022-06-06 draft non-synchronous NuBus (using sampling at sysclk to cut down on latency), minimalist support for 1/2/4 accel
2022-06-07 in _sampling, map whole SDRAm in superslot and use the first 248 Mib as a RAM disk with driver in the DeclRom
2022-06-12 use some custom RLE to initiliaze the RAM disk with a valid HFS FS. Still doesn't mount at boot though.
2022-06-26 detect slot in INIT; detect slot in RAMDsk driver ; auto-mount RAMDDsk
2022-06-26 checking in slot
2022-07-14 fix messed up timing...
    [signals.xlsx]
2022-07-14 preliminary burst support for DMA
2022-07-23 trying to debug DMA for RAMDsk
2022-09-11 track HW changes
2022-09-21 disable leds
2022-09-21 'de' reaches the PHY, so add inframe to cover the whole screen and stabilize the windowboxed modes
2022-10-01 try to get DMA to work in the ramdsk driver
2022-10-05 Remove ASM glue in driver table ; replace asm funciton MyaAddDrive by C version
2022-10-08 refactor ram dsk driver a bit more, some work toward multiplexed interrupt
2022-10-08 DMA + IRQ for RAM Disk
2022-11-01 drop vga
    [B2B.sch, nubus-to-ztex.kicad_pcb, vga.sch]
2022-11-01 forgot to commit last attempt at V1.2
    [B2B.sch, fan.sch, hdmi.sch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]
2022-11-01 more stuff thinking about V1.2
    [nubus-to-ztex.kicad_pcb, nubus.sch]
2022-11-01 cleanups, alternative MPN for 2x32 headers (TBC)
    [B2B.sch, hdmi.sch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]
2022-11-01 unused footprint for testing alternate MPN
2022-11-01 reinstate some useful debug LEDs
    [B2B.sch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]
2022-11-01 cut down brightness of LEDs, more 2x32 pin headers reference
    [B2B.sch, fan.sch, hdmi.sch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]
2022-11-01 simplify BoM
    [nubus-to-ztex-B.Cu.gbr, nubus-to-ztex-B.Mask.gbr, nubus-to-ztex-B.Paste.gbr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]
2022-11-01 move shielding to hdmi, trace cleanup
    [B2B.sch, fan.sch, hdmi.sch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]
2022-11-01 update everything
    [B2B.sch, fan.sch, hdmi.sch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]
2022-11-12 more JTAG from TH to SMD
    [87832-1420.stp, B2B.sch, nubus-to-ztex.csv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]
2022-11-12 more update to V1.2 to try to limit cost
    [B2B.sch, fan.sch, hdmi.sch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]
2022-11-12 full BOM
    [nubus-to-ztex-B_Cu.gbr, nubus-to-ztex-B_Mask.gbr, nubus-to-ztex-B_Paste.gbr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]
2022-11-12 rounded cutouts...
    [nubus-to-ztex-B_Cu.gbr, nubus-to-ztex-B_Mask.gbr, nubus-to-ztex-B_Paste.gbr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]
2022-11-13 more THT->SMT, lexx expensive parts/assembly (?)
    [B2B.sch, SAMTEC-SMH-108-02-X-D.step, TSM-106-01-L-SH.step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]
2022-11-18 minor cleanups
    [B2B.sch, hdmi.sch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]
2022-12-01 BoM, power plane, serial back to THT, ...
    [B2B.sch, fan.sch, hdmi.sch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]
2022-12-01 Smaller via, greater power/gnd clearance
    [nubus-to-ztex.kicad_pcb]
2023-01-14 track V1.2 pcb update
2023-03-18 some BoM optimization
    [B2B.sch, clock.sch, hdmi.sch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]
2023-03-18 more JLCPCB BoM optimization
    [DM3CS-SF.step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]
2023-03-26 even more JLCPCB BoM optimization
    [B2B.sch, fan.sch, hdmi.sch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]
2023-04-02 double checking details
    [nubus-to-ztex-B_Cu.gbr, nubus-to-ztex-B_Mask.gbr, nubus-to-ztex-B_Paste.gbr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]
2023-04-04 minor changes in BoM
    [nubus-to-ztex-B_Cu.gbr, nubus-to-ztex-B_Mask.gbr, nubus-to-ztex-B_Paste.gbr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]
2023-04-04 more Silk
    [nubus-to-ztex-B_Cu.gbr, nubus-to-ztex-B_Mask.gbr, nubus-to-ztex-B_Paste.gbr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]
2023-04-04 add sample CW project in SIT file for audio
2023-11-18 move some of board platform stuff to common
2024-02-17 'alt' hdmi from framebuffer, ROM config from gateware, settable pixel clock for non-alt hdmi
2024-05-18 board-based name

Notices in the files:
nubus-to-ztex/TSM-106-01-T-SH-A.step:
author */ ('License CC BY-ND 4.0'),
